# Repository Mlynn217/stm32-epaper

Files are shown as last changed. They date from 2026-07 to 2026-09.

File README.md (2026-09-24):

# stm32-epaper

An STM32-based e-reader using the Waveshare 6inch HD e-Paper HAT (IT8951 controller).

## Current Status

**Reads a real EPUB off an SD card and renders actual book pages on the physical panel.** On real
hardware, confirmed working end to end:
- STM32CubeMX → CMake → arm-none-eabi-gcc/Ninja → OpenOCD → ST-LINK build/flash/debug loop, from
  inside VSCode (tasks + launch configs for build, flash, debug, and a serial monitor)
- SPI1 communication with the IT8951 (panel resolution/FW/LUT version read back correctly, this
  panel's VCOM `-2.59V` set), the FMC/SDRAM (16MB, full read/write test passes), full-panel GC16
  grayscale refresh, and A2 (fast black/white-only partial refresh) mode
- **SD card storage** — SDIO+FatFS mount/read/write, a directory listing on every boot, and long
  filename support (`_USE_LFN=3`, heap-based — see TODO.md for why not `1`/`2`)
- **Fonts and page layout** — anti-aliased proportional bitmap fonts at reading-appropriate sizes
  (generated from a real TTF via `tools/gen_font.py`, not the tiny fixed-width fonts a low-res TFT
  would use), word-wrap, and pagination (a continuation-pointer API that can paginate arbitrarily
  long text one screen at a time without holding more than one page in memory)
- **An EPUB reader** (`Drivers/Epub/`, `Drivers/Inflate/`) — a minimal ZIP reader, a vendored
  reference DEFLATE decompressor, and tiny XML/HTML helpers, enough to parse `container.xml` → the
  OPF's manifest/spine → a chapter's XHTML → clean plain text, fed straight into the page-layout
  pipeline above. Validated against a real book (a purchased copy of *Mistborn: Secret History*) —
  see TODO.md for the debugging story, including a real FatFs/SDIO stale-read bug found and worked
  around along the way

Not done yet — see [TODO.md](TODO.md) for the full list, but the near-term highlights:
- No page-turn/chapter-navigation UI yet (currently auto-picks the first chapter with real text and
  shows up to 4 pages of it); no physical input handling
- Power management/battery life not started
- Custom PCB: the **v1 schematic is drafted in full** in `hardware/kicad/` (Power, MCU, Memory and
  Peripherals sheets). It's ERC-clean and machine-checked (pin mux, nets, footprint pads), but not
  yet reviewed by a person, and there's no PCB layout yet. v1 scope: the Waveshare HAT stays
  external on an SPI connector (see [Custom PCB (Planned)](#custom-pcb-planned))
- Custom PCB layout **started**: `hardware/kicad/stm32-epaper.kicad_pcb` has the enclosure-derived
  outline, every footprint with its nets, and the enclosure-fixed parts placed; core placement and
  routing are next. The side-wall electrode board (`hardware/electrode/`) is fully laid out and
  DRC-clean
- Enclosure: a **v0 parametric draft** in `hardware/enclosure/` (build123d). It passes its own fit
  checks and exports STEP/STL/3MF, but several dimensions are still placeholders and nothing has
  been printed (see [Enclosure](#enclosure-v0-draft))
- No license chosen yet

## Overview

Goal: a standalone, **handheld, Kindle-style** e-reader built around Waveshare's
[6inch HD e-Paper HAT](https://www.waveshare.com/6inch-hd-e-paper-hat.htm) (1448×1072, 16-level
grayscale, IT8951 controller), driven by an STM32 host. The Discovery board is a bring-up platform;
the end goal is a custom PCB — see [Custom PCB (Planned)](#custom-pcb-planned) below for the current
draft of hardware decisions for that board.

**Phase 1 host: STM32F469I-DISCO.** It has its own onboard RGB LCD, but that's not why it was
picked — it's the FMC-attached SDRAM that matters. The IT8951 needs a host-side frame buffer too
large for any STM32's internal SRAM, which is exactly why Waveshare's own reference design pairs
the IT8951 with an STM32F429 board (Open429I) that has external SDRAM bolted on. The F469-Disco
already has SDRAM on the FMC bus (normally used for its own LCD), so we get that requirement for
free. It's a bring-up/development platform for proving out the driver and architecture — the final
product host may end up being a smaller, lower-power part once the design is proven.

## Hardware

### Display: Waveshare 6inch HD e-Paper HAT

- Panel: 6", 1448×1072, black/white, 16 grayscale levels (1–4 bpp)
- Controller: IT8951 (on the HAT/driver board)
- Full refresh: <1s. Refresh power ~0.6W typ, standby ~0.3W typ
- Host interface options: SPI / I80 (parallel) / I2C / USB (USB requires an NDA with Waveshare —
  not an option for us)
- **Using SPI** — Waveshare's own recommendation ("fewer pins, easy to use"). I80 is faster but
  needs 16 data pins plus control lines, which would compete with the Discovery board's other
  onboard peripherals; I2C is too slow for meaningful refresh rates.
- Operating voltage: 5V
- Outline: 138.4×101.8×0.67mm; active display area: 122.356×90.584mm
- Viewing angle: >170°; operating temp 0–50°C, storage -25–70°C
- Each physical panel has a unique **VCOM** value printed on its FPC cable that must be set in
  firmware for correct grayscale/contrast. **This panel's VCOM is `-2.59V`** → pass `2590` (mV
  magnitude) to `EPD_IT8951_Init()`/`EPD_IT8951_SetVCOM()`.

### Host: STM32F469I-DISCO

- STM32F469NIH6 — Cortex-M4F, 2MB flash, 384KB internal SRAM
- FMC-attached SDRAM onboard (normally the framebuffer for the board's own RGB LCD) — repurposed
  here as the IT8951 frame buffer
- Onboard ST-LINK/V2-1 — no external debug probe needed

### Wiring

Final pin assignment for the F469-Disco, chosen by checking every candidate pin against the MCU's
full alternate-function list and cross-referencing everything already enabled in the `.ioc` (FMC,
DSIHOST/LTDC, I2C1/2, SAI1, SDIO, QUADSPI, USART3/6, USB_OTG_FS, TIM1) — no conflicts:

| IT8951 HAT pin | Signal | STM32 pin | Discovery connector | Pin # | Silkscreen label | Wire color |
|---|---|---|---|---|---|---|
| 5V | Power | — | CN6 (Arduino Power) | 5 | `+5V` | Grey |
| GND | Ground | — | CN6 (Arduino Power) | 6/7 | `GND` | Black |
| SCK | SPI1_SCK | PA5 | CN12 (Extension header)  | 7 | — | Orange |
| MISO | SPI1_MISO | PB4 | CN12 (Extension header)  | 5 | — | Blue |
| MOSI | SPI1_MOSI | PB5 | CN12 (Extension header)  | 9 | — | Yellow |
| CS | GPIO_Output, PP, idle high | PA4 | CN8 (Arduino Analog) | 6 | `A5` | Green |
| RST | GPIO_Output, PP, idle high | PB1 | CN8 (Arduino Analog) | 1 | `A0` | White |
| HRDY (busy) | GPIO_Input | PA2 | CN7 (Arduino Digital) | 6 | `D5` | Purple |

Notes:
- SPI1's SCK/MISO/MOSI are only broken out on **CN12**, the 16-pin 2.54mm extension header on the
  underside of the board — not on the Arduino headers. CS/RST/HRDY are split across CN8 and CN7
  instead, so wiring the HAT means jumpers from three different connectors plus CN6, not one.
- CN8 pin 6 (`A5`) defaults to PA4 via solder bridges SB10/SB12 (closed by default) — worth a
  continuity check with a multimeter before trusting it, since those can be reconfigured.
- CS/RST are push-pull, idle **high** (both signals are active-low on the IT8951 side — CS is only
  pulled low during a transaction, RST is only pulsed low as a deliberate reset, driven by the
  driver's init code rather than left low by default).
- SPI1 clock: **11.25 MHz** (APB2/8 off a 90MHz APB2 clock). The IT8951's datasheet (Table 9-4, SPI
  AC Characteristics) caps `fSCLK` at 24MHz; 11.25MHz leaves comfortable margin for jumper-wire
  wiring rather than a tightly-routed PCB. `hspi1.Init.BaudRatePrescaler` in `Core/Src/main.c` and
  `SPI1.CalculateBaudRate` in the `.ioc` are both set to match.
- HRDY (busy) is active-low (low = busy). All three IT8951-side GPIOs are currently `GPIO_NOPULL`
  (no pull-up/down) — a defensive pull-up was considered for the brief post-reset window before
  `MX_GPIO_Init()` runs, but wasn't applied; not required since these are actively driven once init
  runs, just an optional safety margin if boot-order issues ever show up.

## Custom PCB (Planned)

In progress. The KiCad project is in `hardware/kicad/`, and the **v1 schematic is drafted in full**:
Power, MCU, Memory and Peripherals sheets. PCB layout is next (see TODO.md). These are the
**current draft hardware decisions**, recorded here so context isn't lost between sessions. They're still open to change
while the schematic takes shape. The Discovery board plus the Waveshare HAT above stays the bring-up
platform until the PCB is built.

**Board scope (decided 2026-09-22):**
- **v1 PCB:** power, MCU, memory, navigation/input and the other peripherals. The **Waveshare
  IT8951 HAT stays an external module**, connected over an SPI connector, with the board supplying
  its 5 V.
- **Deferred to a later revision:** a bare IT8951 IC with its own panel PMIC (see
  [Display](#display) for what that involves).

### Input System

| Control | Component | Interface | Notes |
|---|---|---|---|
| Prev / Next page | CAP1188-1-SL (Microchip) | I²C + ALERT interrupt | 8-channel; side-wall electrodes |
| Side-wall electrodes | 2 small electrode boards (0.8 mm FR4), 2 pads each | JST-SH cable per side (J302/J303) | Pads pressed against the inside of each side wall; plastic wall as dielectric (up to ~4mm) |
| Library / menu scroll | Bourns PEC11R-4220F-S0024 | 2× GPIO (A, B quadrature) | 24 detents / 24 pulses per revolution, 20mm flatted shaft (the M7 bushing leaves too little of a 15mm shaft for the knob to grip through the front face; the Discovery bring-up used the 15mm -4215F) |
| Confirm / select | Encoder push | 1× GPIO (SW) | Built into the PEC11R (the "S" in S0024) |
| Power / wake | Alps SKRTLAE010 side-actuated tact switch | 1× GPIO (WKUP pin) | Bottom edge, on the main PCB, pressed through a flexure tab in the wall; physical, not capacitive |

Layout: cap-touch zones on left/right side walls (thumb rest). The encoder knob is on the front
face below the display (the PEC11R is vertical-mount), and the power button is on the bottom edge
next to microSD and USB-C (decided 2026-09-23, see [Enclosure](#enclosure-v0-draft)).

**Considered and set aside (open to revisiting if requirements change):**
- PSP-style analog joystick (COM-09426): analog noise, no click function, and its resistive divider
  draws current continuously, which is wrong for a device that mostly sleeps.
- On-glass bezel capacitive (ITO film): manufacturing complexity; side-wall electrode boards achieve
  the same result more simply.
- Copper tape or a flex strip for the side-wall electrodes: either works, but small rigid boards
  give repeatable pad geometry, can carry ESD parts, and cost pennies in the same PCB order (flex
  is ~10× the price for no benefit here).

### MCU, Memory & Storage

| Component | Part | Interface | Role |
|---|---|---|---|
| MCU | STM32F469IIT6 (LQFP176) | — | Same die as the Disco's F469NI, but a hand-/JLC-assemblable package instead of TFBGA216. Confirm the pin budget (FMC SDRAM + SDIO + QSPI + SPI + I²C + USB) in CubeMX before layout |
| SDRAM | IS42S16400J-6TLI | FMC 16-bit | **64 Mbit = 8 MB** (earlier notes wrongly said 16 MB; that's the Disco's chip). Plenty: ~776 KB frame buffer + the 4 MB text/EPUB buffer. Keep it, because the whole-file-in-RAM FatFs/SDIO workaround depends on it |
| QSPI NOR Flash | W25Q128JV (16 MB) | QSPI | Firmware + fonts. (N25Q128A dropped: Micron's legacy line, superseded by MT25Q) |
| microSD slot | TBD (Molex 1040310811 or GCT MSD-4-A candidates) | SDIO 4-bit | Book library (user-swappable) |

SDRAM is volatile. It does **not** replace storage; book files live on microSD.

### Display

**v1:** the Waveshare 6" HD HAT, off-board on an SPI connector. The HAT takes 5 V (from the
TPS61023 boost) and has 3.3 V SPI logic.

**Later revision: a bare IT8951 IC.** The IT8951 datasheet (`docs/IT8951_D_V0.2.4.3_20170728.pdf`)
shows this is **not** a "just run everything from 3.3 V" change (an earlier note here claimed it
was). It needs:
- **A 1.8 V core supply** (VCCK, VCC18A and VCC_SDR, each 1.8 V ±0.09 V) as well as 3.3 V for I/O and
  analog.
- **A power-up order: 1.8 V stable first, then 3.3 V, then reset released.** A 1.8 V LDO fed
  *from* 3.3 V can't meet that. One fix: feed the LDO from VSYS and switch the IT8951's 3.3 V on
  afterwards with a load switch.
- **A 12 MHz crystal, and its own SPI NOR flash** holding the panel's **waveform file**. The
  waveform is panel-specific and comes from the panel maker; the HAT ships with it in its flash.
  **Getting it is the biggest risk of going bare-IC.**
- **A TPS65185/TPS65186 panel PMIC** with its own inductors, diodes and caps (for VCOM and the
  panel's high voltages), plus the panel FPC connector.
- The IT8951 has **built-in** SDRAM (32 Mb, or 64 Mb on the -64 variants), so it needs no external
  DRAM. It's rated 0–70 °C.

### Power Architecture

**Cell chemistry: 1-cell LiPo pouch (3.7 V nominal, 4.2 V full), with a protection board.**
Switched from LiFePO4 on 2026-09-23. Small, flat LFP pouches turned out to be practically
unobtainable in the US: sample requests to overseas cell makers only. Protected LiPo pouches with
JST-PH 2.0 leads are stocked everywhere (Adafruit, SparkFun, DigiKey). What each chemistry offers:

| | LiFePO4 (previous choice) | LiPo (now) |
|---|---|---|
| Thermal runaway onset | ~270 °C | ~150 °C |
| Cycle life | 2000–3000 | ~300–500 |
| Energy density | lower | ~2× |
| Flat pouches in the US | poor | excellent |
| Discharge curve | flat (voltage says little about charge) | sloped (voltage is a usable fuel estimate) |

The safety gap is handled the way phones and e-readers handle it:
- A protected cell.
- A charger that watches cell temperature through an NTC and refuses to charge outside ~0–50 °C.
- An undervoltage cutoff.
- A sensible enclosure: leave room for the pouch to swell.

~300–500 cycles is still years of use for a reader charged every few weeks.

**Candidate cells (ordered 2026-09-23):** two EEMB protected LiPo packs with JST-PH 2.0 leads.
They share a 34.5 mm × ~52 mm outline and differ only in thickness. Figures come from EEMB's
specs: the [LP963450-PCM-LD pack spec](https://m.media-amazon.com/images/I/81dlwMxaX9L.pdf) (doc
ZJQM-RD-SPC-H1817) and the [LP603449 cell spec](https://www.eemb.com/product-147) (ZJQM-RD-SPC-H0482;
no pack-level sheet found).

| | EEMB LP603449 (pack) | EEMB LP963450-PCM-LD |
|---|---|---|
| Capacity | 1100 mAh (1000 min) | 1800 mAh (1700 min) |
| Pack envelope (max) | 6.3 × 34.5 × ~52 mm (cell body 50 mm; +PCM assumed as on the 963450) | **9.9 × 34.5 × 52 mm** |
| Weight | ~22 g | ~36 g |
| Charge | 4.20 V CC/CV, max 1C (1100 mA) | 4.2 V CC/CV, max 1C (1800 mA) |
| **Cold charging** | assumed as 963450 | **0–20 °C: ≤ 0.3C** |
| Charge temperature | 0–45 °C | 0–45 °C |
| Discharge | max 2C, cell cutoff 2.75 V | max 2C (3.6 A); pack limit 1 A continuous, 2 A for 3 s |
| Protection board (963450 spec) | assumed same family | overcharge 4.28 ± 0.05 V; **over-discharge 3.0 ± 0.1 V** (releases at 3.5 V) |
| Leads | JST-PH 2.0 | red (+) / black (−) UL1007 AWG26, **50 ± 3 mm**, JST PHR-02, from the PCM edge |
| Cycle life | ≥ 500 at 0.5C, ≥ 800 at 0.2C | ≥ 800 (min) |

**How the design fits them:**
- **Charge current:** ~296 mA (265–324 mA worst case), ≤ 0.3C of the smaller cell, so both cells are
  within spec at any charge temperature.
- **Charge timer:** 7.2–12 h, long enough for the 1800 mAh cell.
- **Cutoff order:** hardware cutoff at ~3.20 V, above the protection board's 3.0 V (firmware shuts
  down at ~3.4 V first).
- **Current:** peak draw ~0.7 A, under the pack's 1 A continuous limit.
- **Hot end:** the cells' 45 °C charging limit is handled in firmware (see the Power sheet section).

**Battery bay (enclosure input).** Size the bay for the 963450: **52 × 34.5 × 9.9 mm max, plus
~0.5 mm on each face for swelling**. Use a ~3.6 mm spacer when fitting the LP603449. Other points:
- The PCM strip and the lead exit are on one 34.5 mm edge. The 50 mm lead needs a route to J2 (keep
  J2 within ~40 mm of that edge, or allow slack).
- Keep the pouch clear of sharp edges and screw bosses.
- RT1 (the charger's NTC) is a leaded Murata NXFT15XH103 soldered to pads on the PCB, with its head
  taped to the pouch (the cell sits beside the PCB, not over it).
- **Polarity isn't shown by pin in EEMB's drawings** (only red = +). Check J2 pin 1 = + with a meter
  before plugging a cell in.

**Power tree, v1 (external Waveshare HAT):**
```
USB-C VBUS ──► BQ24073 charger + power path ──► VSYS (4.4V regulated with USB; = cell on battery)
                      └──► LiPo cell (3.0–4.2V)          4.2V CV, NTC-qualified, ~500mA
VSYS ──► TPS63802 buck-boost → 3.3V                        STM32, SDRAM, QSPI, microSD, CAP1188, encoder, buttons
           └── EN = VSYS divider: OFF < ~3.20V, ON > ~3.52V (undervoltage cutoff)
VSYS ──► TPS61023 boost → 5V                               external Waveshare HAT (MCU-enabled)
cell ──► MCP1700 3.0V LDO → MCU VBAT                       RTC backup
cell ──► 1M/1M divider → PA3 (ADC)                         firmware battery measurement
```

**Battery protection (undervoltage).** The charger only charges; it does **nothing** to stop
over-discharge. Protection is layered:
1. **Firmware (primary).** Measure the cell on `VBAT_SENSE` (PA3, 1M/1M divider, ~2 µA). At about
   3.4 V under light load, shut down gracefully: save state, leave a "please charge" screen on the
   e-ink (it holds with no power), then enter standby. LiPo's sloped curve makes this voltage a
   reasonable fuel estimate too.
2. **Hardware backstop.** The TPS63802's EN pin has a precise threshold (1.10 V rising / 1.00 V
   falling). A 2.2 MΩ/1.0 MΩ divider from VSYS turns the 3.3 V rail off below ~3.20 V and back on
   above ~3.52 V (±3%), costing ~1.1 µA. This catches a hung firmware or a drain during sleep.
3. **Cell protection board (required).** Buy only protected cells. The protection board is the
   only thing that truly disconnects the cell (typically ~2.5–3.0 V), and it also handles shorts
   and overcurrent.

**Sleep current:** the regulator's own draw is now ~11 µA (TPS63802), down from ~50 µA for the
TPS63070 it replaced. Total design floor ≈ 11 µA (TPS63802) + ~1.1 µA (cutoff divider) + ~2 µA
(battery sense divider) + ~1.6 µA (RTC LDO) + ~2.4 µA (MCU standby) + CAP1188 (5 µA deep sleep,
~50 µA if it watches for a touch). That's with the peripheral rail switched off; keeping the SDRAM
in self-refresh instead adds ~2 mA max.

**Peripheral load switch: fitted on v1** (decided 2026-09-23).
- **What it does:** a TPS22965 gates `3V3_PERIPH` (SDRAM, QSPI flash, microSD). Without it those
  parts stay powered in STANDBY, a ~2–20 mA idle floor (~70 mAh/day). With it, idle is ~0.5–2 mAh/day,
  which means months on the shelf.
- **Firmware policy:** STOP with SDRAM self-refresh between page turns; STANDBY with the peripheral
  rail off after a few minutes idle, reloading the book from SD on wake.

**Still reserved for v2** (target < 10 µA): a **TPS63900** nanopower buck-boost (75 nA quiescent)
as an always-on `3V3_AON` rail for the MCU and CAP1188. It replaced the earlier MAX17222 idea: that
part is boost-only and can't bring a full cell down to 3.3 V. It's an unpopulated footprint on v1,
with `3V3_AON` fed from +3V3 through a fitted 0Ω link.

### Connectivity & Debug

| Component | Part | Notes |
|---|---|---|
| USB-C connector | GCT USB4105-GF-A | Charging + USB FS data to the MCU (DFU/CDC). *Not* SWD: USB can't carry SWD on its own |
| ESD protection | USBLC6-2SC6 (SOT-23-6) | On USB-C D+/D− and VBUS |
| SWD debug header | TC2050-IDC (Tag-Connect) | No pins on the production board |
| Battery connector | JST-PH 2.0 2-pin | Pin 1 = +. Lead polarity isn't standardised across LiPo vendors, so check against the actual cell before plugging it in |
| Waveshare HAT connector | TBD (peripheral sheet) | SPI + HRDY + RST + 5V + GND |

### Clocks & Passives

| Component | Value / Part | Notes |
|---|---|---|
| HSE crystal | 8MHz NDK NX3225GD-8MHZ-STD-CRA-3 (CL 8pF), 2 × 10pF C0G | PLL source → 180MHz system clock |
| RTC crystal | 32.768kHz NDK NX3215SA-32.768KHZ-EXS00A-MU00525 (CL 6pF, ESR ≤ 70kΩ), 2 × 6.2pF C0G | AN2867 gm_crit ≈ 0.58 µA/V: confirm against the F469 datasheet's LSE Gm_crit_max; the LSE high-drive mode (LSEMOD) is the fallback |
| Decoupling caps | 100nF + 10µF per supply pin | Standard STM32 layout |
| I²C pull-ups | 4.7kΩ to 3.3V | For I²C bus (CAP1188, fuel gauge) |
| Ferrite bead | Optional | Between analog and digital GND if needed |

### Power Sheet (drafted in KiCad)

`hardware/kicad/power.kicad_sch` implements the v1 power tree above. Details decided while drawing
it:

- **Charger: TI BQ24073** (SLUS810N), 1-cell Li-ion with a built-in power path:
  - **Power path:** `OUT` (= VSYS) is regulated to 4.4 V while USB is present, which keeps the
    5.5 V-max TPS63802 and TPS61023 safe. The battery supplements OUT when the load exceeds the
    input limit. This replaced the earlier discrete load-sharing FET and Schottky diode.
  - **Charge current:** R_ISET = 3.01k → 890/3.01k ≈ **296 mA** (265–324 mA worst case). That's
    ≤ 0.3C for the 1100 mAh cell, EEMB's limit for charging at 0–20 °C, so either candidate cell is
    in spec at any temperature. If the 1800 mAh cell is chosen for good, 500 mA (1.78k) would
    still be within its 0.3C cold limit.
  - **Safety timer:** R_TMR = 72k → 7.2–12 h fast-charge timer (the default 4–6 h would expire
    while charging the 1800 mAh cell at ~300 mA). Pre-charge timer 43–72 min.
  - **Input current:** EN2 = 0, EN1 = 1 (pulled up to VBUS) → **USB500**, the USB-C default,
    because the board doesn't read the source's CC advertisement. R_ILIM = 1.54k (1.0 A) must be
    fitted anyway: an open ILIM disables charging.
  - **Temperature:** TS goes to a **10k NTC on leads** (Murata NXFT15XH103, same curve as the
    NCP15XH103 it replaced), soldered to the PCB with its head taped to the cell, because
    off-the-shelf LiPos have no thermistor lead and the cell sits beside the PCB. The charger
    blocks charging outside ~0–50 °C.
  - **The cells only allow 0–45 °C.** TI's resistor network (SLUS810N eq. 8–9) can only *widen*
    the window: a 3–43 °C window needs an NTC whose resistance ratio between those temperatures
    is ≥ 7, and 10k NTCs with B ≈ 3380–3435 only reach ~4.7–4.8. So the hot end is enforced in
    firmware:
    - `TS_SENSE` (TS through 10k/100 nF) goes to PC1 (ADC1_IN11). While charging,
      V_TS = 75 µA × R_NTC.
    - `CHG_DIS` drives CE from PD6, with a 100k pull-down so charging stays enabled while the MCU
      is off or booting. Firmware suspends charging between ~43 °C and the IC's own ~50 °C cutoff.
  - **Other pins:** TD low (termination on). PGOOD unused; VBUS sensing is on PA9 instead.
- **Charge status:** a red LED from VBUS to CHG (works with the MCU off), plus `CHG_STAT` to the MCU.
  That must go to a 5V-tolerant (FT) pin, because the LED path lets the line float up toward
  VBUS.
- **USB-C:** sink-only (5.1k Rd on each CC). A USBLC6-2SC6 protects D+/D−, which go to the MCU as
  `USB_DP`/`USB_DM` (OTG_FS).
- **TPS63802 → +3V3:** 511k/91k feedback → 3.308 V. MODE low (power-save mode). EN comes from the
  undervoltage divider R6/R15 described above, and nothing else: "off" is MCU STANDBY, woken by
  the power button on WKUP (decided 2026-09-23; see TODO.md for the standby budget and the
  low-battery boot rule).
- **TPS61023 → +5V (external HAT):** 732k/100k → 4.99 V. EN is `EPD_5V_EN` from the MCU, with a 1M
  pull-down. It truly disconnects in shutdown, so the HAT is fully unpowered until enabled.
- **RTC:** cell → MCP1700 3.0 V LDO (1.6 µA quiescent) → `VBAT_RTC`. A full LiPo (4.2 V) minus a
  Schottky drop would still exceed the VBAT pin's 3.6 V max. Below ~3.2 V the LDO drops out and
  VBAT follows the cell (VBAT minimum is 1.65 V).
- **Battery sense:** 1M/1M from the cell → `VBAT_SENSE` (100 nF) → PA3 / ADC1_IN3, for the firmware
  cutoff and fuel estimate.
- **Peripheral load switch (fitted):** TPS22965 (U4) from +3V3 to `3V3_PERIPH`.
  - ON = `PERIPH_EN` (PD7) with a 100k pull-down, so the rail is off at reset and switches off by
    itself in STANDBY (the GPIO goes high-impedance).
  - CT = 1 nF, rated 25 V (the CT pin can reach 12 V) → ~1.3 ms rise → ~50 mA inrush into ~21 µF of
    downstream decoupling, so +3V3 doesn't dip.
  - The built-in 225 Ω quick-discharge pulls the rail down when off. R13 (0 Ω bypass) is DNP,
    kept as a fallback.
  - **Firmware:** raise `PERIPH_EN` before the FMC/QSPI/SDIO init. Before dropping it, set those
    pins to analog or low so the MCU doesn't back-power the unpowered parts. After re-enabling,
    re-run the SDRAM JEDEC init sequence and re-mount the SD card.
- **Reserved, DNP:** TPS63900 always-on rail, CFG3 = 16.2k → 3.3 V. `3V3_AON` is fed from +3V3
  through the fitted 0Ω R18 on v1. **The MCU sheet powers the MCU and CAP1188 from `3V3_AON`**, so v2
  only needs a BoM change.
- **Off-sheet connections:** signals leaving the sheet are global labels: `USB_DP`, `USB_DM`,
  `CHG_STAT`, `CHG_DIS`, `TS_SENSE`, `3V3_PG`, `EPD_5V_EN`, `VBAT_RTC`, `VBAT_SENSE`, `PERIPH_EN`. Rails are power symbols: `VBUS`,
  `VSYS`, `+BATT`, `+3V3`, `+5V`, `3V3_AON`, `3V3_PERIPH`, `GND`.

### MCU, Memory and Peripherals Sheets (drafted in KiCad)

**Pin assignment.** It lives in one place: `PINMAP` in `hardware/scripts/sheet_mcu.py`. It follows
the F469-Disco wherever a peripheral carries over, so the existing CubeMX config and firmware keep
working:

| Function | Pins | Notes |
|---|---|---|
| FMC SDRAM (bank 1) | Disco's pins, D0–D15 only | **16-bit here (Disco: 32-bit)**, so the FMC init needs a 16-bit data width |
| QUADSPI bank 1 | PF6–PF10, PB6 | Same as the Disco |
| SDIO 4-bit | PC8–PC12, PD2 | Same as the Disco. **Card detect moved PG2 → PG10** (PG2 would share interrupt line EXTI2 with HRDY on PA2) |
| HAT: SPI1 + control | PA5/PB4/PB5, CS PA4, RST PB1, HRDY PA2 | Exactly today's wiring. `EPD_5V_EN` (the HAT's 5 V) is PB0 |
| USART3 (serial log) | PB10 TX / PB11 RX | Same as the Disco's ST-LINK VCP, so the same log UART |
| I²C1 (CAP1188) | PB8/PB9 | ALERT# on PB7 (EXTI7), RESET on PB12 |
| Encoder | TIM3 CH1/CH2 on PA6/PA7 (encoder mode) | Switch on PD3 (EXTI3) |
| Power button | PA0 = WKUP | Wakes from standby on a **rising** edge, so the button pulls up |
| Power-sheet signals | CHG_STAT PD4, 3V3_PG PD5, PERIPH_EN PD7 | |
| Battery sense | PA3 = ADC1_IN3 (`VBAT_SENSE`) | 1M/1M divider from the cell |
| Charger thermistor / charge disable | PC1 = ADC1_IN11 (`TS_SENSE`), PD6 (`CHG_DIS`) | Firmware enforces the cells' 45 °C charging limit |
| USB OTG FS | PA11/PA12, VBUS sense PA9 through 1k | |
| Debug | SWD PA13/PA14, SWO PB3 | Tag-Connect TC2050-IDC-NL pads, pinned 1:1 like the standard ARM 10-pin connector |
| Status LED | PG6 | |

All 86 assigned pins were checked in two ways: automatically against the KiCad symbol's
alternate-function list, and by hand against the LQFP176 pin table in ST's DS11189. Every signal
that can see more than 3.3 V (VBUS sense, CHG_STAT) is on a 5V-tolerant (FT) pin.

**MCU support circuitry** (per DS11189 Fig. 24 and §2.18):
- **Decoupling:** 100 nF on each of the 13 VDD pins plus 4.7 µF; 100 nF on VDDUSB.
- **Analog supply:** VDDA and VREF+ are tied together, fed through a ferrite bead, with 1 µF + 100 nF
  each.
- **Core regulator:** 2.2 µF (ESR < 2 Ω) on each of VCAP1/VCAP2. PDR_ON is high and BYPASS_REG low.
- **DSI unused:** VDDDSI to VDD, VCAPDSI tied to VDD12DSI with no capacitor, VSSDSI to GND.
- **Clocks:** 8 MHz HSE and 32.768 kHz LSE. The load caps assume CL = 10 pF and 6 pF crystals;
  recheck them for the actual parts.
- **Boot:** BOOT0 has a 10k pull-down plus a **BOOT button** to 3.3 V. Hold it at reset to enter the
  ROM USB DFU bootloader. BOOT1 (PB2) is pulled low.
- **Supply rail:** the MCU runs from `3V3_AON`, so a v2 always-on rail is only a parts-list change.

**Memory** (all on `3V3_PERIPH`):
- IS42S16400J SDRAM with 100 nF per supply pin plus 10 µF.
- W25Q128JV QSPI flash, with a 10k pull-up on /CS.
- Molex 104031-0811 microSD socket: 47k pull-ups on CMD and DAT0–3, and 10 µF + 100 nF for
  hot-insertion inrush. The detect switch is pulled up to `3V3_AON`, so detection still works with
  the peripheral rail off.

Net names are the STM32 alternate-function names (`FMC_A3`, `SDIO_D0`, …), which lets the checker
confirm each memory pin reaches an MCU pin that really provides that function.

**Peripherals:**
- **HAT connector:** 1×8 2.54 mm header (1 +5V, 2 GND, 3 SCK, 4 MOSI, 5 MISO, 6 CS, 7 RST, 8 HRDY),
  with 33 Ω series resistors on SCK, MOSI and CS. **Firmware rule:** while `EPD_5V_EN` is low (HAT
  unpowered), drive SCK/MOSI/CS/RST low or leave them floating. Otherwise the MCU back-powers the
  IT8951 through its I/O clamp diodes. R316 (100k) pulls HRDY low so it reads "busy" rather than
  floating while the HAT is off.
- **CAP1188:** I²C address 0x29 (150k on ADDR_COMM, the same as the Adafruit breakout), CS1–4 to two
  JST-SH 3-pin connectors (J302 left, J303 right: touch / GND / touch) that cable to the side-wall
  electrode boards, with U302 (TPD4E05U06, 0.5 pF/line) as ESD protection on all four lines;
  unused inputs and LED pins to GND.
- **PEC11R encoder:** Bourns' suggested filter on each channel (10k pull-up, 10k series, 10 nF), and
  mounting lugs to GND.
- **Power button:** Alps SKRTLAE010 (side-actuated) on the bottom edge; pulls PA0 up, with a 100k
  pull-down.
- **Everything user-facing runs from `3V3_AON`.**

**Custom library parts:** symbols in `hardware/kicad/epaper.kicad_sym` and footprints in
`hardware/kicad/epaper.pretty`, each citing its datasheet:
- **TPS63802 (DLA0010A):** TI land pattern, including the split paste on the GND bar.
- **Bourns PEC11R-4xxxF-S:** the Alps EC11E footprint does *not* fit (its tabs are 11.2 mm apart vs
  13.2 mm).

### Checking the Schematic

```sh
KICAD_SYMBOL_DIR=<kicad share>/symbols python3 hardware/scripts/check_schematic.py
```

This runs ERC and a netlist export, then checks:
1. The Power sheet's nets against an expected table.
2. Every MCU pin: its net and its required alternate function.
3. Memory buses end to end.
4. No net with a single connection (catches label typos).
5. Every connected pin exists as a pad on its footprint.

ERC alone isn't enough: it missed a real VSYS↔+3V3 short in the first draft (see TODO.md).

### Enclosure (v0 draft)

A parametric model in `hardware/enclosure/`, written as build123d Python code so it can be built and
checked headless like the rest of the repo. [hardware/enclosure/README.md](hardware/enclosure/README.md)
covers the design, how to build and view it, what to order, and the open items. In short:
- **106.8 × 171.4 × 17.8 mm**, portrait. The panel's FPC is at the top, folding back to the HAT.
  Below the HAT: the battery on the left, then the main PCB as a full-width 60 mm strip along the
  bottom.
- **The encoder knob comes out of the front face, in a 24 mm chin below the display.** The
  PEC11R is a vertical part, so it can't come out of the bottom edge while the PCB lies behind the
  panel. USB-C, microSD and the power button (a side-actuated switch under a flexure tab) are in
  the bottom wall.
- **The side-wall touch electrodes are two small boards** pressed against the inside of the side
  walls in printed channels, cabled to the main PCB.
- It's printed by a service (Craftcloud or similar), in **MJF/SLS nylon PA12**. Four parts: front
  shell, panel backer, back cover and knob, closed with M2 heat-set inserts.
- `build.py` runs fit checks (pairwise interference, wall rules, plug/card openings, knob
  engagement). It also exports the **PCB outline (DXF, for Edge.Cuts)** and a placement JSON
  (encoder axis, connector positions, height limits). **The enclosure defines the board outline**,
  not the other way round.

### Full System Block Diagram (v1)

```
USB-C ──VBUS──► BQ24073 (charger + power path) ◄──► LiPo cell
                     └──► VSYS ──► TPS63802 ──3.3V──► STM32F469IIT6
                                                   ├──────────────► IS42S16400J  (FMC, 8 MB)
                                                   ├──────────────► W25Q128JV    (QSPI)
                                                   ├──────────────► microSD slot (SDIO)
                                                   ├──────────────► CAP1188      (I²C)
                                                   ├──────────────► Encoder      (GPIO)
                                                   └──────────────► Power btn    (WKUP)
VSYS ──► TPS61023 ──5V──► HAT connector ──► external Waveshare IT8951 HAT ──► 6" panel
STM32F469 ◄──SPI──────────► HAT connector
cell ──► Schottky ──► MCU VBAT (RTC backup + battery measurement)
STM32F469 ◄──SWD── TC2050 pads
USB-C D+/D− ──► STM32F469 OTG_FS
```

**Known gotcha:** the charger voltage must match the chemistry. The BQ24073 (4.2 V) is correct for
LiPo. If the design ever goes back to LiFePO4, the charger must change too (3.6 V; the earlier
design used an MCP73123). A 4.2 V charger on an LFP cell, or a 3.6 V one on LiPo, is wrong.

## Architecture / Approach

- **STM32CubeMX** for pin mux, clock tree, and FMC/SDRAM configuration — exporting a **CMake**
  toolchain project (not a Keil or STM32CubeIDE project file)
- **Build**: CMake + Ninja + arm-none-eabi-gcc
- **Editor/debug**: VSCode, using the CMake Tools and Cortex-Debug extensions (OpenOCD or
  STM32CubeProgrammer's ST-Link GDB server against the onboard ST-LINK/V2-1)
- **IT8951 driver**: vendored and adapted from Waveshare's reference implementation
  ([github.com/waveshare/IT8951-ePaper](https://github.com/waveshare/IT8951-ePaper)), specifically
  their **Raspberry Pi** driver (`Raspberry/lib/e-Paper/EPD_IT8951.c/h`) rather than their STM32 demo
  — the STM32 demo (targets Keil MDK on their Open429I board anyway) turned out to only actually
  implement **I80** mode; its `IT8951_Interface_SPI` `#define` is vestigial and never referenced in
  the code. The Raspberry Pi driver is genuinely SPI-based (matches our chosen interface) and is
  pure protocol logic on top of a small hardware-abstraction layer (`DEV_Config.c/h`), so only that
  thin layer needed rewriting for STM32 HAL — `EPD_IT8951.c/h` is vendored essentially unchanged.
  Lives at `Drivers/IT8951/` (`e-Paper/` = vendored protocol driver, `Config/` = our HAL port of
  `DEV_Config`).
- **Fonts**: `Drivers/Fonts/` has two font formats side by side — the plain fixed-width, bilevel
  `sFONT` tables (vendored from ST's BSP Fonts module, still used for a couple of test strings) and
  a custom anti-aliased proportional format generated by `tools/gen_font.py` (rasterizes a real TTF
  via Pillow, quantizes to the panel's 16 gray levels) — see `EPD_FontAA.h`/`EPD_Text.c`. Page
  layout (word-wrap + pagination) is `EPD_Layout.c/h`.
- **EPUB reading**: `Drivers/Epub/` (ZIP reader, tiny XML/HTML helpers, EPUB orchestration) plus
  `Drivers/Inflate/` (vendored DEFLATE decompressor) — see TODO.md for how this was built and
  validated (native test harness first, then real hardware).
- FreeRTOS (CMSIS-RTOS v1 API, `cmsis_os.h`) — a single application task (`StartDefaultTask` in
  `Core/Src/main.c`) does all the work; kept mainly because CubeMX's F469-Disco board template
  defaults to it and it built/booted cleanly as-is, not because concurrency is needed yet
- Whenever the `.ioc` changes (new pin, new peripheral), regenerate in CubeMX — it only touches its
  own generated blocks, so hand-written application code (in `USER CODE BEGIN/END` blocks) survives.
  CubeMX regeneration has, more than once, silently reverted hand-tuned settings in generated code
  (e.g. the SPI1 clock prescaler) — `scripts/patch-cubemx.sh` re-applies known cases automatically
  at every `cmake` configure as a safety net; if you hand-tune something in CubeMX-generated code,
  add a check there too.

## Development Environment Setup

Status of this machine: STM32CubeMX is already installed (`~/STM32CubeMX`); VSCode is installed but
still needs the `arm-none-eabi-gcc` toolchain, OpenOCD, Ninja, and the relevant extensions — see
[TODO.md](TODO.md).

1. Install `arm-none-eabi-gcc`, `ninja`, and `openocd`
2. Install VSCode extensions: `ms-vscode.cmake-tools`, `ms-vscode.cpptools`, `marus25.cortex-debug`
3. Open STM32CubeMX, create a project for the STM32F469I-DISCO board (not just the MCU, so pin
   defaults for onboard peripherals are pre-populated), enable FMC/SDRAM + SPI, set Toolchain/IDE
   to **CMake**, generate code
4. Open the generated project folder in VSCode; configure/build with CMake Tools; flash/debug with
   Cortex-Debug

## Repo Layout

- `stm32-epaper.ioc` — STM32CubeMX project (source of truth for pins/clocks/peripherals)
- `Core/`, `Drivers/STM32F4xx_HAL_Driver/`, `Drivers/CMSIS/`, `Middlewares/`, `FATFS/`, `USB_HOST/` —
  CubeMX-generated HAL/CMSIS/FreeRTOS/FatFS/USB Host scaffolding (regenerated by CubeMX; hand-written
  code lives in the `USER CODE BEGIN/END` blocks within, which survive regeneration)
- `Drivers/IT8951/` — vendored + adapted IT8951 SPI driver (see Architecture above)
- `Drivers/Fonts/` — bitmap fonts (plain + anti-aliased) and the text/page-layout drawing code
- `Drivers/Epub/`, `Drivers/Inflate/` — EPUB reader (ZIP + XML/HTML) and its DEFLATE decompressor
- `tools/gen_font.py` — regenerates the anti-aliased fonts in `Drivers/Fonts/` from a TTF/OTF
- `scripts/patch-cubemx.sh` — self-heals known CubeMX regeneration regressions (see Architecture)
- `cmake/`, `CMakeLists.txt`, `CMakePresets.json` — CubeMX's CMake export + our toolchain file
- `.vscode/` — `tasks.json` (build/flash/serial-monitor), `launch.json` (debug via OpenOCD or J-Link,
  plus a `node-terminal` entry for the minicom serial monitor), `c_cpp_properties.json`,
  `extensions.json`
- `hardware/kicad/` — KiCad 10 project for the custom PCB:
  - `stm32-epaper.kicad_pro` and the root sheet, plus `power`, `mcu`, `memory` and `peripherals`
    `.kicad_sch`.
  - `epaper.kicad_sym` and `epaper.pretty/`: project-local symbols and footprints for parts not in
    KiCad's stock libraries, each transcribed from the datasheet it cites.
- `hardware/scripts/`:
  - `gen_schematic.py`: a one-shot generator that bootstrapped every sheet, from `common.py` plus
    one `sheet_*.py` per sheet. It refuses to overwrite without `--force`. Once a sheet is edited
    in Eeschema, the `.kicad_sch` is the source of truth.
  - `gen_footprints.py`: the project footprints.
  - `check_schematic.py`: design-intent checks (see "Checking the Schematic"). Keep its tables in
    sync with deliberate edits.
  - `gen_main_pcb.py`: one-shot bootstrap of the main board (outline from the enclosure, all
    footprints with nets, enclosure-fixed parts placed). Runs under KiCad's bundled Python:
    `kicad python3.11 hardware/scripts/gen_main_pcb.py <netlist.xml>` (see its docstring). It
    refuses to overwrite the board without `--force`.
- `hardware/electrode/`: KiCad project for the side-wall electrode board (one design, two
  fitted), generated from the enclosure's `params.py`:
  `KICAD_SYMBOL_DIR=<kicad share>/symbols python3 hardware/scripts/gen_electrode.py --force`, then
  `kicad python3.11 hardware/scripts/gen_electrode_pcb.py` (KiCad's bundled Python, which has
  pcbnew). Check with `kicad-cli pcb drc --schematic-parity --refill-zones`.
- `hardware/enclosure/`: the parametric enclosure (build123d): `params.py` (every dimension, with
  its source), `model.py`, `checks.py`, `build.py` (checks + STEP/STL/3MF/DXF export + renders to
  the git-ignored `out/`), `show.py` (OCP CAD Viewer). See its README.
- `docs/` — IT8951 datasheet + programming guide, F469-Disco user manual (UM1932)
- `TODO.md` — task list/roadmap

## Building / Flashing / Debugging

**Command line:**
```sh
cmake --preset Debug
cmake --build --preset Debug
openocd -f interface/stlink.cfg -f target/stm32f4x.cfg \
  -c "program build/Debug/stm32-epaper.elf verify reset exit"
```

**VSCode:** Terminal → Run Task → `Build (Debug)` or `Flash (OpenOCD / ST-LINK)` (the latter builds
first automatically), or use the Run and Debug dropdown for `Debug (OpenOCD / ST-LINK)` /
`Debug (J-Link)`. `Serial Monitor (minicom)` is available both as a task and in the Run and Debug
dropdown — it opens `/dev/ttyACM0` at 115200 baud (the ST-LINK's virtual COM port, wired to USART3)
in an integrated terminal. Exit minicom with `Ctrl-A` then `X`.

Debugging needs `gdb-multiarch` (`arm-none-eabi-gdb` isn't packaged separately on this Ubuntu
version) — see [TODO.md](TODO.md).

## TODO

See [TODO.md](TODO.md) for the current task list and roadmap.

## License

None yet — all rights reserved until a license is chosen.

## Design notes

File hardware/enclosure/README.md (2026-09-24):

# Enclosure

Parametric enclosure model in [build123d](https://build123d.readthedocs.io/) (Python on the
OpenCascade kernel). **Status: v0 draft**. It builds, passes its own fit checks and exports print files,
but several inputs are still placeholders (see below). It hasn't been printed or reviewed by a person.
Don't order parts from it yet.

## Running it

One-time setup (a venv outside the repo):
```sh
python3 -m venv ~/.venvs/cad && ~/.venvs/cad/bin/pip install -r hardware/enclosure/requirements.txt
```
Build (about 30 s; about 10 s with `--no-render`):
```sh
~/.venvs/cad/bin/python hardware/enclosure/build.py
```
This prints the outer size, the weight of each part, every fit check and every placeholder
dimension. It exits non-zero if a check fails. It writes to `hardware/enclosure/out/`, which is
git-ignored (regenerate the files rather than committing them):

| File | What it's for |
|---|---|
| `<part>.step` | Upload to the print service (preferred). Also opens in FreeCAD for editing |
| `<part>.stl`, `<part>.3mf` | Mesh versions, if a service wants them |
| `assembly.step` | Everything, including the bought-in parts, coloured and named. For viewing, and for KiCad's 3D viewer |
| `pcb_outline.dxf` | Main PCB outline with mounting holes. KiCad: *File → Import → Graphics*, layer Edge.Cuts |
| `pcb_placement.json` | Where the enclosure needs things on the PCB: encoder axis, USB-C and microSD on the edge, holes, height limits, battery and electrode zones |
| `electrode_board.json` | The side electrode board design: size, pad rectangles, connector position and pinout |
| `render_*.png` | Headless previews: front, interior, exploded, bottom edge, section |

**Viewing:**
- **Just the files:** open `out/assembly.step` (or any per-part `.step` or `.stl`) in a desktop
  viewer: F3D (`sudo apt install f3d`, lightweight), FreeCAD (can also edit), or Open Cascade's CAD
  Assistant.
- **Live from the code:** `show.py` sends the model over a local websocket to a separate viewer
  app, and each re-run updates the open view. Start the viewer with
  `~/.venvs/cad/bin/python -m ocp_viewer` and open http://127.0.0.1:3939/viewer (or use VSCode's
  **OCP CAD Viewer** extension pane instead). Then run
  `~/.venvs/cad/bin/python hardware/enclosure/show.py` (add `printed` to show only the printed parts).

## Files

- `params.py`: **every dimension**, each tagged `DOC` (from a datasheet or the README), `PH`
  (placeholder: measure before ordering) or `DC` (design choice). Change the design here.
- `model.py`: geometry. Envelopes of the bought-in parts (for checking) and the four printed parts.
- `checks.py`: fit checks. Pairwise interference between all parts and envelopes, wall rules, knob
  engagement and clearance, openings that admit a real USB-C plug and a microSD card, and the
  battery lead's reach.
- `build.py`, `render.py`, `show.py`: build and export, PNG renders, interactive viewer.

## The v0 design

| | Choice | Why |
|---|---|---|
| Outline | 106.8 × 171.4 × 17.8 mm (+4.6 mm knob), ~80 g printed | Panel + 2.2 mm walls, 4 mm top border, 24 mm chin |
| Orientation | Portrait, panel **FPC at the top** | The FPC folds straight back to the HAT. Firmware rotates the image 180° |
| Stack (front→back) | Bezel 1.4 · panel · backer plate 1.5 · 12.3 mm cavity · back 1.6 | The cavity is set by the tallest single item. Today that's the HAT with its Pi header (placeholder 12 mm) |
| Cavity layout | HAT at the top, battery at the left below it, main PCB a full-width 60 mm strip at the bottom | Nothing stacks on anything else. Thickness = the deepest single part |
| Encoder | Knob on the **front face, in the chin** | The PEC11R is a vertical part (shaft normal to the PCB). With the PCB behind the panel, the shaft points out the front, not the bottom edge. The knob's hub reaches through the front face so it grips 7.7 mm of shaft |
| USB-C, microSD | Bottom wall at x = +25 / −25 mm | Either side of the encoder. The USB opening admits a USB-IF maximum-size plug overmold (12.4 × 6.5 mm) |
| Power button | Bottom edge, x = −40 mm: an Alps SKRTLAE010 side-actuated switch on the PCB edge, pressed through a **flexure tab** in the wall (U-shaped slot, tab thinned to 1.2 mm, nub 0.1 mm off the plunger) | Keeps the switch on the main PCB; PA12 makes a durable living hinge, so there is no separate button part |
| Electrodes | 2 zones per side (25 mm tall), marked by 0.4 mm thumb dimples. The side wall is 2.2 mm (1.8 at the dimples). The pads are on **two identical 74 × 10 mm electrode boards** (0.8 mm FR4), pads facing the wall, slid into printed channels at each end and held by the back cover. A JST-SH cable runs to J302/J303 on the main PCB | README allows ≤ ~4 mm of plastic. The main PCB and the battery sit 2.5 mm in from the side walls to make room |
| Parts | Front shell, panel backer, back cover, knob | Back cover: 4 × M2 screws into heat-set inserts (Ø3.2 mm holes) in the shell's bosses. PCB: 4 × M2 thread-forming screws into standoffs on the back cover. Battery: L-shaped corner rails, sized for the 963450 + swell |
| Panel retention | Bezel ribs locate the panel and backer. The top bosses clamp the backer | Also stick the panel to the bezel with thin double-sided tape, as commercial e-readers do |

## Ordering (Craftcloud or similar)

- **Material: MJF (or SLS) nylon PA12**, dyed black. It's strong, snap-tolerant, needs no support
  marks, holds ~1 mm walls, and works as the electrode dielectric. The knob could also be SLA resin
  for a smoother finish.
- Upload the `.step` files, one per part. Tolerances assume a typical MJF service (±0.3 mm).
- Hardware: 4 × M2 heat-set inserts (3.2 mm OD, ~3 mm long), 4 × M2×6 screws (back cover),
  4 × M2×5 thread-forming screws (PCB), thin double-sided tape for the panel, 2 × JST-SH 3-pin
  cables (~50 mm, both ends SHR-03V-S), and 2 electrode boards (order with the main PCB).
- Before paying for the full set, consider ordering only the front shell's **chin section** (or the
  whole shell alone) as a fit check against the real panel, encoder and connectors.

## Open items (resolve before ordering)

1. **Measure the placeholders** (`PH` in `params.py`; `build.py` lists them): the panel's
   active-area offset, FPC width/bend and **thickness** (Waveshare says 0.67 mm, ED060KD1 listings
   1.6 mm), and the HAT's size and height. The part dimensions come from datasheets.
2. **Knob height:** 7.9 mm proud, set by the PEC11R's M7 bushing (13.5 mm above the PCB on the
   20 mm-shaft part) plus the 0.8 mm worst-case push travel. Cutting the shaft down later would
   lower it, at the cost of grip.
3. **Panel active-area position:** the window is centred on the panel. If the real active area is
   offset (usually away from the FPC edge), set `ACTIVE_DX/DY`.
4. **Electrode board KiCad project** (see TODO.md): the geometry is in `out/electrode_board.json`.

Decided 2026-09-23: keep the HAT's 2×20 Pi header for v1 (it sets the cavity depth, ~1.1 mm more
than the battery would); power button on the bottom edge; electrodes on small boards; knob on the
front face; RT1 as a leaded NTC taped to the pouch.

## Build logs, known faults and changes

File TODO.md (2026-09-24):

# TODO

### Documentation / Planning
- [x] Document hardware choice & rationale
- [x] Confirm final GPIO pin mapping for SPI + control lines (avoid conflicts with the Discovery
      board's onboard LCD/SDRAM/USB/camera pins) — SCK/PA5, MISO/PB4, MOSI/PB5, CS/PA4, RST/PB1,
      HRDY/PA2; documented in README with physical connector/pin (CN12/CN8/CN7/CN6)
- [x] Record this panel's VCOM value once hardware arrives — `-2.59V` (see README, Display section)
- [ ] Decide on a license

### Environment / Tooling
- [x] Install `arm-none-eabi-gcc` toolchain
- [x] Install OpenOCD for ST-Link debugging
- [x] Install Ninja
- [x] Install VSCode extensions: CMake Tools, C/C++, Cortex-Debug
- [x] Generate STM32CubeMX project (`.ioc`) for STM32F469I-DISCO, targeting the CMake toolchain
  - [x] FMC/SDRAM present in the board template (CAS latency 3, burst read enabled) — configured,
        not yet exercised with an actual read/write test (see firmware TODO below)
  - [x] Configure SPI peripheral + GPIOs for IT8951 control lines (CS/RST/HRDY) — SPI1 Full-Duplex
        Master, Mode 0, software NSS, prescaler `/8` (11.25MHz, under the IT8951's 24MHz max per
        its datasheet); CS/RST push-pull idle-high, HRDY input; all builds/flashes clean
  - [x] Validated end-to-end on physical hardware: `cmake --preset Debug` + `cmake --build` produces
        `stm32-epaper.elf`, OpenOCD (`interface/stlink.cfg` + `target/stm32f4x.cfg`) flashes and
        verifies it over the onboard ST-LINK/V2.1, and the board runs post-reset with the FreeRTOS
        scheduler started (PC in flash, PSP in use, no fault) — decided to keep FreeRTOS + the full
        board demo peripheral set (USB Host, FatFS/SDIO, LTDC/DSIHOST, SAI1, dual I2C/USART, QSPI)
        rather than trim it, since it builds/boots cleanly as-is
- [ ] Set up VSCode `tasks.json` / `launch.json` for build + flash + debug
  - [x] Confirm J-Link tooling available as an alternate probe (`JLinkGDBServer` installed, OpenOCD
        has `interface/jlink.cfg`, Cortex-Debug supports `jlink` servertype) — default to onboard
        ST-LINK for day-to-day debug, use J-Link for faster reflash / RTT logging
  - [ ] Check UM2092 (F469-Disco user manual) for whether parallel trace pins (TRACECLK/TRACED0-3)
        are broken out on a header — needed to use J-Trace's ETM instruction trace, not just SWO
  - [ ] Install `gdb-multiarch` (needed by Cortex-Debug; `gcc-arm-none-eabi` didn't bundle
        `arm-none-eabi-gdb` on this Ubuntu version)
- [x] **CubeMX regeneration regression discovered + patched**: regenerating for the SDIO DMA/NVIC
      config (below) silently reverted `hspi1.Init.BaudRatePrescaler` from `/16` back to CubeMX's
      own default `/2` (45MHz, over the IT8951's 24MHz max) — even though we'd "fixed" this twice
      before, including editing the `.ioc`'s own `SPI1.CalculateBaudRate` field, which apparently
      doesn't reliably round-trip through CubeMX's GUI model. Symptom was very distinctive: every
      value read back from `EPD_IT8951_GetSystemInfo()` was exactly right-shifted by one bit
      (`1448→724`, `1072→536`, garbled FW/LUT strings) — a clean bit-shift pattern, not random
      noise, which is what pointed at an SPI clock/timing issue rather than a logic bug. Reproduced
      identically across a manual reset and a full reflash before being traced to the prescaler.
      Fixed with `scripts/patch-cubemx.sh`, wired into `CMakeLists.txt` via `execute_process` at
      configure time — checks/re-applies known CubeMX regressions on every `cmake --preset`,
      idempotent (only touches the file when a fix is actually needed, so no spurious rebuilds).
      Tested: deliberately reverted the prescaler, ran `cmake --preset Debug`, confirmed it
      self-healed.
  - [x] Also did the "proper" fix at the source: CubeMX → SPI1 → Configuration → Parameter
        Settings → Prescaler for Baud Rate → `16`, set directly in the GUI rather than hand-editing
        the `.ioc` text (which hadn't reliably round-tripped before). The `.ioc` now tracks an
        explicit `SPI1.BaudRatePrescaler` key that wasn't present before, and `patch-cubemx.sh` is a
        confirmed no-op against the regenerated `main.c` — reflashed and confirmed on real hardware
        that the IT8951 still reads back correctly (`Panel=1448x1072 FWVer=SWv_0.6.
        LUTVer=M841_TFAB512`) after this regeneration.

### Firmware — display bring-up milestone (current focus)
- [x] Vendor + adapt Waveshare's IT8951 driver source (SPI mode) into this repo — used their
      Raspberry Pi driver (genuinely SPI-based) rather than the STM32 demo (I80-only in practice);
      `Drivers/IT8951/e-Paper/EPD_IT8951.c/h` vendored near-verbatim, `Drivers/IT8951/Config/`
      rewritten for STM32 HAL (hspi1 + SPI1_CS/RST/HRDY pins); builds and links cleanly
- [x] Physically wire the HAT to the board per the README wiring table (CN12 + CN8 + CN7 + CN6)
- [x] Bring up SPI and verify communication with the IT8951 (read device info) — **confirmed working
      on real hardware**: `EPD_IT8951_Init()` reads back `Panel(W,H) = (1448,1072)` (exact match to
      the panel spec), `FW Version = SWv_0.6.`, `LUT Version = M841_TFAB512` — real data, not
      floating-pin noise. Called from `StartDefaultTask` in `main.c`.
  - [x] Fixed along the way: newlib-nano (`--specs=nano.specs`) strips float support from
        `printf`/`Debug()`, so the driver's VCOM confirmation (`%.02f`) printed as empty (`-V`
        instead of `-2.59V`). Fixed by adding `-u _printf_float` to linker flags in `CMakeLists.txt`.
- [x] Set the panel's VCOM value in firmware — `EPD_IT8951_Init(2590)` (this panel's `-2.59V`),
      confirmed via the VCOM confirmation printout after the printf-float fix
- [x] **`EPD_IT8951_Clear_Refresh()`'s stdlib `malloc`/`free` usage — checked and fixed.** This
      project's newlib/FreeRTOS integration provides **no** heap locking at all: `Core/Src/sysmem.c`'s
      `_sbrk()` (newlib's only allocation primitive here) has no critical section/mutex around the
      heap-end bump, `Core/Inc/FreeRTOSConfig.h` doesn't set `configUSE_NEWLIB_REENTRANT`, and there
      are no `__malloc_lock`/`__malloc_unlock` hooks anywhere in the repo — so concurrent newlib
      `malloc`/`free` calls from more than one task genuinely would race and could corrupt the heap.
      In *current* practice this specific call was never actually exercised: `grep` found no call
      sites anywhere in the app (only the function's own definition/declaration), and the app only
      ever runs one FreeRTOS task (`StartDefaultTask`) regardless. Fixed anyway rather than leaving a
      footgun for whoever wires it in next: `EPD_IT8951_Clear_Refresh()` was the *only* one of the
      `*_Refresh` family that allocated its own scratch buffer internally — every sibling
      (`1bp`/`2bp`/`4bp`/`8bp_Refresh`) already takes `Frame_Buf` as a caller-supplied parameter.
      Brought `Clear_Refresh` in line with that existing convention instead of introducing a static
      buffer: it now takes `UBYTE* Frame_Buf` as its first parameter (matching the others) and just
      `memset`s it to `0xFF`, with no heap involved at all
      (`Drivers/IT8951/e-Paper/EPD_IT8951.c/h`). A static buffer wasn't viable here anyway — this
      panel's clear buffer is ~758KB (`1448*4/8 * 1072`), far too big for the F469's 384KB internal
      SRAM; a caller-supplied SDRAM buffer (e.g. the existing `fullImgBuf`/`SDRAM_BASE_ADDR` frame
      buffer in `main.c`) is the only buffer big enough anyway, and this way the driver doesn't need
      its own hardcoded SDRAM address alongside `main.c`'s existing partitioning scheme. **Validated
      on real hardware**: temporarily called it from `StartDefaultTask` right after `EPD_IT8951_Init()`
      (passing `fullImgBuf`, `GC16_Mode`), reflashed, confirmed via serial log a clean 9279ms run
      (consistent with previously logged full-panel GC16 timings) with no fault/hang, followed by
      both book pages rendering and displaying correctly exactly as before — then reverted the temp
      call (consistent with this project's practice of not leaving one-off bring-up test code
      permanently wired into boot, see the "Removed the boot-time visual demo/bring-up blocks" entry
      below) and reflashed again to confirm the board returns to its normal boot sequence
      byte-for-byte. Didn't get a webcam photo of the mid-test blank-white state specifically (camera
      was blocked by someone in frame at the time) — the serial-log evidence (successful completion,
      correct timing, no corruption in the pages rendered immediately afterward) was judged sufficient
      for what is a heap-safety fix with no change to rendered output.
- [x] Draw a test pattern/image and confirm it renders on the panel — **confirmed on real hardware**:
      a 100x100px 10px-block checkerboard, written via a small `static` 4bpp buffer (~5KB, plain
      SRAM, no SDRAM needed) and `EPD_IT8951_4bp_Refresh()`, rendered correctly on the panel
- [x] Exercise the FMC/SDRAM with an actual read/write test (pattern fill + read-back) to confirm
      the timing config works, before trusting it as the IT8951 frame buffer — **confirmed on real
      hardware, full 16MB pass**. Two things were needed: (1) CubeMX only configured the FMC
      controller's *timing* via `HAL_SDRAM_Init()`; the SDRAM chip's own JEDEC power-up command
      sequence (clock enable → precharge all → auto-refresh x8 → load mode register → refresh rate)
      was missing and had to be added to `MX_FMC_Init()`'s `USER CODE` section, using ST's own
      reference values for this exact chip (`stm32469i_discovery_sdram.c` in the cached
      `STM32Cube_FW_F4` package) — base `0xC0000000`, size `0x1000000` (16MB), refresh count
      `0x0569`; (2) the test itself (`SDRAM_Test()` in `main.c`) writes each 32-bit word its own
      address-derived value across all 4,194,304 words and reads it back — 0 mismatches. Also added
      a second on-panel visual marker (solid black = pass, striped = fail) alongside the checkerboard
      so pass/fail is visible without a serial monitor
- [x] Route the IT8951 frame buffer through FMC/SDRAM — **confirmed on real hardware, smooth
      16-level gradient across the full panel, no artifacts, confirmed by direct visual
      inspection**: a raw pointer at `SDRAM_BASE_ADDR` (0xC0000000) works directly since SDRAM is
      memory-mapped, no linker script changes needed. This took several rounds to get right —
      three distinct issues were found along the way, in the order they were fixed:
  - [x] **The actual root cause, found last: a 16-bit integer overflow in the vendored driver.**
        Every `EPD_IT8951_HostAreaPackedPixelWrite_*` function (1bp/2bp/4bp/4bp_Chunked) declared
        its word-count as `UWORD Source_Buffer_Length` (`uint16_t`, max 65535). For a full panel at
        4bpp, `Width(362) * Height(1072) = 388064` — silently wraps to `60384`. Only ~15% of every
        full-panel transfer (~166 of 1072 rows) actually went out before `LoadImgEnd` cut it short;
        the rest of the panel kept showing whatever was already in the chip's buffer. This
        reproduced **identically regardless of content** (solid white, solid black, and the
        gradient all showed the same banding) — that content-independence was the key clue it
        wasn't a pixel-data or write-pacing bug at all. Small transfers (checkerboard/marker, a few
        KB) never hit this since their word counts fit in 16 bits. Fixed by widening
        `Source_Buffer_Length` to `UDOUBLE` (`uint32_t`) in all four functions in `EPD_IT8951.c`.
  - [x] `Packed_Write=true` (the fast bulk-write path, `EPD_IT8951_WriteMuitiData`) checks busy/HRDY
        once before the whole burst starts and never again during it — a real correctness/robustness
        concern for very large continuous transfers (no backpressure if the chip's internal write
        pipeline falls behind), even though it turned out not to be the actual cause of the banding
        above. Addressed by adding `EPD_IT8951_WriteMuitiDataChunked` /
        `EPD_IT8951_4bp_Refresh_Chunked` (checks busy every `IT8951_WRITE_CHUNK_WORDS`, 2048 words,
        instead of never) — also a nice performance win, full-panel writes dropped from ~20-30s
        (the fully per-word `Packed_Write=false` path) to ~800ms-1.2s.
  - [x] 4bpp nibble order was backwards — the IT8951 programming guide documents P0 (first/
        lower-X pixel) in the **low** nibble and P1 in the **high** nibble of each byte; had it
        reversed. Didn't show up in the checkerboard/marker tests since solid fills are invariant
        to nibble order — only visible on an asymmetric pattern like the gradient.
  - [x] Side quest: the ST-LINK intermittently vanished from `lsusb` throughout this debugging
        session, which turned out to be real — kernel log showed an actual `USB disconnect` event,
        and `usbcore.autosuspend` is set to a 2-second idle timeout system-wide. Fixed with a udev
        rule (`/etc/udev/rules.d/99-stlink-no-suspend.rules`) disabling autosuspend specifically for
        the ST-LINK's VID:PID (0483:374b), confirmed via `power/control` reading `on` afterward.
- [x] Confirm both full refresh (GC16) and fast/partial (A2 mode) refresh work — **confirmed on
      real hardware**. Test: a 400x400 top-left region toggled black/white/black/white via
      `EPD_IT8951_1bp_Refresh(..., A2_Mode, ...)`, `Packed_Write=false` (proven-safe slow path, not
      yet chunked for 1bpp). Visually clean — the A2 region updated correctly with no disturbance to
      the surrounding full-panel gradient. Timing (real measurement, one run): A2 passes took
      390ms each (888ms for the first, which includes waiting for the preceding GC16 refresh to
      finish) vs. full-panel GC16 refreshes at 4368-4729ms — meaningfully faster, consistent with
      A2 being a binary/no-grayscale-settling waveform mode.
  - [ ] **Unexplained**: that same run's full-panel GC16 refreshes (4368-4729ms) were 4-5x slower
        than earlier measurements of the identical code path (~800-1200ms). No code changed between
        runs. Possible cause: panel temperature (GC16's waveform timing is temperature-compensated
        internally, and the panel had been refreshed repeatedly in a short span) or something
        environmental — not investigated further, logged here for later if it recurs or matters.
  - [ ] 1bpp/A2 full-panel writes still use the proven-safe slow path (`Packed_Write=false`), not a
        chunked variant like the 4bpp one — fine for a 400x400 test, but full-panel 1bpp would want
        the same chunked-write speedup treatment before relying on it for real page turns.

### Storage
- [x] SD card + FatFS — **confirmed on real hardware**: mount, write, and read-back verified
      byte-for-byte on a real SD card (`SD mount OK`, `SD card: 15263 MB total, 15263 MB free`,
      wrote 27 bytes, read back 27 bytes, content matched). Two gaps found and fixed:
  - [x] **No DMA/interrupt configured for SDIO at all** — `sd_diskio.c` calls
        `BSP_SD_ReadBlocks_DMA`/`WriteBlocks_DMA`, which need a DMA channel and the SDIO interrupt
        enabled to signal completion, but CubeMX never generated either (same class of gap as the
        SDRAM JEDEC sequence: peripheral basics configured, but not everything the actual driver
        needs). Fixed via CubeMX: Connectivity → SDIO → DMA Settings → added a DMA request
        (auto-assigned DMA2_Stream3) → NVIC Settings → enabled SDIO global interrupt → regenerated;
        CubeMX correctly auto-generated `SDIO_IRQHandler`/`DMA2_Stream3_IRQHandler` on its own.
        Side effect of this regeneration: silently reverted the SPI1 clock fix (see the CubeMX
        regeneration regression entry above) — reflashing after any CubeMX regen and checking the
        panel still initializes correctly is worth doing as a habit.
  - [x] **8.3 filenames required** — `ffconf.h` has `_USE_LFN=0` (long filenames disabled), so a
        base filename over 8 characters (e.g. `epaper_test.txt`) fails with `FR_INVALID_NAME`
        (FRESULT 6). Fixed by using `EPTEST.TXT` for the test; worth remembering for real ebook
        filenames later, unless LFN gets enabled.
### Rendering
- [x] **Font rendering — first step confirmed on real hardware.** Decided against a runtime outline
      rasterizer (stb_truetype/FreeType): an e-reader only needs a handful of fixed sizes, so baking
      glyphs offline costs nothing and keeps render time (and therefore awake/battery time — see
      below) minimal and predictable. Also decided against pulling in LVGL's AA font pipeline for
      now — real quality upgrade, but more moving parts (LVGL font descriptor structs + `lv_font_conv`
      tooling) for a first pass.
  - [x] Vendored the plain `sFONT`-format bitmap fonts from the companion repo
        (`~/git/epaper/stm32f469i-disco-lvgl-demo/Utilities/Fonts/font{8,12,16,20,24}.c` — classic ST
        BSP format, 1bpp fixed-width glyph tables, no AA, no external tooling) into
        `Drivers/Fonts/` in this repo (all 5 sizes copied; `fonts.h`'s `LINE()` macro dropped since
        it depended on `BSP_LCD_GetFont()`, not applicable here)
  - [x] Wrote `Drivers/Fonts/EPD_Text.c/h`: `EPD_Text_DrawChar`/`DrawString` walk each glyph's row
        bitmap (MSB-first, `(Width+7)/8` bytes/row) and set the corresponding 4bpp nibble in the
        SDRAM framebuffer via a `SetPixel4bpp` read-modify-write helper (needed since the IT8951's
        4bpp packing is 2 pixels/byte — P0 low nibble/even x, P1 high nibble/odd x, same convention
        established by the gradient test)
  - [x] Test: rendered "Hello, e-paper!" (Font24) plus two lines of Font12 (an a-z/A-Z/0-9 sweep) into
        the SDRAM buffer, GC16 refresh — **confirmed on real hardware via webcam capture**, legible,
        rest of panel stayed clean white, no artifacts
  - [ ] **Observed, not yet addressed**: these BSP fonts were designed for small low-res TFTs, and at
        this panel's ~300 PPI they render physically small (Font24, the largest available, is
        legible but far from a comfortable reading size) — real body text will need either much
        larger bitmap fonts baked at this resolution, or the AA/`lv_font_conv` route below sized
        appropriately; worth deciding once page layout (line wrapping, margins) is in place and an
        actual target reading size is picked
- [x] **Proper anti-aliased fonts at reading-appropriate sizes — confirmed on real hardware.**
      Went with a custom lightweight format instead of LVGL's font pipeline (avoids a Node.js/
      `lv_font_conv` dependency; this project has no other Node tooling):
  - [x] `tools/gen_font.py` — Python/Pillow script that rasterizes a real TTF/OTF at a given pixel
        size (Pillow's built-in FreeType text rendering gives 8-bit AA coverage per pixel for free),
        quantizes to 4 bits (0=no ink, 15=full ink, matching the panel's 16 GC16 gray levels), packs
        2px/byte (same nibble convention as everywhere else: low nibble=even x, high nibble=odd x),
        and emits a ready-to-compile `.c` file. Proportional per-glyph widths (from the font's real
        advance metrics), not forced monospace — matters for a serif face to look right. Re-run this
        script to add sizes/typefaces; the generated `.c` files are not meant to be hand-edited.
  - [x] Typeface: **Liberation Serif** (Regular + Bold), SIL Open Font License 1.1, already installed
        system-wide (`fonts-liberation` package) — avoided introducing a new font download/dependency
        and its license permits embedding the rasterized glyph data in firmware. Attribution belongs
        in the README if a license file gets added to the repo.
  - [x] Generated three sizes into `Drivers/Fonts/`: `Font32` (Regular, 32px/36px line height),
        `Font44` (Regular, 44px/50px line height, the intended default body-text size), `Font60Bold`
        (Bold, 60px/67px line height, headings/chapter titles) — chosen against the earlier finding
        that the sFONT sizes (max 24px) were too small for comfortable reading at this panel's
        ~300 PPI; these are large enough to read normally in a hardware photo at arm's length.
  - [x] Added `EPD_FontAA.h` (glyph/font struct definitions for this format, separate from the plain
        sFONT structs) and `EPD_Text_DrawCharAA`/`DrawStringAA` in `EPD_Text.c/h` — per-pixel linear
        blend between fg/bg nibble by ink coverage (`bg + coverage*(fg-bg)/15`), which is what makes
        the AA edges look smooth instead of the old hard on/off bit test used for sFONT.
  - [x] Test: rendered the same string at all three sizes plus a "Chapter One"-style heading —
        **confirmed on real hardware via webcam capture**, clean smooth serif letterforms, correct
        proportional spacing, no artifacts; visually a clear step up from the bilevel sFONT test.
  - [ ] Not yet covered: only printable ASCII (0x20-0x7E) — real book text will eventually want
        curly quotes/em-dash/ellipsis (Latin-1 range) from `gen_font.py`, plus Italic weights if
        wanted
  - [ ] Floyd-Steinberg (below) could still apply here as an optional refinement — dithering AA
        glyph-edge coverage down to the 16 gray levels instead of direct quantization — but plain
        4-bit quantization already looks clean at these sizes, so not pursuing unless it's actually
        needed
- [x] **Page layout (word wrap + pagination) — confirmed on real hardware.**
  - [x] Added `Drivers/Fonts/EPD_Layout.c/h`: `EPD_Layout_DrawParagraph()` word-wraps text into a
        given rectangle (greedy wrap - measures each word via the new `EPD_Text_MeasureCharAA`/
        `MeasureSubstringAA` helpers in `EPD_Text.c/h` before committing pixels, breaks to a new
        line when the word wouldn't fit, drops the leading space after a wrap). Draws word-by-word
        directly (no intermediate line buffer/string copy needed). `'\n'` in the source text forces
        a paragraph break. Words wider than the available width are drawn as-is (not
        hyphenated/clipped) - acceptable for now, no real prose hits this.
  - [x] **Pagination via a continuation pointer**: `EPD_Layout_DrawParagraph()` returns a pointer
        into the input text where it stopped (because the next line wouldn't fit above the bottom
        margin), or `NULL` if all the text was drawn. This lets a caller paginate through arbitrarily
        long text one screen at a time - re-call with the returned pointer for the next page -
        without laying out (or holding in memory) more than one page at a time. Important for later
        reading a whole book off the SD card without needing the full text resident in RAM.
  - [x] Test: rendered the opening ~1300 characters of "Alice's Adventures in Wonderland" (public
        domain, embedded as a test string in `main.c`) with a bold "Chapter I (n/4)" heading
        (`Font60Bold`) + wrapped body text (`Font44`), looping on the continuation pointer —
        **confirmed on real hardware via webcam capture**: page 1 consumed 982 characters before
        running out of vertical room, page 2 consumed the remaining 346 and reported "all text
        drawn"; visually, page 2 correctly resumes mid-sentence with no word cut across the page
        break, clean word wrap throughout, no artifacts. This is the first genuinely book-page-like
        render in the project.
  - [ ] Not yet done: centered/justified text (current is left-aligned/ragged-right only),
        paragraph indentation or blank-line spacing beyond what `\n\n` already gives, hyphenation for
        oversized words, RTL/multi-column layouts (not needed for this project's scope)
- [ ] **Floyd-Steinberg dithering — filed for later image/cover-art rendering.** Needed when source
      image data doesn't already come as clean grayscale/16-level data (e.g. photos, book cover art,
      anything with more tonal range than the panel's 16 GC16 gray levels, or content going to 1bpp
      for A2 fast-refresh mode) — classic error-diffusion kernel (7/16, 3/16, 5/16, 1/16 to
      right/below-left/below/below-right neighbors) approximates continuous tone as a static dot
      pattern, which suits e-paper well since there's no motion/flicker to reveal the pattern. Not
      needed for plain bitmap-font text (see above) or for any source image that's already
      pre-quantized to grayscale — only add this step when an image's tonal range actually exceeds
      what the panel can represent directly.
- [x] **Plain-text (.txt) file reading from the SD card — confirmed on real hardware.** Replaces the
      embedded test string with a real file-read -> paginate -> render pipeline.
  - [x] Partitioned SDRAM into two regions (`Core/Src/main.c`, `USER CODE BEGIN PD`):
        `SDRAM_BASE_ADDR` for the IT8951 frame buffer (as before, max ~776KB for this panel at 4bpp)
        and `TEXT_BUFFER_BASE` (1MB in, 4MB capacity) for file content - comfortably more than any
        plain-text book needs, with headroom between the two regions.
  - [x] On boot, checks for `ALICE.TXT` on the SD card (`f_stat`); if missing, seeds it by writing
        the same public-domain "Alice's Adventures in Wonderland" excerpt used in the earlier
        embedded-string test, then always reads back whatever is actually on the card into the text
        buffer (`f_read`, null-terminated) - so a real book just has to replace/append to this file by
        any means (there's no way yet to copy an arbitrary file onto this physically-connected card
        from the dev host - USB mass storage mode or a card reader would do it, not implemented) and
        the read/paginate path underneath doesn't change.
  - [x] Test: **confirmed on real hardware**. First boot: "ALICE.TXT not found, seeding... (1328
        bytes)" -> wrote -> read back 1328 bytes -> paginated identically to the earlier embedded-
        string test (982 chars page 1, 346 chars page 2). Then did a board reset (no reflash) to
        confirm persistence: second boot went straight to "read 1328 bytes from ALICE.TXT" with no
        re-seed message - the file genuinely persisted on the SD card, not just in RAM.
  - [ ] Not yet done: reading files larger than fit in one `f_read` call / streaming a file too big
        for the 4MB text buffer (not a concern for typical plain-text books, but worth remembering
        before assuming any file "just works")
  - [x] Turns out there already is a way to get a real file onto this card: a card reader on the dev
        host, used directly (not USB mass storage mode from the firmware) — a real EPUB
        (`Mistborn...epub`, 731718 bytes) showed up on the card this way. USB mass storage mode is
        still worth having eventually (load a book without pulling the card), but isn't the only
        option as previously assumed.
- [x] **SD card directory listing — confirmed on real hardware.** Added a root-directory listing
      (`f_opendir`/`f_readdir`/`f_closedir`) right after the mount/free-space printout in `main.c`,
      so what's actually on the card is visible in the serial log without pulling it. Test: showed
      `EPTEST.TXT` (27 bytes), `ALICE.TXT` (1328 bytes), and the real EPUB the user copied on via a
      card reader — `MISTBO~1.EPU` (731718 bytes).
  - [x] **Long filename (LFN) support added** — the 8.3-only caveat above is fixed. Set
        `_USE_LFN=3` in `ffconf.h` (heap-based working buffer, not `1`/static-BSS or `2`/stack - `3`
        is the only one of the three that's actually thread-safe per FatFs's own docs, and this
        project's vendored FatFs already had everything wired up for it: `_FS_REENTRANT=1`, plus
        `ff_memalloc()`/`ff_memfree()` in `Middlewares/.../FatFs/src/option/syscall.c` - only compiled
        in when `_USE_LFN==3` - forwarding to `ff_malloc`/`ff_free`, already `#define`'d at the bottom
        of `ffconf.h` as FreeRTOS's `pvPortMalloc`/`vPortFree`. All of that was sitting there unused
        with `_USE_LFN=0`.) Also had to vendor two more FatFs option-package files that weren't
        already in the repo: `option/unicode.c` and the `option/ccsbcs.c` it `#include`s for
        single-byte code pages (ours is `_CODE_PAGE=850`) - `ff.c` needs their `ff_convert()`/
        `ff_wtoupper()` whenever LFN is on (link failure without them). Copied both from the cached
        `STM32Cube_FW_F4_V1.28.3` package (confirmed identical FatFs revision, R0.12c, to what's
        already vendored here). Added `unicode.c` to the top-level `CMakeLists.txt`, not
        `cmake/stm32cubemx/CMakeLists.txt`'s `FatFs_Src` list - that list is CubeMX-generated and
        would silently drop it on the next regeneration (the same class of problem as the SPI1
        prescaler regression above), so it goes wherever this project's other hand-added sources
        already live instead.
  - [x] Test: **confirmed on real hardware**. Directory listing now shows the real EPUB title -
        `Mistborn_ Secret History.epub` (731718 bytes) - instead of the truncated `MISTBO~1.EPU`.
        Rest of boot sequence (SDRAM test, SD read/write test, ALICE.TXT read, page layout/
        pagination) unaffected - identical page 1/2 split as before.
- [x] **Removed the boot-time visual demo/bring-up blocks** (black/white flash-clear, full-panel
      16-level gradient, A2 mode 400x400 toggle test) from `main.c` — they'd already served their
      purpose validating the write path (see the full-panel-writes debugging story above) and were
      just adding ~20s of boot time and log noise before the real content (book pages) rendered.
      Each page in the layout loop already clears to white before drawing, so no ghosting-mitigation
      behavior was lost. Confirmed on real hardware: boot to first page displayed dropped from
      ~26s to ~10s, page content unchanged (verified via webcam capture, byte-for-byte identical
      page 1/2 split as before the cleanup). SDRAM test and the EPTEST.TXT SD read/write check were
      kept (silent correctness checks, not visual demos).
- [x] **EPUB parsing — confirmed on real hardware with a real book.** A minimal ZIP reader + DEFLATE
      decompressor + tiny XML/HTML helpers, enough to pull a chapter's plain text out of a real
      `.epub` and feed it into the existing page-layout pipeline. New modules, all in
      `Drivers/Epub/` and `Drivers/Inflate/`:
  - [x] `Drivers/Inflate/puff.c/h` — vendored Mark Adler's reference DEFLATE decompressor (zlib
        license, from `madler/zlib`'s `contrib/puff`) rather than writing one from scratch.
  - [x] `EPUB_Zip.c/h` — minimal ZIP central-directory reader: locates the End Of Central
        Directory record, walks central directory entries, extracts a named entry's data (stored
        or deflated via `puff()`). Decoupled from any file API via an `EPUB_IO` struct
        (read/size/reset callbacks) so it's usable against a real file or, as it turned out,
        plain memory.
  - [x] `EPUB_Xml.c/h` — tiny attribute/tag scanner (find a tag by name respecting word
        boundaries, find its closing `>`, extract an attribute value) plus entity/UTF-8-smart-
        punctuation decoding - not a general XML parser, just enough for EPUB's fixed
        `container.xml`/OPF structure.
  - [x] `EPUB_Html.c/h` — XHTML-to-plain-text: strips tags, discards `<script>`/`<style>`/`<title>`
        element content, decodes entities and literal UTF-8 smart punctuation (curly quotes/dashes/
        ellipsis - ASCII-folded since this project's fonts are ASCII-only, ISO Latin accented
        letters are dropped), inserts paragraph breaks at block-tag boundaries.
  - [x] `EPUB_Book.c/h` — orchestration: parses `META-INF/container.xml` for the OPF path, the
        OPF's manifest+spine for reading order, extracts+converts any chapter to plain text on
        demand; also grabs `<dc:title>` for display.
  - [x] Native test harness (`tools/`-style, run on this dev machine, not the firmware) validated
        all of the above against a synthetic EPUB (Python `zipfile`, mixed stored/deflated entries)
        before ever touching hardware - caught two real bugs cheaply (script/style content leaking
        because skip-mode wasn't checked for plain text between tags, and `<title>` swallowing
        the rest of the document - see below) that would have been much slower to find via
        flash-and-check cycles.
  - [x] **Real, deep hardware bug found and fixed**: reading the actual EPUB (`Mistborn: Secret
        History`, 731718 bytes, 72 zip entries) via repeated `f_lseek()`+`f_read()` calls at
        different offsets on the same open FatFs file handle reliably returned stale/wrong data -
        specifically, alternating between reads near the end of the file (ZIP central directory)
        and reads near the beginning (actual entry data, e.g. `OEBPS/content.opf`'s local header)
        would corrupt the earlier-file read in a way that was stable/reproducible (not random) but
        depended on prior access history. Diagnosed by cross-checking extracted bytes against
        Python's own `zlib`/`zipfile` (same failure = not a decompressor bug) and against the
        *original* file directly (`/home/michael/Downloads/Mistborn_ Secret History.epub`, same
        size, byte-identical central directory - so not SD-copy corruption either). Neither closing
        + reopening the FatFs file handle nor a full `f_mount()` remount fixed it (both tested,
        both reproduced the identical failure) - ruling out both FatFs's file-level and volume-
        level state. **Fix**: since the whole file (a few hundred KB - a few MB for a typical book)
        comfortably fits in the 16MB of SDRAM, load it once via a single sequential `f_read()` at
        open time and have `EPUB_IO` operate on that in-RAM copy for everything afterwards - no
        more repeated FatFs seeks, so nothing left to go stale. Confirmed on hardware: correct ZIP/
        OPF parsing immediately after this change (`Title="Mistborn: Secret History" Chapters=40`).
        Root cause not fully isolated beyond "not FatFs's own file/volume-level caches" - could be
        the SDIO/DMA driver layer or FatFs's cluster-chain-walking in `f_lseek()` - not pursued
        further since the workaround is simple, robust, and well within the RAM budget.
  - [x] **Two more real bugs found via the actual book file** (native tests didn't cover these -
        both are real-world EPUB-producer quirks the synthetic test didn't happen to include until
        added afterward): (1) self-closing `<title/>` (empty per-chapter title, common in
        Calibre-produced books) was treated the same as `<title>...</title>`, so skip-mode entered
        and never saw the (nonexistent) closing tag - silently swallowing the rest of the chapter.
        Fixed by detecting self-closing tags and not entering skip-mode for them. (2) Real body
        text uses literal UTF-8 smart-quote/dash/ellipsis characters, not HTML entities - manifested
        as blank gaps where every apostrophe should be. Fixed by adding `EPUB_DecodeUtf8SmartPunct`
        (same ASCII-folding as the entity decoder, for the equivalent raw UTF-8 sequences).
  - [x] Test: **confirmed on real hardware via webcam capture** - a genuine page of the real book's
        Preface, correctly word-wrapped/paginated, title heading reading "Mistborn: Secret History
        (2/4)", body text clean and correctly punctuated ("anything I've done before", "it's finally
        time", "three years' time").
  - [ ] Not yet done: only the first chapter with >50 characters of text is shown (skips
        cover/title/copyright-style apparatus pages automatically, but there's no real page-turn/
        chapter-navigation UI yet - see below); accented Latin letters and any other non-ASCII
        character without a specific fold are silently dropped rather than transliterated; only
        tested against one real book so far.
- [ ] UI / input handling — physical input (encoder, cap touch, button) and the navigation state
      machine are both not started; see the Custom PCB section below for the current draft input
      hardware (CAP1188 cap touch for prev/next, PEC11R encoder for menu scroll/select, tactile power
      button) — testing this now on the Discovery board with a Bourns PEC11R-4215F-S0024 encoder and
      an Adafruit CAP1188 breakout (ordered 2026-09-22), so this hardware choice gets validated
      before the PCB locks it in
- [ ] Power management / battery life — key lever is deep-sleep between page turns (STOP mode,
      SDRAM either in self-refresh or fully powered down and repopulated from SD on wake), not
      rendering speed — the IT8951 holds the displayed image with zero host involvement once a
      refresh completes

### Custom PCB (in progress — v1 schematic drafted, layout next; choices still open to change)
See README.md's [Custom PCB (Planned)](README.md#custom-pcb-planned) section for the part list,
power tree, board scope and alternatives considered. **BoM review done 2026-09-22.** Decisions:
- v1 keeps the Waveshare HAT external on an SPI connector; the bare IT8951 moves to a later revision.
- TPS63070 → TPS63802 (starts from 1.8 V instead of 3.0 V; 11 µA quiescent instead of 50 µA).
- MAX17222 → TPS63900 (the MAX17222 is boost-only and can't regulate a full cell down to 3.3 V).
- **2026-09-23: cell chemistry LiFePO4 → 1-cell LiPo pouch** (small flat LFP pouches aren't
  buyable in the US; protected LiPo pouches with JST-PH leads are). Power sheet changes:
  MCP73123 + discrete load sharing → BQ24073 (4.2 V, power path with OUT regulated to 4.4 V,
  on-board NTC); RTC backup via an MCP1700 3.0 V LDO (a full LiPo exceeds VBAT's 3.6 V max);
  new 1M/1M `VBAT_SENSE` divider to PA3; UVLO divider 2.2M/1M (off ~3.20 V, on ~3.52 V).
- STM32F469IIT6 (LQFP176); W25Q128JV QSPI flash; PEC11R-4215F-S0024 encoder (24 detents).
- Layered undervoltage protection added (see README "Battery protection").
- Corrections: the IS42S16400J is 8 MB, not 16 MB. The bare IT8951 needs a 1.8 V core supply
  with a power-up order, a crystal and a waveform flash.

Next steps, in order:
- [x] **KiCad schematic — all four sheets drafted** (2026-09-22; branch `pcb-schematic`):
      Power, MCU (STM32F469IIT6 LQFP176), Memory (SDRAM/QSPI/microSD) and Peripherals (HAT header,
      CAP1188, PEC11R, power button). ERC reports 0 violations; `hardware/scripts/check_schematic.py`
      checks nets, pin mux, memory buses, single-connection nets and footprint pads (187 nets, 83
      MCU pins, 604 pin/pad connections OK; 190 nets / 84 pins after the LiPo swap). All pin numbers were also cross-checked by hand
      against DS11189. README "MCU, Memory and Peripherals Sheets" has the decisions. **Not yet
      reviewed by a person.** Power-sheet open items:
  - [x] **TPS63802 footprint** — built from TI's DLA0010A land pattern (`epaper.pretty`).
  - [x] **TPS63900 footprint check** (2026-09-23) — the stock
        `WSON-10-1EP_2.5x2.5mm_P0.5mm_EP1.2x2mm` matches TI's DSK0010A land pattern (SLVSET3D):
        same 0.5 mm pitch, 0.25 mm pads and 1.2 × 2.0 mm thermal pad; its pads are 0.225 mm
        longer outward (IPC toe) and 0.05 mm closer to the EP, both fine.
  - [x] **Inductors** (2026-09-23) — all three are now Murata DFE201612E (2.0 × 1.6 × 1.2 mm),
        whose recommended land pattern is exactly the stock `L_Murata_DFE201610P` footprint:
        L1 -R47M (Isat 5.5 A, 26 mΩ), L2 -1R0M (Isat 4.0 A, covering the TPS61023's 3.7 A valley
        limit; 48 mΩ), L3 -2R2M (DNP; in TI's TPS63900 list, 2.4 A).
  - [x] **Undervoltage cutoff thresholds** (2026-09-23) — R6/R15 = 2.2M/1.0M on TPS63802 EN (off
        below ~3.20 V, on above ~3.52 V, 0.32 V hysteresis). Above the PCM's 3.0 ± 0.1 V cutoff
        (they can only meet at worst-case tolerances, and a PCM cut is harmless). After a cut
        under load the pouch rebounds by its IR drop (~0.1 V at a 0.5 A refresh through ~0.2 Ω)
        plus relaxation, to ~3.35–3.45 V: normally below 3.52 V. A long rest could just reach
        it, so firmware must not refresh on a low battery at boot (next item).
  - [ ] **Firmware: low-battery boot rule** — at boot, read `VBAT_SENSE` *before* enabling the
        HAT or peripheral rail; below ~3.45 V, go straight back to STANDBY without a refresh
        (the "please charge" screen is already on the e-paper). Prevents a slow
        boot → refresh → cut → recover cycle.
  - [ ] **Firmware battery measurement + graceful shutdown** — read `VBAT_SENSE` (PA3, ADC1_IN3,
        cell/2). At ~3.4 V under light load: save state, draw a "please charge" screen, enter
        standby. LiPo's sloped curve also makes this a usable fuel estimate (see Fuel gauge).
  - [x] **Choose the cell** — two EEMB protected LiPo pouches ordered 2026-09-23 (README
        "Candidate cells"): LP603449 1100 mAh (6.3 × 34.5 × 51 mm) and 963450 1800 mAh (~9.9 ×
        34.5 × 52 mm). Same outline, so size the battery bay for the thicker one. Pack specs,
        protection-board thresholds and the bay dimensions are in README "Candidate cells".
  - [ ] **When the cells arrive:** check lead polarity against J2 (pin 1 = +) with a meter and
        re-pin the JST housing if needed (EEMB's drawings only say red = +, not which contact);
        measure the real dimensions, especially the LP603449, whose pack envelope is inferred
        from its cell spec; keep spares at 40–60% charge (EEMB storage guidance).
  - [x] **Charge temperature / current vs the cell specs** — ISET 3.01k (~296 mA, ≤ 0.3C of 1100 mAh:
        EEMB's 0–20 °C limit), TMR 72k (7.2–12 h timer). The cells' 45 °C limit can't be met with
        resistors (see README), so CE is now `CHG_DIS` (PD6, 100k pull-down) and TS is readable on
        `TS_SENSE` (PC1).
  - [ ] **Firmware: charge-temperature supervision** — while charging (CHG_STAT low), read
        TS_SENSE (V = 75 µA × R_NTC; NCP15XH103: ~5.2k at 43 °C, ~4.7k at 46 °C), assert
        CHG_DIS above ~43 °C with a few degrees of hysteresis. The charger's own 0/50 °C window
        still applies with the MCU off.
  - [x] **Peripheral load switch fitted on v1** (2026-09-23): U4 TPS22965 populated, R13 bypass
        DNP, R14 100k pull-down on PERIPH_EN (off at reset / in STANDBY), CT 1 nF 25 V (~1.3 ms
        rise, ~50 mA inrush). Cuts the idle floor from ~2–20 mA to µA.
  - [ ] **Firmware: peripheral rail sequencing** — PERIPH_EN (PD7) high before FMC/QSPI/SDIO
        init; before dropping it, put those pins in analog/low (no back-powering); on re-enable,
        redo the SDRAM JEDEC init and re-mount SD. Idle policy: STOP + SDRAM self-refresh
        between page turns, STANDBY + rail off after a few minutes idle.
  - [x] **Soft power / EN control** (2026-09-23) — decided: no latching power switch. "Off" is
        MCU STANDBY with the button on WKUP; the peripheral rail and HAT are cut and the CAP1188
        sleeps, leaving tens of µA (years of shelf life; measure at bring-up). TPS63802 EN stays
        just the undervoltage divider. A firmware IWDG covers hangs.
  - [ ] **TPS63900 EN (v2)** — its EN is a plain logic input (no precise threshold), so when the
        always-on rail is fitted it needs its own undervoltage cutoff.
  - [ ] **Battery connector polarity** — J2 pin 1 = +. JST-PH lead polarity isn't consistent
        across LiPo vendors; confirm against the actual cell before plugging it in.
  - [x] **USB-C shield** (2026-09-23) — decided: straight to GND. The case is plastic with no
        earth, so there's no ground loop for an RC to break, and it's the shortest ESD return.
  - [x] **Fuel gauge** (2026-09-23) — decided: none on v1. LiPo's sloped curve makes the
        `VBAT_SENSE` voltage (read at rest, between refreshes) a usable % via a lookup table. If
        that proves too coarse, a MAX17261 (in KiCad's stock library) is the v2 option.
  - [x] **Cold-charge protection** — solved by the switch to LiPo: the BQ24073's TS input with an
        NTC blocks charging outside ~0–50 °C.
  - [x] **NTC coupling** (2026-09-23) — the cell sits beside the PCB, so RT1 is now a leaded
        Murata NXFT15XH103FA2B (same 10k/B3380 curve as the NCP15XH103 it replaces, so the TS
        thresholds don't move) on two solder pads, head taped to the pouch. Check the lead
        diameter against the 0.4 mm pad holes and pick the lead-length suffix.
      Gotcha found while building it: a **hidden `power_in` pin in a KiCad symbol creates an
      implicit global net named after the pin**. The first draft's stacked duplicate VIN pins
      silently shorted VSYS to +3V3. Only the netlist check caught it; ERC just printed a
      "multiple net names" warning. Stacked duplicates must be hidden *passive* pins, as the stock
      libraries do.
- [ ] **Schematic open items (other sheets)**:
  - [ ] **Human review pass** of all four sheets in Eeschema (and tidy the generated layout,
        e.g. the dense VDD pin row on the MCU).
  - [x] **Crystals** (2026-09-23): HSE NDK NX3225GD-8MHZ-STD-CRA-3 (CL 8 pF, 2 × 10 pF); LSE NDK
        NX3215SA-32.768KHZ-EXS00A-MU00525 (CL 6 pF, ESR ≤ 70 kΩ, 2 × 6.2 pF; footprint now 3215).
  - [ ] **LSE margin:** AN2867 gm_crit ≈ 0.58 µA/V for that crystal. Compare with the F469
        datasheet's LSE Gm_crit_max (ST's site wouldn't download here); if it's short, enable the
        high-drive LSE (RCC_BDCR LSEMOD) in firmware, or pick a lower-ESR crystal.
  - [x] **Electrode pads** (2026-09-23): two small electrode boards (one design, fitted on both
        sides) on JST-SH cables to J302/J303 (touch / GND / touch). Geometry is in
        `hardware/enclosure/out/electrode_board.json`.
  - [x] **Electrode board KiCad project** (2026-09-23): `hardware/electrode/`, generated by
        `hardware/scripts/gen_electrode.py` (schematic, pad footprint) and
        `gen_electrode_pcb.py` (board, built with KiCad's own pcbnew API). 74 × 10 mm, 0.8 mm
        FR4; two 25 × 8 mm mask-covered pads on the wall side; SM03B-SRSS-TB on the back, cable
        pointing at the main PCB; hatched GND pour on the back only. ERC 0, DRC 0 violations /
        0 unconnected / 0 schematic-parity issues. One design, fitted twice (the right one turned
        over). Not yet: fab outputs (Gerbers etc.), and a check of the sensitivity on real
        hardware (the CAP1188 breakout + copper tape through a 2.2 mm PA12 offcut would do).
  - [x] **ESD** (2026-09-23): U302 TPD4E05U06 (0.5 pF/line) on the four electrode-cable lines;
        none on the HAT header (internal cable) or the power button (behind a plastic flexure);
        the encoder's metal shaft already discharges through its mounting lugs to GND, and its
        lines have the 10k/10 nF filters.
  - [x] **HRDY floats** (2026-09-23): R316 100k pull-down (reads "busy" while the HAT is off).
  - [ ] **Firmware changes for the custom board:** FMC 16-bit data width; SD detect on PG10; HAT
        pins held low or floating while `EPD_5V_EN` is low (back-powering); TIM3 encoder mode;
        CAP1188 at 0x29; VBUS sensing on PA9.
- [ ] **Mechanical / enclosure** — gates layout, so do it first: board outline; where the external
      HAT and the panel mount; side-wall thickness and material for the CAP1188 electrodes (the
      README draft assumes ≤ ~4 mm plastic); encoder (bottom edge) and power button (top edge)
      positions; battery bay sized to the chosen cell; USB-C and microSD openings. The electrode
      geometry and the ESD decisions both wait on this.
  - [x] **v0 parametric model** (2026-09-23; branch `worktree-enclosure`): `hardware/enclosure/`,
        build123d. 106.8 × 171.4 × 17.8 mm; front shell, panel backer, back cover and knob in MJF
        PA12. All fit checks pass. It exports STEP/STL/3MF, the PCB outline DXF and a placement
        JSON. Design and rationale are in `hardware/enclosure/README.md`. Toolchain decision: build123d
        (it exports STEP, which OpenSCAD can't; it runs headless; checks are written in code). For
        viewing: OCP CAD Viewer in VSCode, or FreeCAD on the STEP files. Printing goes through a
        service (no printer here), so there are no slicer tools.
        Found while building it: the **PEC11R is vertical-mount**, so the knob goes on the front
        face (in the chin), not the bottom edge. The **KMR2 power button can't work from the top
        edge** as drawn.
  - [x] **Decisions** (2026-09-23): keep the HAT's 2×20 Pi header for v1 (~1.1 mm thicker, not
        worth the rework yet); power button moves to the bottom edge (SKRTLAE010 side-actuated on
        the main PCB, pressed through a flexure tab in the wall); side-wall electrodes on two small
        boards in printed channels; keep the front-face knob; RT1 on leads to the pouch. Schematic
        updated to match (SW302, J302/J303, RT1), `check_schematic.py` passes.
  - [x] **Datasheet values** (2026-09-23) replaced most placeholders: PEC11R (body 6.5 mm, M7
        bushing, travel 0.5 ± 0.3 mm, shaft length from the mounting surface), Alps SKRTLAE010
        (3.3 mm tall, 0.2 mm travel), Molex 104031 (1.42 mm), JST SM03B (4.25 × 5.8 × 2.9).
        **Consequence: the encoder is now PEC11R-4220F-S0024 (20 mm shaft).** The bushing (5 mm
        on the 15 mm part) left only ~2.5 mm of shaft for the knob once the push travel is
        cleared; with 20 mm it grips 5.5 mm and stands 7.9 mm proud. Schematic updated.
  - [ ] **Measure what no datasheet gives** (`PH` in `params.py`, listed on every build): panel
        active-area offset, FPC width/bend, **panel thickness** (Waveshare says 0.67 mm, ED060KD1
        listings say 1.6 mm), HAT outline and height.
  - [ ] **Human review** of the renders / OCP viewer, then a fit-check print (the shell alone or
        its chin section) against the real panel, encoder and connectors before the full set.
  - [x] Board outline into KiCad (2026-09-23): done by `gen_main_pcb.py` from
        `out/pcb_placement.json` directly (no DXF import step).
- [ ] **PCB layout** — the next milestone after the enclosure: stackup (4 layers is likely, given
      the FMC bus and LQFP176), placement, then routing. The Freerouting MCP is configured for
      autorouting once parts are placed.
  - [x] **Bootstrap** (2026-09-23): `hardware/kicad/stm32-epaper.kicad_pcb`, generated once by
        `hardware/scripts/gen_main_pcb.py` (KiCad's Python, from the schematic netlist and the
        enclosure's placement JSON). 4 layers, 1.6 mm; outline 97.4 × 60 mm with the chin-boss
        notches; all 152 footprints with nets and symbol links (DRC schematic parity: 0 issues).
        Placed by the enclosure: SW301 on the knob axis; J1 USB-C, J201 microSD and SW302 on the
        bottom edge (mouth/slot/plunger outwards); J302/J303 (electrode cables), J2 (battery),
        RT1 pads and J301 (HAT) on the top edge; H301–H304 on the standoffs. Everything else is
        staged to the right of the board by sheet. Fab rules set for a standard 4-layer service:
        0.127 mm default clearance (0.1 min), 0.15 mm tracks, 0.45/0.2 mm vias, 0.2 mm
        hole-to-copper. The script refuses to overwrite the board without --force: from here on,
        the .kicad_pcb is the source of truth.
  - [ ] **Known DRC items**: 8 hole-clearance errors inside the stock SW302 (Alps SKRT: pegs
        0.10–0.15 mm from its own pads) and J1 (GCT USB4105: 0.19 mm) footprints, i.e. the
        vendors' land patterns. Confirm with the fab or exclude them in the DRC dialog.
  - [ ] **Placement** of the core: MCU (U101) central, SDRAM (U201) hugging the FMC pins, QSPI
        (U202) near its pins, power stage (U1–U7, L1–L3) near J2/J1 with short switch loops, the
        CAP1188 near J302/J303, crystals right at the MCU. Keep top-side parts under the backer
        ≤ 7.9 mm tall (`pcb_placement.json`); J201 and J1 sit 0.85 mm / 0 mm in from the edge.
  - [ ] **Stackup/planes**: GND on In1, split power on In2; then routing (FMC and SDIO length
        matching are loose at these speeds, but keep the SDRAM bus short).
- [ ] **Fabrication outputs and ordering** — DRC clean; Gerbers + drill, pick-and-place and BoM
      with real MPNs (several values are still "verify" placeholders); pick a fab/assembler and
      check part availability (LQFP176 F469, IS42S16400J, TPS63802/TPS63900 stock); order boards,
      a stencil and parts.
- [ ] **Custom-board bring-up** — a phase of its own, done in order:
  - [ ] Power only (no MCU flashed): check each rail at the test points; the UVLO cut-off and
        restart thresholds (bench supply on the battery connector); charging and termination at
        3.6 V; load sharing with USB plugged/unplugged.
  - [ ] First flash over the TC2050 pads, and confirm ROM USB DFU via the BOOT button.
  - [ ] Port the firmware to the board (see "Firmware changes for the custom board" above), then
        bring up SDRAM (16-bit), microSD, the HAT, CAP1188 and the encoder one at a time, with
        serial-log evidence for each, as done on the Discovery board.
  - [ ] Measure real active and sleep current against the README's sleep-current estimate.
- [ ] **Firmware — input handling**: encoder (CLK/DT interrupt, SW GPIO), CAP1188 (I²C init +
      interrupt handler), power button (WKUP EXTI); wire all three to a simple event queue.
- [ ] **Firmware — navigation state machine**: page-turn events → next/prev page via the existing
      pagination API; chapter jump; library screen listing books from the SD card.
- [ ] **Firmware — reading state persistence**: remember the position in each book (and which
      book was open last) across sleep and power cycles. Store it on the SD card, or in the RTC
      backup registers/backup SRAM for the "last open" pointer, so waking resumes on the same page.
- [ ] **Firmware — getting books onto the device**: today the only way is pulling the microSD
      card. Add USB mass-storage (MSC) mode over the USB-C port (OTG_FS is already wired, see
      README pin table), with FatFs unmounted on the device side while the host has the card.

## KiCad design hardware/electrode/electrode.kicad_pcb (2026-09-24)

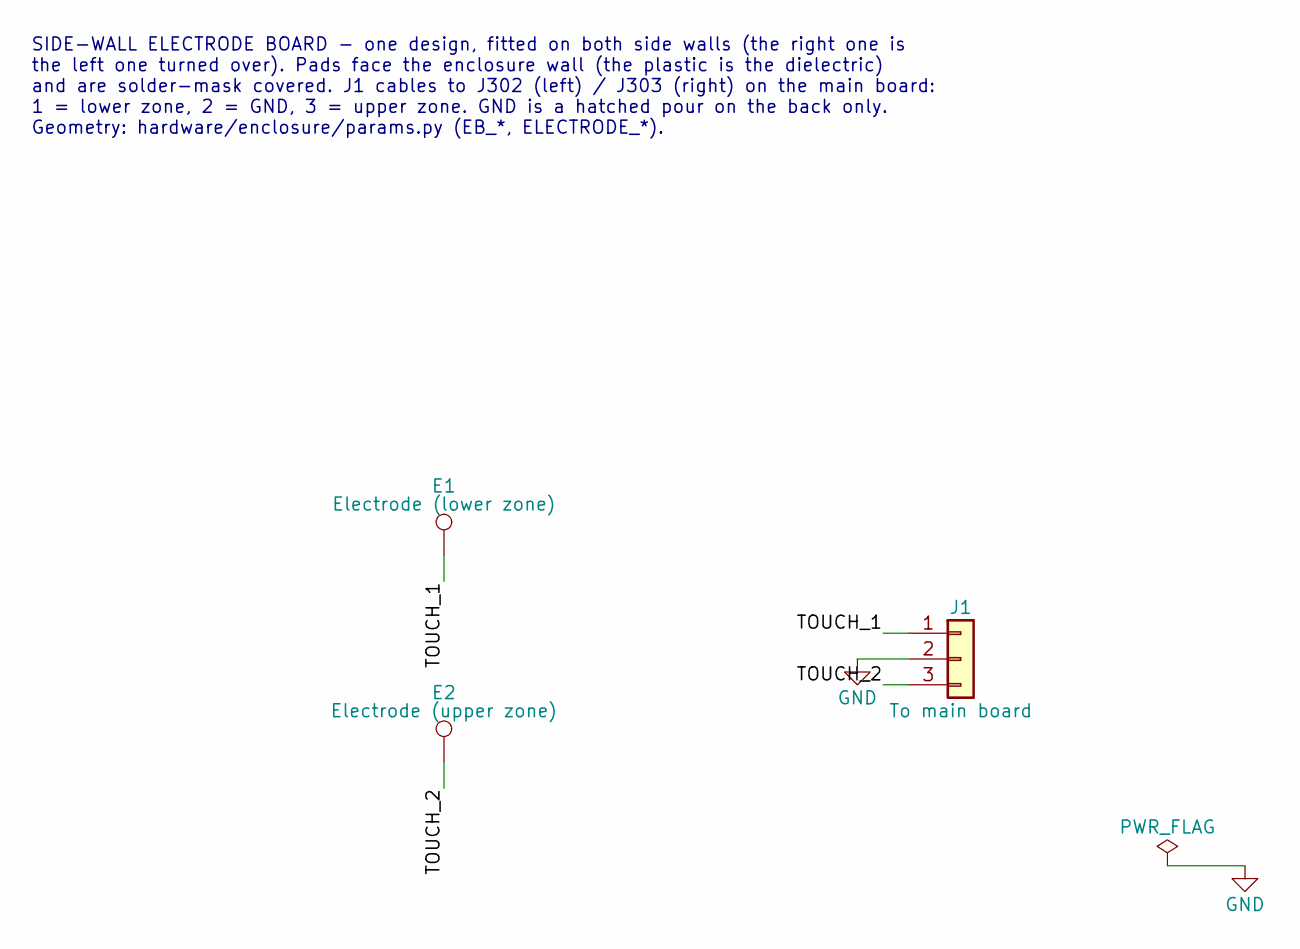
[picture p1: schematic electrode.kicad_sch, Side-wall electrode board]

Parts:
E1: Electrode (lower zone); Electrode_Pad_25x8mm
E2: Electrode (upper zone); Electrode_Pad_25x8mm
J1: To main board; JST_SH_SM03B-SRSS-TB_1x03-1MP_P1.00mm_Horizontal; MPN SM03B-SRSS-TB

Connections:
/TOUCH_1: E1.1, J1.1
/TOUCH_2: E2.1, J1.3
GND: J1.2

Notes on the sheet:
SIDE-WALL ELECTRODE BOARD - one design, fitted on both side walls (the right one is the left one turned over). Pads face the enclosure wall (the plastic is the dielectric) and are solder-mask covered. J1 cables to J302 (left) / J303 (right) on the main board: 1 = lower zone, 2 = GND, 3 = upper zone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

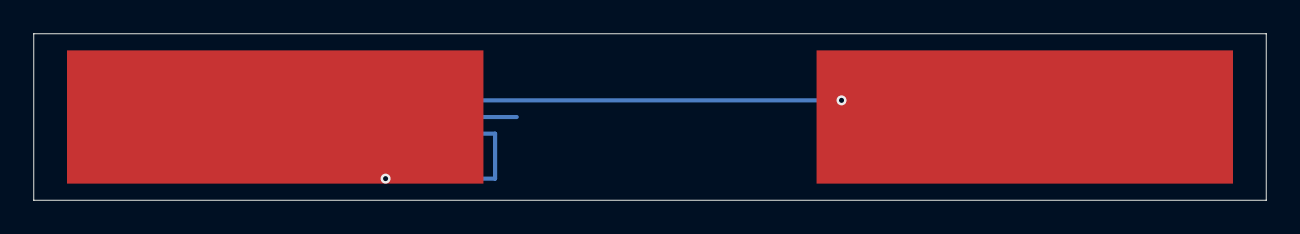
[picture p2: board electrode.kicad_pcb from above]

Board: 2 copper layers, 74.0 x 10.0 mm, 3 parts (1 on the bottom side), 2 nets.

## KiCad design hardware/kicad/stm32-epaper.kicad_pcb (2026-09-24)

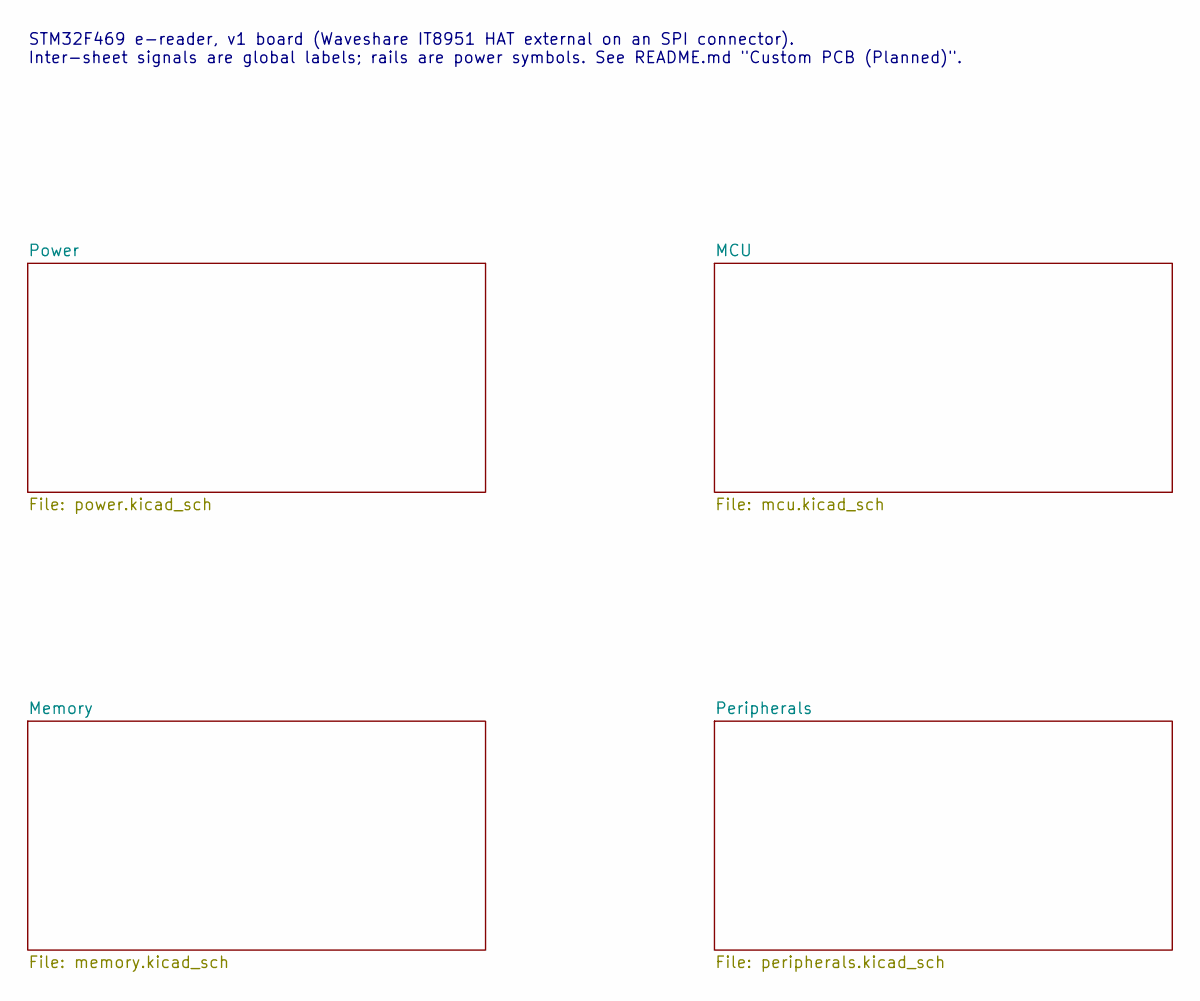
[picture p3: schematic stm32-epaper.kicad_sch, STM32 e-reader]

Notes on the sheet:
STM32F469 e-reader, v1 board (Waveshare IT8951 HAT external on an SPI connector). Inter-sheet signals are global labels; rails are power symbols. See README.md "Custom PCB (Planned)".

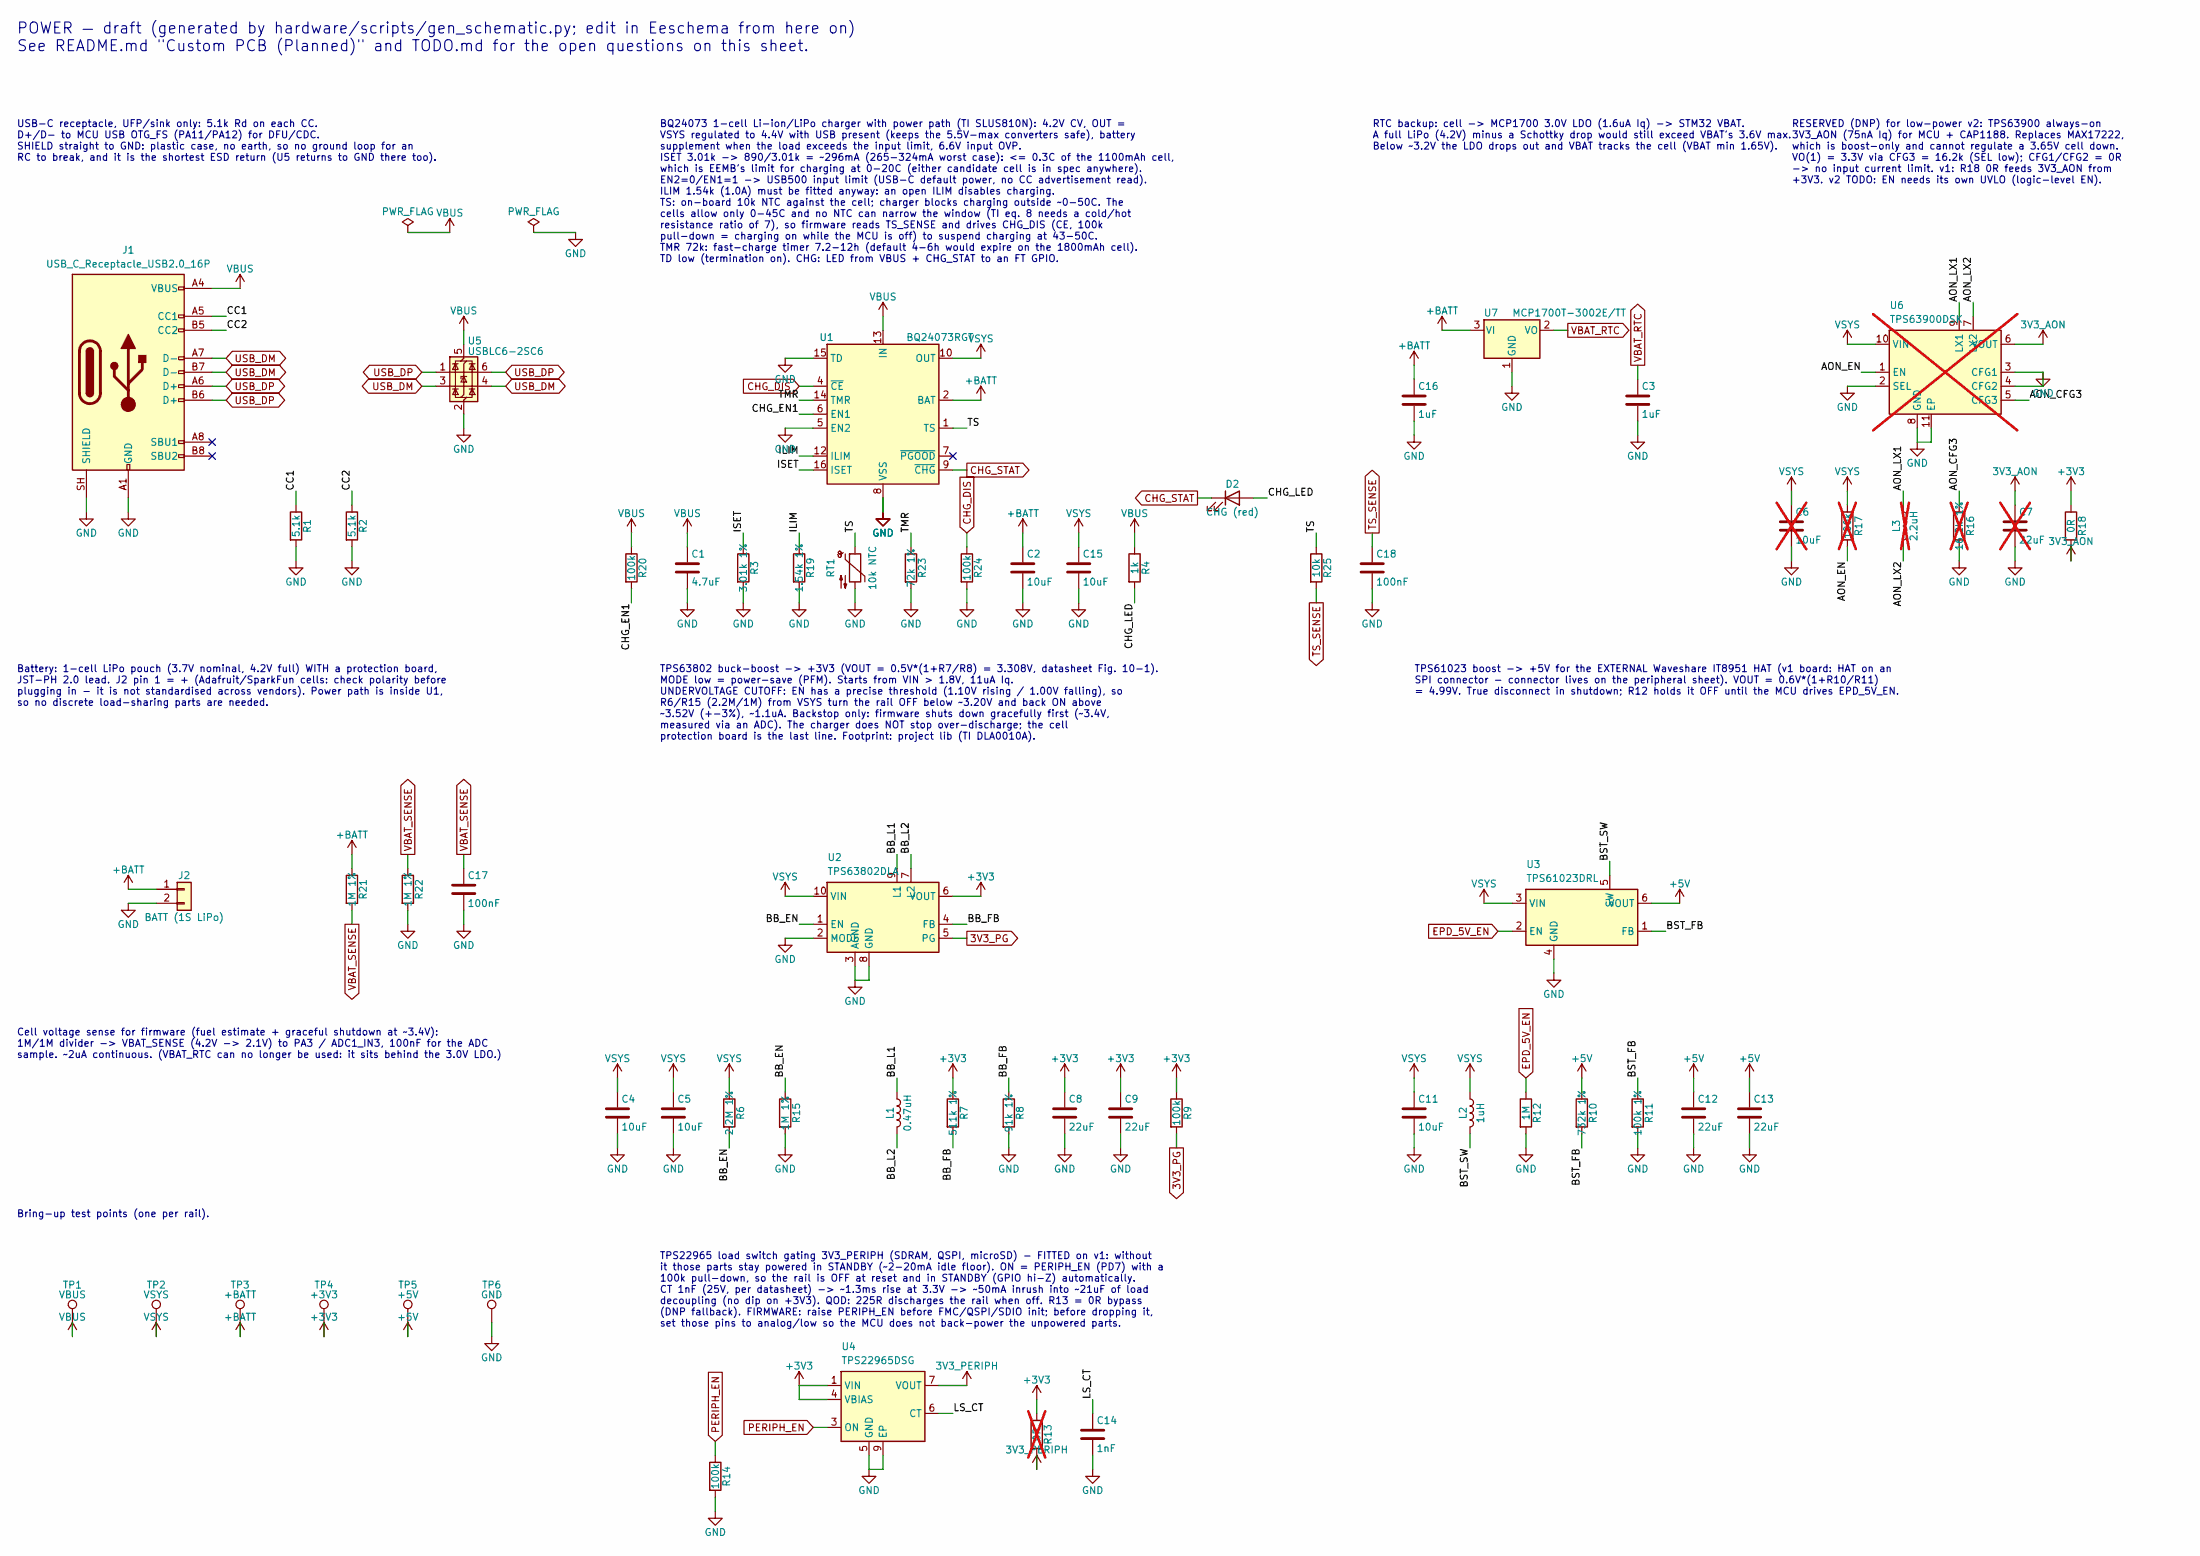
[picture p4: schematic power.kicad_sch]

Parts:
C1: 4.7uF; C_0603_1608Metric; Voltage 10V
C2, C4, C5, C15: 10uF; C_0603_1608Metric; Voltage 10V
C3, C16: 1uF; C_0402_1005Metric
C6: 10uF; C_0603_1608Metric; not fitted
C7: 22uF; C_0603_1608Metric; not fitted
C8, C9: 22uF; C_0603_1608Metric
C11: 10uF; C_0603_1608Metric
C12, C13: 22uF; C_0805_2012Metric
C14: 1nF; C_0402_1005Metric; Voltage 25V X7R (CT pin can reach 12V)
C17, C18: 100nF; C_0402_1005Metric
D2: CHG (red); LED_0603_1608Metric
J1: USB_C_Receptacle_USB2.0_16P; USB_C_Receptacle_GCT_USB4105-xx-A_16P_TopMnt_Horizontal; MPN GCT USB4105-GF-A
J2: BATT (1S LiPo); JST_PH_S2B-PH-SM4-TB_1x02-1MP_P2.00mm_Horizontal
L1: 0.47uH; L_Murata_DFE201610P; MPN DFE201612E-R47M=P2 (Isat 5.5A, 26mR; Mu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
L2: 1uH; L_Murata_DFE201610P; MPN DFE201612E-1R0M=P2 (Isat 4.0A >= TPS610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
L3: 2.2uH; L_Murata_DFE201610P; MPN DFE201612E-2R2M=P2 (TPS63900 datasheet 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; not fitted
R1, R2: 5.1k; R_0402_1005Metric
R3: 3.01k 1%; R_0402_1005Metric
R4: 1k; R_0402_1005Metric
R6: 2.2M 1%; R_0402_1005Metric
R7: 511k 1%; R_0402_1005Metric
R8: 91k 1%; R_0402_1005Metric
R9, R14, R20, R24: 100k; R_0402_1005Metric
R10: 732k 1%; R_0402_1005Metric
R11: 100k 1%; R_0402_1005Metric
R12: 1M; R_0402_1005Metric
R13: 0R; R_0603_1608Metric; not fitted
R15, R21, R22: 1M 1%; R_0402_1005Metric
R16: 16.2k 1%; R_0402_1005Metric; not fitted
R17: 100k; R_0402_1005Metric; not fitted
R18: 0R; R_0603_1608Metric
R19: 1.54k 1%; R_0402_1005Metric
R23: 72k 1%; R_0402_1005Metric
R25: 10k; R_0402_1005Metric
RT1: 10k NTC; SolderWire-0.1sqmm_1x02_P3.6mm_D0.4mm_OD1mm; MPN NXFT15XH103FA2B (Murata leaded film NTC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
TP1: VBUS; TestPoint_Pad_D1.5mm
TP2: VSYS; TestPoint_Pad_D1.5mm
TP3: +BATT; TestPoint_Pad_D1.5mm
TP4: +3V3; TestPoint_Pad_D1.5mm
TP5: +5V; TestPoint_Pad_D1.5mm
TP6: GND; TestPoint_Pad_D1.5mm
U1: BQ24073RGT; VQFN-16-1EP_3x3mm_P0.5mm_EP1.6x1.6mm; MPN BQ24073RGTR
U2: TPS63802DLA; Texas_DLA0010A_VSON-HR-10_2x3mm_P0.5mm; MPN TPS63802DLAR
U3: TPS61023DRL; SOT-563; MPN TPS61023DRLR
U4: TPS22965DSG; Texas_DSG0008A_WSON-8-1EP_2x2mm_P0.5mm_EP0.9x1.6mm; MPN TPS22965DSGR
U5: USBLC6-2SC6; SOT-23-6
U6: TPS63900DSK; WSON-10-1EP_2.5x2.5mm_P0.5mm_EP1.2x2mm; MPN TPS63900DSKR; not fitted
U7: MCP1700T-3002E/TT; SOT-23; MPN MCP1700T-3002E/TT

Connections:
3V3_AON: C7.1, R18.2, U6.6 (VOUT); also elsewhere on the board
3V3_PERIPH: R13.2, U4.7 (VOUT), U4.8 (VOUT); also elsewhere on the board
3V3_PG: R9.2, U2.5 (PG); also elsewhere on the board
+3V3: C8.1, C9.1, R7.1, R9.1, R13.1, R18.1, TP4.1, U2.6 (VOUT), U4.1 (VIN), U4.2 (VIN), U4.4 (VBIAS)
+5V: C12.1, C13.1, R10.1, TP5.1, U3.6 (VOUT); also elsewhere on the board
+BATT: C2.1, C16.1, J2.1, R21.1, TP3.1, U1.2 (BAT), U1.3 (BAT), U7.3 (VI)
/Power/AON_CFG3: R16.1, U6.5 (CFG3)
/Power/AON_EN: R17.2, U6.1 (EN)
/Power/AON_LX1: L3.1, U6.9 (LX1)
/Power/AON_LX2: L3.2, U6.7 (LX2)
/Power/BB_EN: R6.2, R15.1, U2.1 (EN)
/Power/BB_FB: R7.2, R8.1, U2.4 (FB)
/Power/BB_L1: L1.1, U2.9 (L1)
/Power/BB_L2: L1.2, U2.7 (L2)
/Power/BST_FB: R10.2, R11.1, U3.1 (FB)
/Power/BST_SW: L2.2, U3.5 (SW)
/Power/CC1: J1.A5 (CC1), R1.1
/Power/CC2: J1.B5 (CC2), R2.1
/Power/CHG_EN1: R20.2, U1.6 (EN1)
/Power/CHG_LED: D2.2 (A), R4.2
/Power/ILIM: R19.1, U1.12 (ILIM)
/Power/ISET: R3.1, U1.16 (ISET)
/Power/LS_CT: C14.1, U4.6 (CT)
/Power/TMR: R23.1, U1.14 (TMR)
/Power/TS: R25.1, RT1.1, U1.1 (TS)
CHG_DIS: R24.1, U1.4 (~CE); also elsewhere on the board
CHG_STAT: D2.1 (K), U1.9 (~CHG); also elsewhere on the board
EPD_5V_EN: R12.1, U3.2 (EN); also elsewhere on the board
GND: C1.2, C2.2, C3.2, C4.2, C5.2, C6.2, C7.2, C8.2, C9.2, C11.2, C12.2, C13.2, C14.2, C15.2, C16.2, C17.2, C18.2, J1.A1 (GND), J1.A12 (GND), J1.B1 (GND), J1.B12 (GND), J1.SH (SHIELD), J2.2, R1.2, R2.2, R3.2, R8.2, R11.2, R12.2, R14.2, R15.2, R16.2, R19.2, R22.2, R23.2, R24.2, RT1.2, TP6.1, U1.5 (EN2), U1.8 (VSS), U1.15 (TD), U1.17 (VSS), U2.2 (MODE), U2.3 (AGND), U2.8 (GND), U3.4 (GND), U4.5 (GND), U4.9 (EP), U5.2 (GND), U6.2 (SEL), U6.3 (CFG1), U6.4 (CFG2), U6.8 (GND), U6.11 (EP), U7.1 (GND); also elsewhere on the board
PERIPH_EN: R14.1, U4.3 (ON); also elsewhere on the board
TS_SENSE: C18.1, R25.2; also elsewhere on the board
USB_DM: J1.A7 (D-), J1.B7 (D-), U5.3 (I/O2), U5.4 (I/O2); also elsewhere on the board
USB_DP: J1.A6 (D+), J1.B6 (D+), U5.1 (I/O1), U5.6 (I/O1); also elsewhere on the board
VBAT_RTC: C3.1, U7.2 (VO); also elsewhere on the board
VBAT_SENSE: C17.1, R21.2, R22.1; also elsewhere on the board
VBUS: C1.1, J1.A4 (VBUS), J1.A9 (VBUS), J1.B4 (VBUS), J1.B9 (VBUS), R4.1, R20.1, TP1.1, U1.13 (IN), U5.5 (VBUS); also elsewhere on the board
VSYS: C4.1, C5.1, C6.1, C11.1, C15.1, L2.1, R6.1, R17.1, TP2.1, U1.10 (OUT), U1.11 (OUT), U2.10 (VIN), U3.3 (VIN), U6.10 (VIN)

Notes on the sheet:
POWER — draft (generated by hardware/scripts/gen_schematic.py; edit in Eeschema from here on) See README.md "Custom PCB (Planned)" and TODO.md for the open questions on this sheet.
USB-C receptacle, UFP/sink only: 5.1k Rd on each CC. D+/D- to MCU USB OTG_FS (PA11/PA12) for DFU/CDC. SHIELD straight to GND: plastic case, no earth, so no ground loop for an RC to break, and it is the shortest ESD return (U5 returns to GND there too).
BQ24073 1-cell Li-ion/LiPo charger with power path (TI SLUS810N): 4.2V CV, OUT = VSYS regulated to 4.4V with USB present (keeps the 5.5V-max converters safe), battery supplement when the load exceeds the input limit, 6.6V input OVP. ISET 3.01k -> 890/3.01k = ~296mA (265-324mA worst case): <= 0.3C o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
RTC backup: cell -> MCP1700 3.0V LDO (1.6uA Iq) -> STM32 VBAT. A full LiPo (4.2V) minus a Schottky drop would still exceed VBAT's 3.6V max. Below ~3.2V the LDO drops out and VBAT tracks the cell (VBAT min 1.65V).
Battery: 1-cell LiPo pouch (3.7V nominal, 4.2V full) WITH a protection board, JST-PH 2.0 lead. J2 pin 1 = + (Adafruit/SparkFun cells: check polarity before plugging in - it is not standardised across vendors). Power path is inside U1, so no discrete load-sharing parts are needed.
Cell voltage sense for firmware (fuel estimate + graceful shutdown at ~3.4V): 1M/1M divider -> VBAT_SENSE (4.2V -> 2.1V) to PA3 / ADC1_IN3, 100nF for the ADC sample. ~2uA continuous. (VBAT_RTC can no longer be used: it sits behind the 3.0V LDO.)
TPS63802 buck-boost -> +3V3 (VOUT = 0.5V*(1+R7/R8) = 3.308V, datasheet Fig. 10-1). MODE low = power-save (PFM). Starts from VIN > 1.8V, 11uA Iq. UNDERVOLTAGE CUTOFF: EN has a precise threshold (1.10V rising / 1.00V falling), so R6/R15 (2.2M/1M) from VSYS turn the rail OFF below ~3.20V and back ON a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
TPS61023 boost -> +5V for the EXTERNAL Waveshare IT8951 HAT (v1 board: HAT on an SPI connector - connector lives on the peripheral sheet). VOUT = 0.6V*(1+R10/R11) = 4.99V. True disconnect in shutdown; R12 holds it OFF until the MCU drives EPD_5V_EN.
RESERVED (DNP) for low-power v2: TPS63900 always-on 3V3_AON (75nA Iq) for MCU + CAP1188. Replaces MAX17222, which is boost-only and cannot regulate a 3.65V cell down. VO(1) = 3.3V via CFG3 = 16.2k (SEL low); CFG1/CFG2 = 0R -> no input current limit. v1: R18 0R feeds 3V3_AON from +3V3. v2 TODO: EN n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
TPS22965 load switch gating 3V3_PERIPH (SDRAM, QSPI, microSD) - FITTED on v1: without it those parts stay powered in STANDBY (~2-20mA idle floor). ON = PERIPH_EN (PD7) with a 100k pull-down, so the rail is OFF at reset and in STANDBY (GPIO hi-Z) automatically. CT 1nF (25V, per datasheet) -> ~1.3ms 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
Bring-up test points (one per rail).

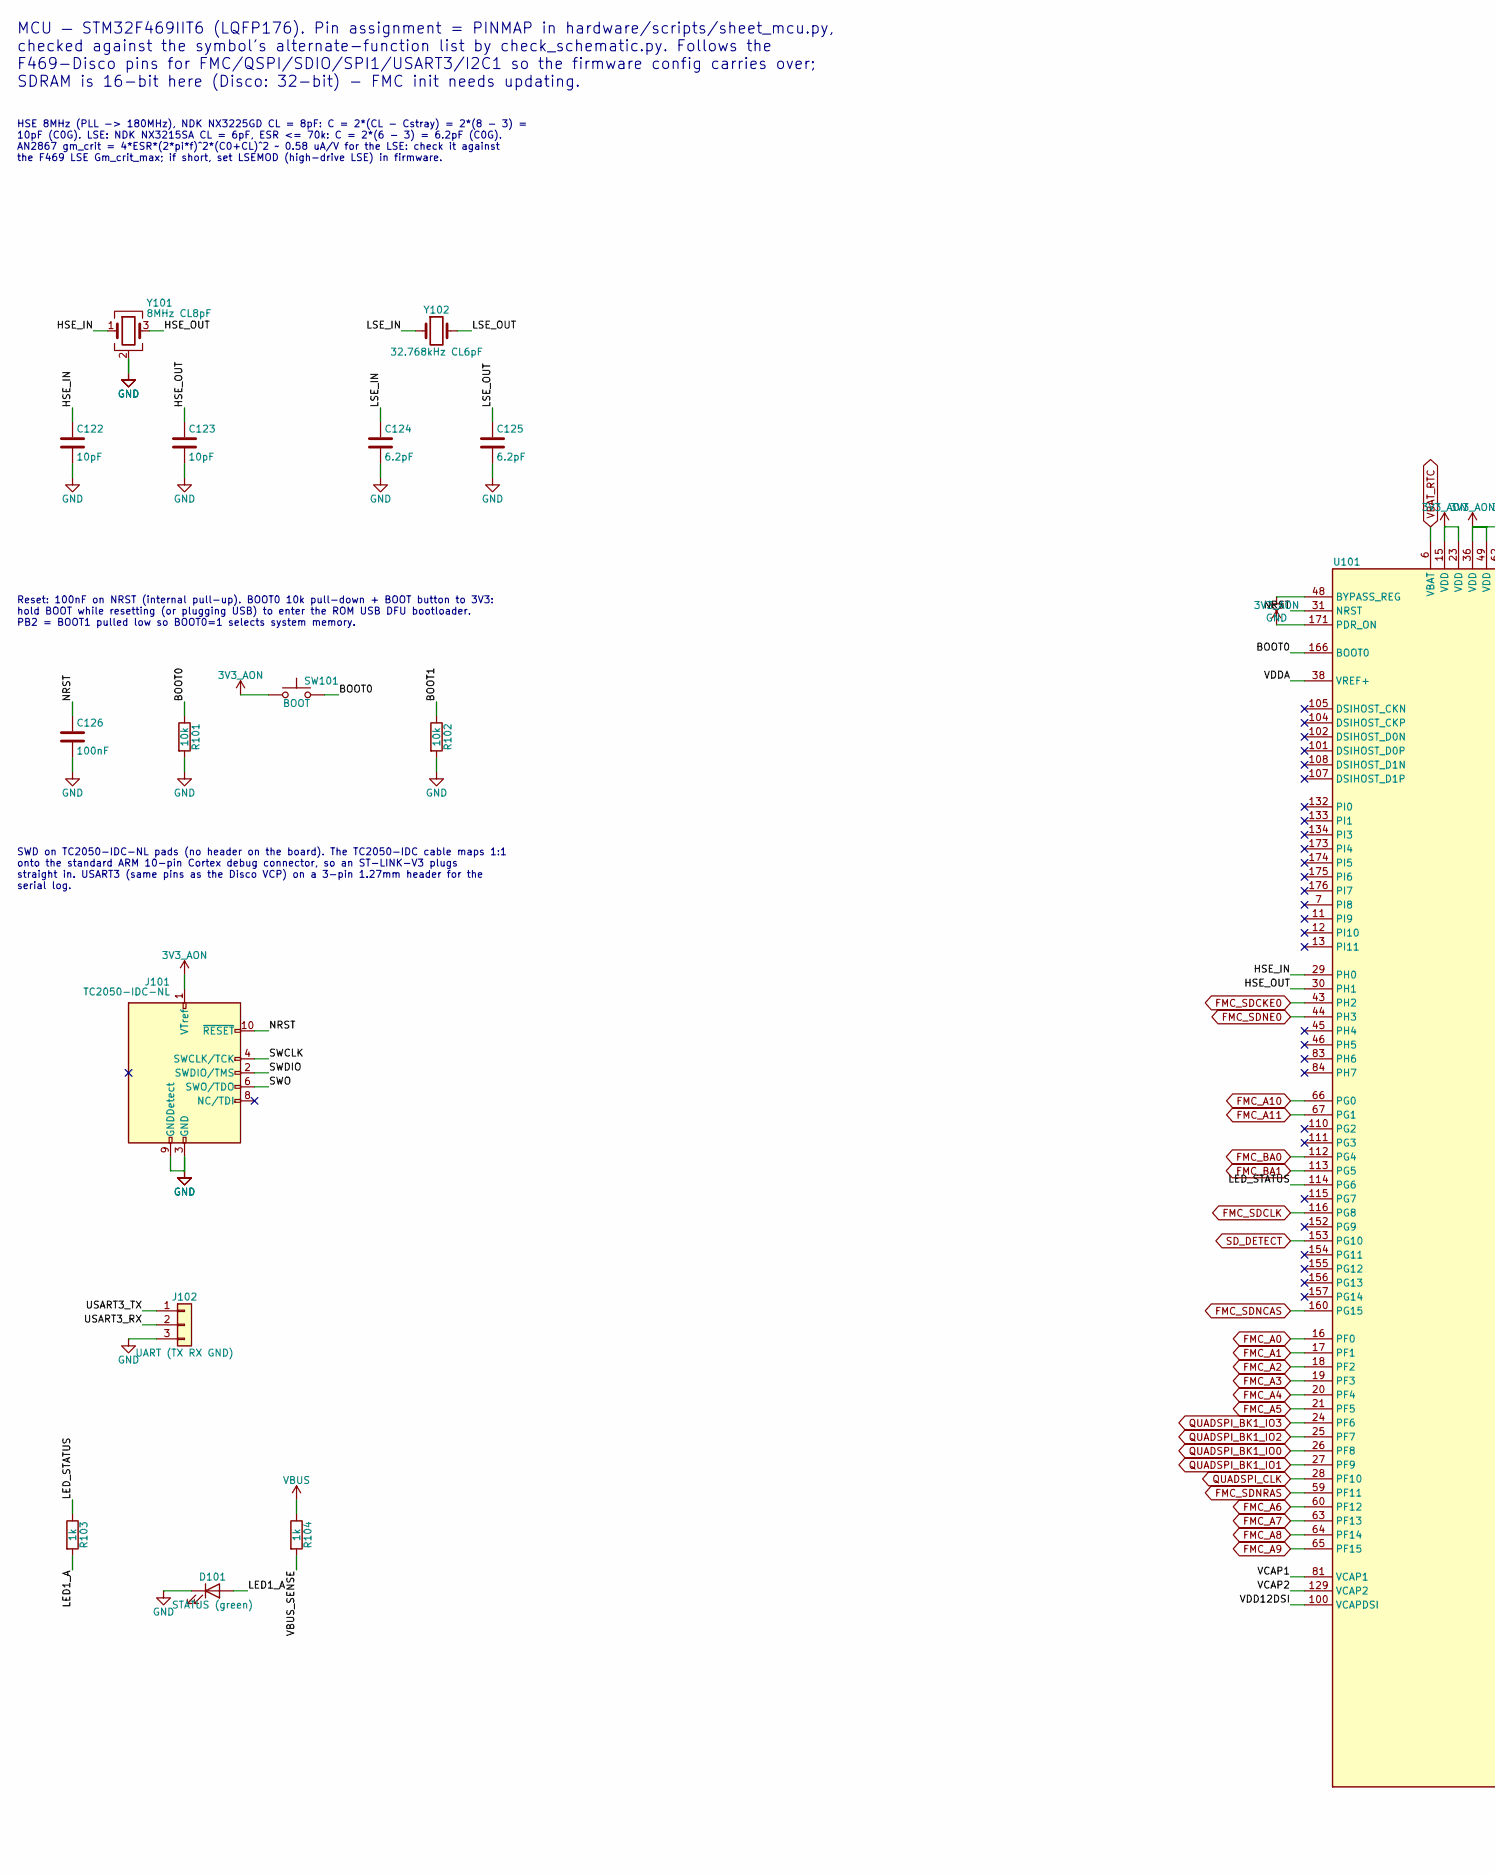
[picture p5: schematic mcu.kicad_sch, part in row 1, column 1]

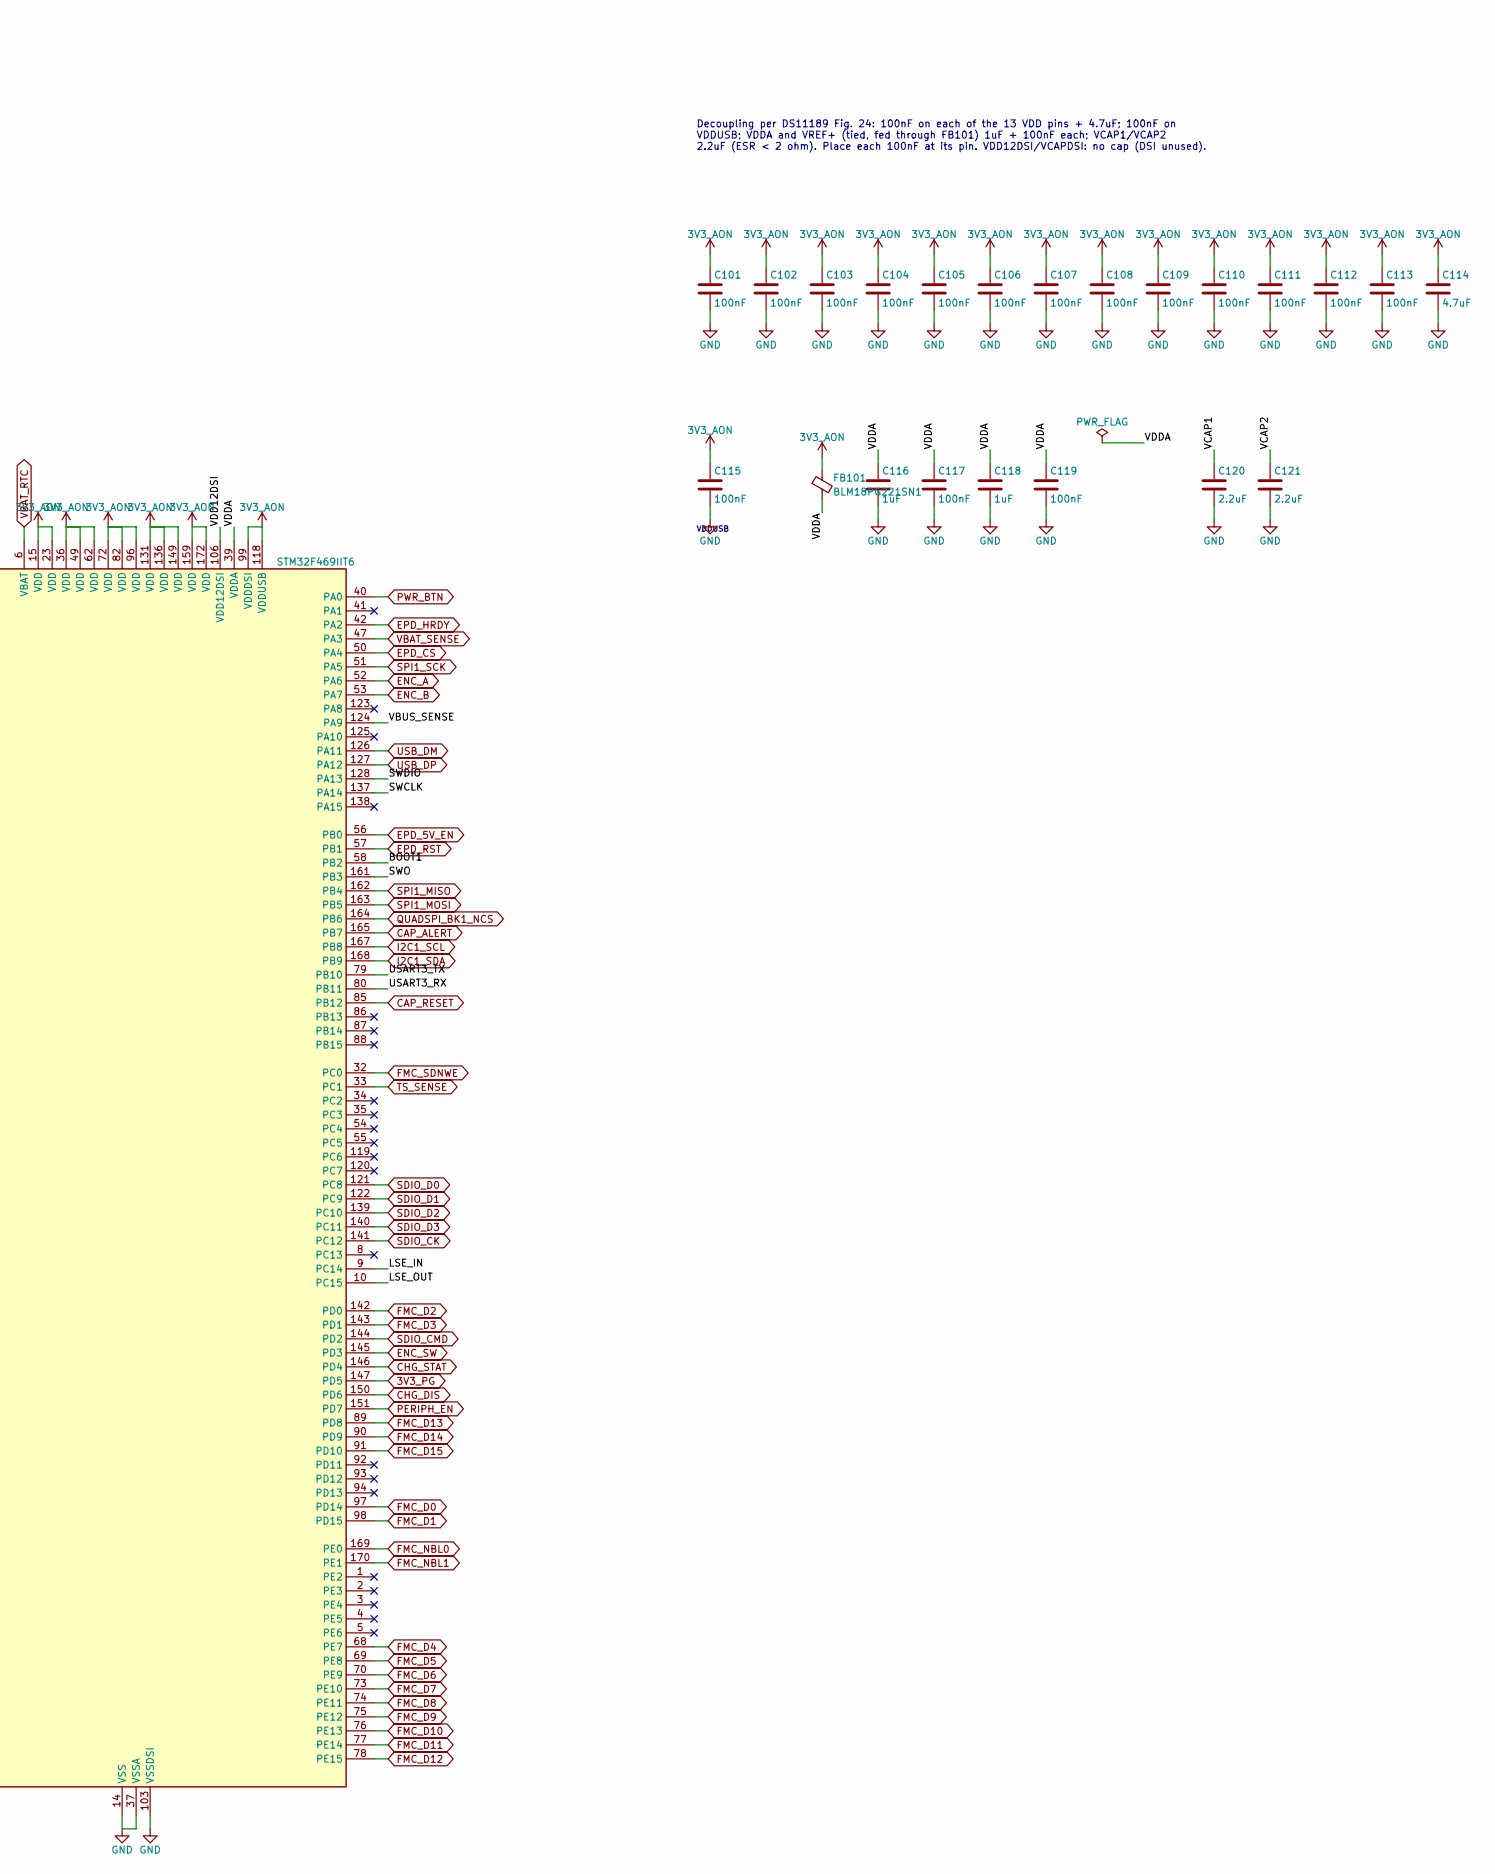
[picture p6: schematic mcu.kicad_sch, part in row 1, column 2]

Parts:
C101, C102, C103, C104, C105, C106, C107, C108, C109, C110, C111, C112, C113, C115, C117, C119, C126: 100nF; C_0402_1005Metric
C114: 4.7uF; C_0603_1608Metric
C116, C118: 1uF; C_0402_1005Metric
C120, C121: 2.2uF; C_0402_1005Metric
C122, C123: 10pF; C_0402_1005Metric
C124, C125: 6.2pF; C_0402_1005Metric
D101: STATUS (green); LED_0603_1608Metric
FB101: BLM18PG221SN1; L_0603_1608Metric
J101: TC2050-IDC-NL; Tag-Connect_TC2050-IDC-NL_2x05_P1.27mm_Vertical
J102: UART (TX RX GND); PinHeader_1x03_P1.27mm_Vertical
R101, R102: 10k; R_0402_1005Metric
R103, R104: 1k; R_0402_1005Metric
SW101: BOOT; SW_Push_1P1T_NO_CK_KMR2
U101: STM32F469IIT6; LQFP-176_24x24mm_P0.5mm; MPN STM32F469IIT6
Y101: 8MHz CL8pF; Crystal_SMD_3225-4Pin_3.2x2.5mm; MPN NX3225GD-8MHZ-STD-CRA-3
Y102: 32.768kHz CL6pF; Crystal_SMD_3215-2Pin_3.2x1.5mm; MPN NX3215SA-32.768KHZ-EXS00A-MU00525

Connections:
3V3_AON: C101.1, C102.1, C103.1, C104.1, C105.1, C106.1, C107.1, C108.1, C109.1, C110.1, C111.1, C112.1, C113.1, C114.1, C115.1, FB101.1, J101.1 (VTref), SW101.1, U101.15 (VDD), U101.23 (VDD), U101.36 (VDD), U101.49 (VDD), U101.62 (VDD), U101.72 (VDD), U101.82 (VDD), U101.96 (VDD), U101.99 (VDDDSI), U101.118 (VDDUSB), U101.131 (VDD), U101.136 (VDD), U101.149 (VDD), U101.159 (VDD), U101.171 (PDR_ON), U101.172 (VDD); also elsewhere on the board
3V3_PG: U101.147 (PD5); also elsewhere on the board
/MCU/BOOT0: R101.1, SW101.2, U101.166 (BOOT0)
/MCU/BOOT1: R102.1, U101.58 (PB2)
/MCU/HSE_IN: C122.1, U101.29 (PH0), Y101.1
/MCU/HSE_OUT: C123.1, U101.30 (PH1), Y101.3
/MCU/LED1_A: D101.2 (A), R103.2
/MCU/LED_STATUS: R103.1, U101.114 (PG6)
/MCU/LSE_IN: C124.1, U101.9 (PC14), Y102.1
/MCU/LSE_OUT: C125.1, U101.10 (PC15), Y102.2
/MCU/NRST: C126.1, J101.10 (~RESET), U101.31 (NRST)
/MCU/SWCLK: J101.4 (SWCLK/TCK), U101.137 (PA14)
/MCU/SWDIO: J101.2 (SWDIO/TMS), U101.128 (PA13)
/MCU/SWO: J101.6 (SWO/TDO), U101.161 (PB3)
/MCU/USART3_RX: J102.2, U101.80 (PB11)
/MCU/USART3_TX: J102.1, U101.79 (PB10)
/MCU/VBUS_SENSE: R104.2, U101.124 (PA9)
/MCU/VCAP1: C120.1, U101.81 (VCAP1)
/MCU/VCAP2: C121.1, U101.129 (VCAP2)
/MCU/VDD12DSI: U101.100 (VCAPDSI), U101.106 (VDD12DSI)
/MCU/VDDA: C116.1, C117.1, C118.1, C119.1, FB101.2, U101.38 (VREF+), U101.39 (VDDA)
CAP_ALERT: U101.165 (PB7); also elsewhere on the board
CAP_RESET: U101.85 (PB12); also elsewhere on the board
CHG_DIS: U101.150 (PD6); also elsewhere on the board
CHG_STAT: U101.146 (PD4); also elsewhere on the board
ENC_A: U101.52 (PA6); also elsewhere on the board
ENC_B: U101.53 (PA7); also elsewhere on the board
ENC_SW: U101.145 (PD3); also elsewhere on the board
EPD_5V_EN: U101.56 (PB0); also elsewhere on the board
EPD_CS: U101.50 (PA4); also elsewhere on the board
EPD_HRDY: U101.42 (PA2); also elsewhere on the board
EPD_RST: U101.57 (PB1); also elsewhere on the board
FMC_A0: U101.16 (PF0); also elsewhere on the board
FMC_A1: U101.17 (PF1); also elsewhere on the board
FMC_A2: U101.18 (PF2); also elsewhere on the board
FMC_A3: U101.19 (PF3); also elsewhere on the board
FMC_A4: U101.20 (PF4); also elsewhere on the board
FMC_A5: U101.21 (PF5); also elsewhere on the board
FMC_A6: U101.60 (PF12); also elsewhere on the board
FMC_A7: U101.63 (PF13); also elsewhere on the board
FMC_A8: U101.64 (PF14); also elsewhere on the board
FMC_A9: U101.65 (PF15); also elsewhere on the board
FMC_A10: U101.66 (PG0); also elsewhere on the board
FMC_A11: U101.67 (PG1); also elsewhere on the board
FMC_BA0: U101.112 (PG4); also elsewhere on the board
FMC_BA1: U101.113 (PG5); also elsewhere on the board
FMC_D0: U101.97 (PD14); also elsewhere on the board
FMC_D1: U101.98 (PD15); also elsewhere on the board
FMC_D2: U101.142 (PD0); also elsewhere on the board
FMC_D3: U101.143 (PD1); also elsewhere on the board
FMC_D4: U101.68 (PE7); also elsewhere on the board
FMC_D5: U101.69 (PE8); also elsewhere on the board
FMC_D6: U101.70 (PE9); also elsewhere on the board
FMC_D7: U101.73 (PE10); also elsewhere on the board
FMC_D8: U101.74 (PE11); also elsewhere on the board
FMC_D9: U101.75 (PE12); also elsewhere on the board
FMC_D10: U101.76 (PE13); also elsewhere on the board
FMC_D11: U101.77 (PE14); also elsewhere on the board
FMC_D12: U101.78 (PE15); also elsewhere on the board
FMC_D13: U101.89 (PD8); also elsewhere on the board
FMC_D14: U101.90 (PD9); also elsewhere on the board
FMC_D15: U101.91 (PD10); also elsewhere on the board
FMC_NBL0: U101.169 (PE0); also elsewhere on the board
FMC_NBL1: U101.170 (PE1); also elsewhere on the board
FMC_SDCKE0: U101.43 (PH2); also elsewhere on the board
FMC_SDCLK: U101.116 (PG8); also elsewhere on the board
FMC_SDNCAS: U101.160 (PG15); also elsewhere on the board
FMC_SDNE0: U101.44 (PH3); also elsewhere on the board
FMC_SDNRAS: U101.59 (PF11); also elsewhere on the board
FMC_SDNWE: U101.32 (PC0); also elsewhere on the board
GND: C101.2, C102.2, C103.2, C104.2, C105.2, C106.2, C107.2, C108.2, C109.2, C110.2, C111.2, C112.2, C113.2, C114.2, C115.2, C116.2, C117.2, C118.2, C119.2, C120.2, C121.2, C122.2, C123.2, C124.2, C125.2, C126.2, D101.1 (K), J101.3 (GND), J101.5 (GND), J101.9 (GNDDetect), J102.3, R101.2, R102.2, U101.14 (VSS), U101.22 (VSS), U101.37 (VSSA), U101.48 (BYPASS_REG), U101.61 (VSS), U101.71 (VSS), U101.95 (VSS), U101.103 (VSSDSI), U101.109 (VSSDSI), U101.117 (VSS), U101.130 (VSS), U101.135 (VSS), U101.148 (VSS), U101.158 (VSS), Y101.2 (G), Y101.4 (G); also elsewhere on the board
I2C1_SCL: U101.167 (PB8); also elsewhere on the board
I2C1_SDA: U101.168 (PB9); also elsewhere on the board
PERIPH_EN: U101.151 (PD7); also elsewhere on the board
PWR_BTN: U101.40 (PA0); also elsewhere on the board
QUADSPI_BK1_IO0: U101.26 (PF8); also elsewhere on the board
QUADSPI_BK1_IO1: U101.27 (PF9); also elsewhere on the board
QUADSPI_BK1_IO2: U101.25 (PF7); also elsewhere on the board
QUADSPI_BK1_IO3: U101.24 (PF6); also elsewhere on the board
QUADSPI_BK1_NCS: U101.164 (PB6); also elsewhere on the board
QUADSPI_CLK: U101.28 (PF10); also elsewhere on the board
SDIO_CK: U101.141 (PC12); also elsewhere on the board
SDIO_CMD: U101.144 (PD2); also elsewhere on the board
SDIO_D0: U101.121 (PC8); also elsewhere on the board
SDIO_D1: U101.122 (PC9); also elsewhere on the board
SDIO_D2: U101.139 (PC10); also elsewhere on the board
SDIO_D3: U101.140 (PC11); also elsewhere on the board
SD_DETECT: U101.153 (PG10); also elsewhere on the board
SPI1_MISO: U101.162 (PB4); also elsewhere on the board
SPI1_MOSI: U101.163 (PB5); also elsewhere on the board
SPI1_SCK: U101.51 (PA5); also elsewhere on the board
TS_SENSE: U101.33 (PC1); also elsewhere on the board
USB_DM: U101.126 (PA11); also elsewhere on the board
USB_DP: U101.127 (PA12); also elsewhere on the board
VBAT_RTC: U101.6 (VBAT); also elsewhere on the board
VBAT_SENSE: U101.47 (PA3); also elsewhere on the board
VBUS: R104.1; also elsewhere on the board

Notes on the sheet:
MCU — STM32F469IIT6 (LQFP176). Pin assignment = PINMAP in hardware/scripts/sheet_mcu.py, checked against the symbol's alternate-function list by check_schematic.py. Follows the F469-Disco pins for FMC/QSPI/SDIO/SPI1/USART3/I2C1 so the firmware config carries over; SDRAM is 16-bit here (Disco: 32-bi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
Decoupling per DS11189 Fig. 24: 100nF on each of the 13 VDD pins + 4.7uF; 100nF on VDDUSB; VDDA and VREF+ (tied, fed through FB101) 1uF + 100nF each; VCAP1/VCAP2 2.2uF (ESR < 2 ohm). Place each 100nF at its pin. VDD12DSI/VCAPDSI: no cap (DSI unused).
VDDUSB
HSE 8MHz (PLL -> 180MHz), NDK NX3225GD CL = 8pF: C = 2*(CL - Cstray) = 2*(8 - 3) = 10pF (C0G). LSE: NDK NX3215SA CL = 6pF, ESR <= 70k: C = 2*(6 - 3) = 6.2pF (C0G). AN2867 gm_crit = 4*ESR*(2*pi*f)^2*(C0+CL)^2 ~ 0.58 uA/V for the LSE: check it against the F469 LSE Gm_crit_max; if short, set LSEMOD (h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
Reset: 100nF on NRST (internal pull-up). BOOT0 10k pull-down + BOOT button to 3V3: hold BOOT while resetting (or plugging USB) to enter the ROM USB DFU bootloader. PB2 = BOOT1 pulled low so BOOT0=1 selects system memory.
SWD on TC2050-IDC-NL pads (no header on the board). The TC2050-IDC cable maps 1:1 onto the standard ARM 10-pin Cortex debug connector, so an ST-LINK-V3 plugs straight in. USART3 (same pins as the Disco VCP) on a 3-pin 1.27mm header for the serial log.

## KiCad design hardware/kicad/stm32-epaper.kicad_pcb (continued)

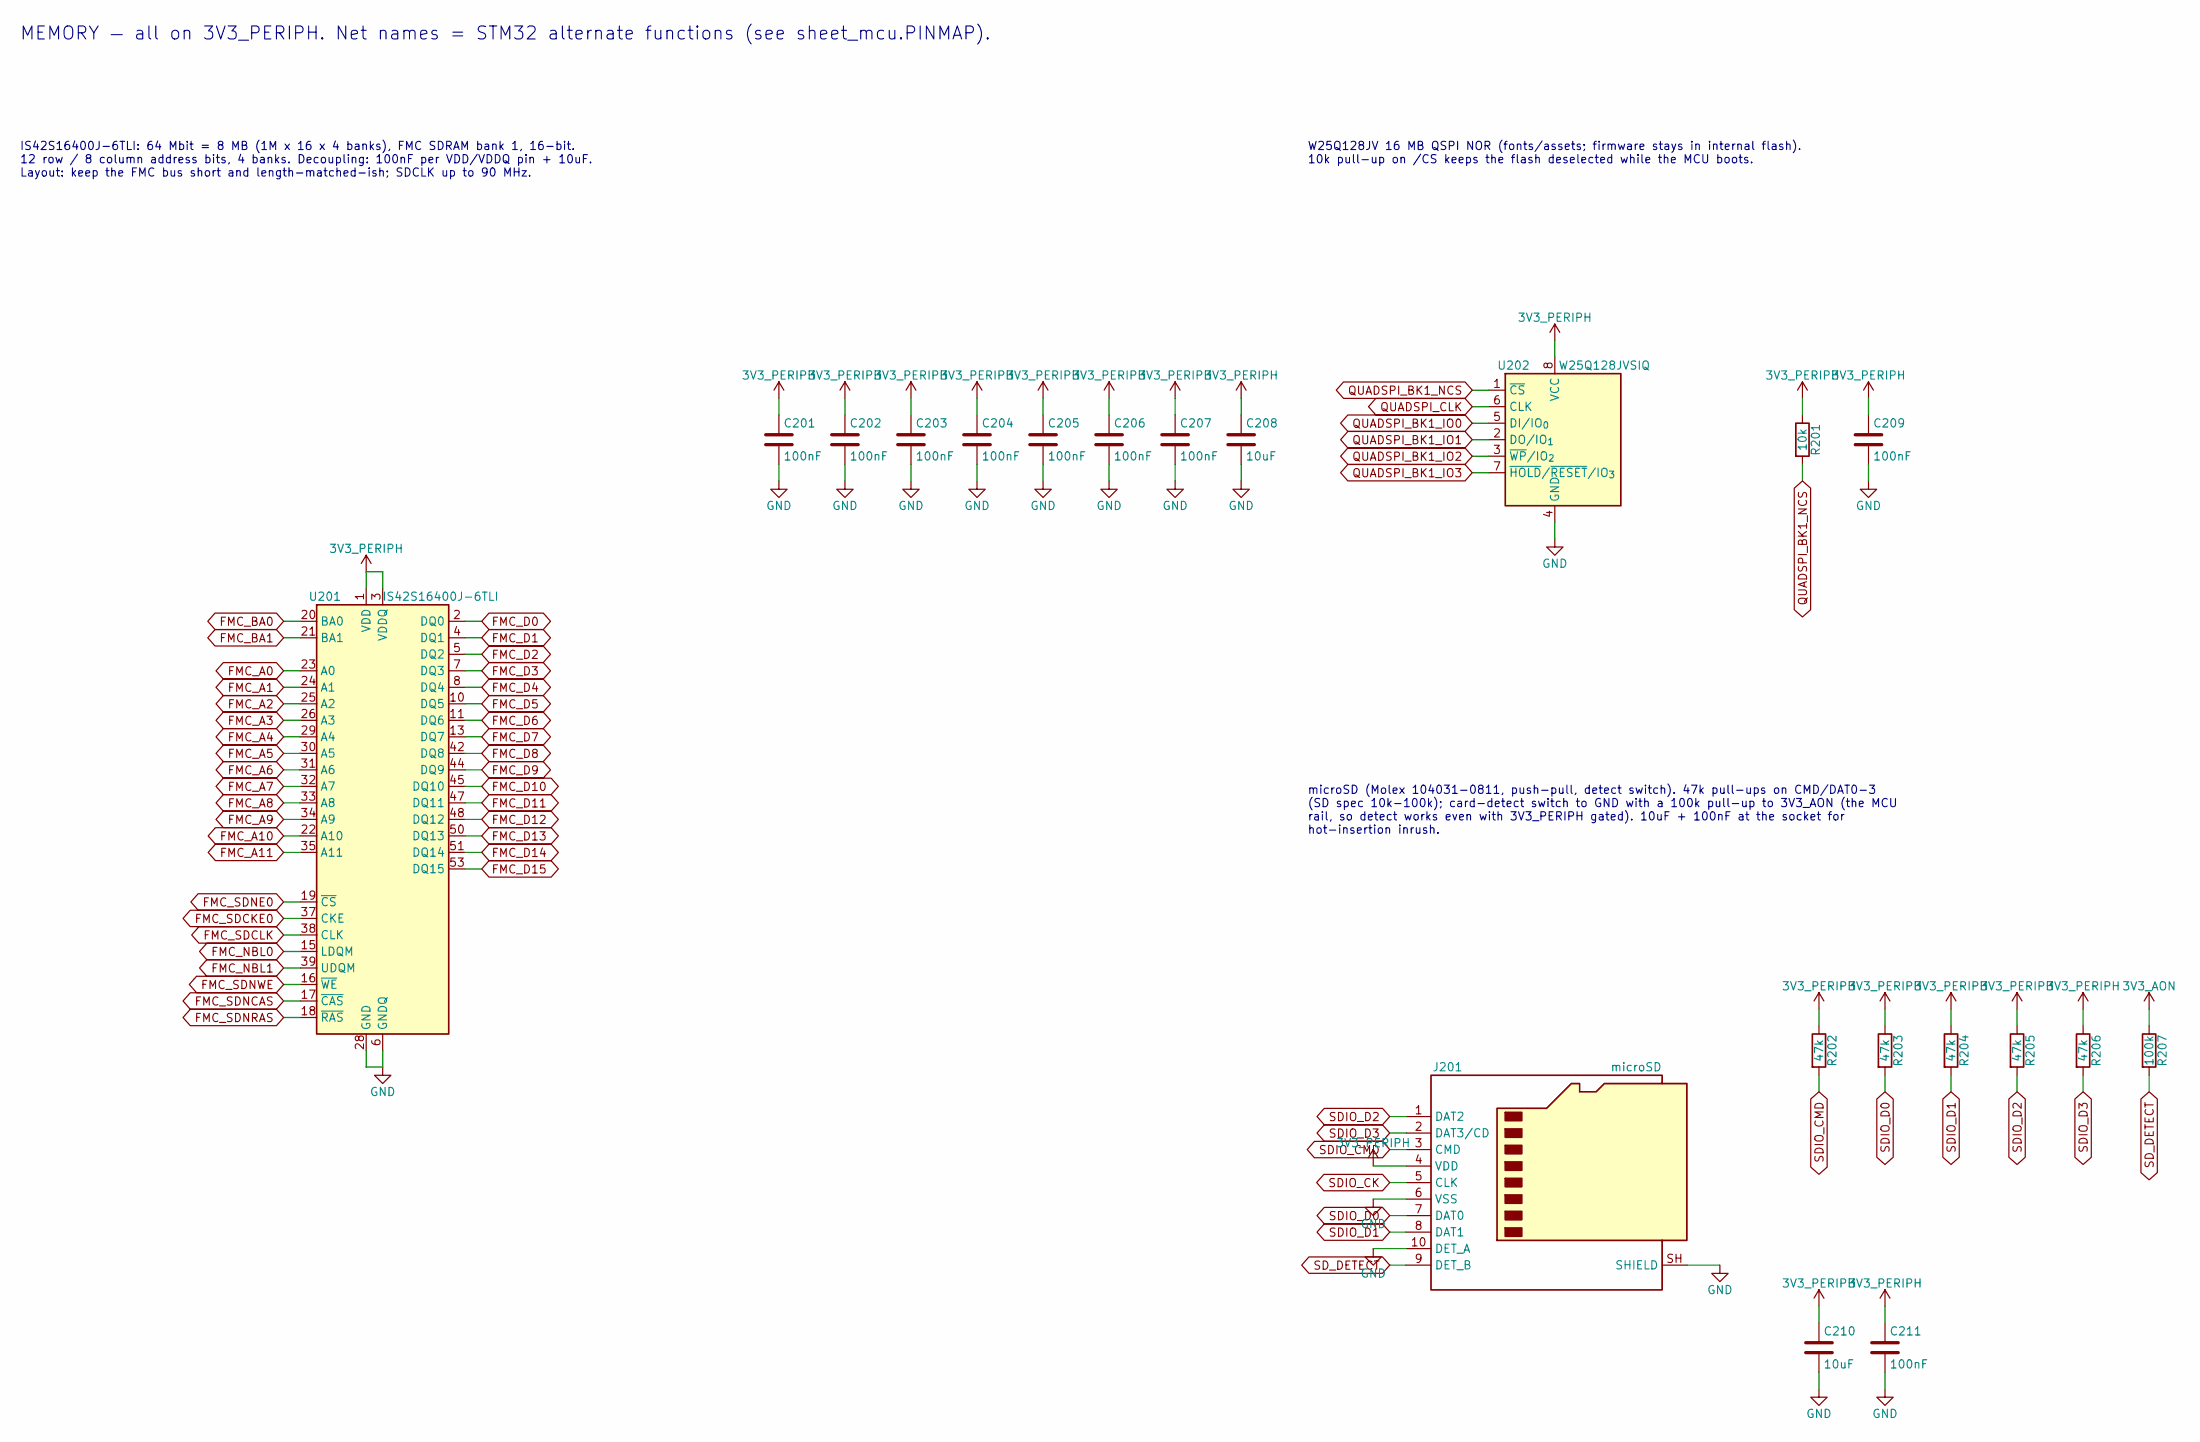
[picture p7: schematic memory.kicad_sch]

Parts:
C201, C202, C203, C204, C205, C206, C207, C209, C211: 100nF; C_0402_1005Metric
C208: 10uF; C_0805_2012Metric
C210: 10uF; C_0603_1608Metric
J201: microSD; microSD_HC_Molex_104031-0811; MPN Molex 1040310811
R201: 10k; R_0402_1005Metric
R202, R203, R204, R205, R206: 47k; R_0402_1005Metric
R207: 100k; R_0402_1005Metric
U201: IS42S16400J-6TLI; TSOP-II-54_22.2x10.16mm_P0.8mm; MPN IS42S16400J-6TLI
U202: W25Q128JVSIQ; SOIC-8_5.3x5.3mm_P1.27mm; MPN W25Q128JVSIQ

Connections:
3V3_AON: R207.1; also elsewhere on the board
3V3_PERIPH: C201.1, C202.1, C203.1, C204.1, C205.1, C206.1, C207.1, C208.1, C209.1, C210.1, C211.1, J201.4 (VDD), R201.1, R202.1, R203.1, R204.1, R205.1, R206.1, U201.1 (VDD), U201.3 (VDDQ), U201.9 (VDDQ), U201.14 (VDD), U201.27 (VDD), U201.43 (VDDQ), U201.49 (VDDQ), U202.8 (VCC); also elsewhere on the board
FMC_A0: U201.23 (A0); also elsewhere on the board
FMC_A1: U201.24 (A1); also elsewhere on the board
FMC_A2: U201.25 (A2); also elsewhere on the board
FMC_A3: U201.26 (A3); also elsewhere on the board
FMC_A4: U201.29 (A4); also elsewhere on the board
FMC_A5: U201.30 (A5); also elsewhere on the board
FMC_A6: U201.31 (A6); also elsewhere on the board
FMC_A7: U201.32 (A7); also elsewhere on the board
FMC_A8: U201.33 (A8); also elsewhere on the board
FMC_A9: U201.34 (A9); also elsewhere on the board
FMC_A10: U201.22 (A10); also elsewhere on the board
FMC_A11: U201.35 (A11); also elsewhere on the board
FMC_BA0: U201.20 (BA0); also elsewhere on the board
FMC_BA1: U201.21 (BA1); also elsewhere on the board
FMC_D0: U201.2 (DQ0); also elsewhere on the board
FMC_D1: U201.4 (DQ1); also elsewhere on the board
FMC_D2: U201.5 (DQ2); also elsewhere on the board
FMC_D3: U201.7 (DQ3); also elsewhere on the board
FMC_D4: U201.8 (DQ4); also elsewhere on the board
FMC_D5: U201.10 (DQ5); also elsewhere on the board
FMC_D6: U201.11 (DQ6); also elsewhere on the board
FMC_D7: U201.13 (DQ7); also elsewhere on the board
FMC_D8: U201.42 (DQ8); also elsewhere on the board
FMC_D9: U201.44 (DQ9); also elsewhere on the board
FMC_D10: U201.45 (DQ10); also elsewhere on the board
FMC_D11: U201.47 (DQ11); also elsewhere on the board
FMC_D12: U201.48 (DQ12); also elsewhere on the board
FMC_D13: U201.50 (DQ13); also elsewhere on the board
FMC_D14: U201.51 (DQ14); also elsewhere on the board
FMC_D15: U201.53 (DQ15); also elsewhere on the board
FMC_NBL0: U201.15 (LDQM); also elsewhere on the board
FMC_NBL1: U201.39 (UDQM); also elsewhere on the board
FMC_SDCKE0: U201.37 (CKE); also elsewhere on the board
FMC_SDCLK: U201.38 (CLK); also elsewhere on the board
FMC_SDNCAS: U201.17 (~CAS); also elsewhere on the board
FMC_SDNE0: U201.19 (~CS); also elsewhere on the board
FMC_SDNRAS: U201.18 (~RAS); also elsewhere on the board
FMC_SDNWE: U201.16 (~WE); also elsewhere on the board
GND: C201.2, C202.2, C203.2, C204.2, C205.2, C206.2, C207.2, C208.2, C209.2, C210.2, C211.2, J201.6 (VSS), J201.10 (DET_A), J201.SH (SHIELD), U201.6 (GNDQ), U201.12 (GNDQ), U201.28 (GND), U201.41 (GND), U201.46 (GNDQ), U201.52 (GNDQ), U201.54 (GND), U202.4 (GND); also elsewhere on the board
QUADSPI_BK1_IO0: U202.5 (DI/IO_{0}); also elsewhere on the board
QUADSPI_BK1_IO1: U202.2 (DO/IO_{1}); also elsewhere on the board
QUADSPI_BK1_IO2: U202.3 (~WP/IO_{2}); also elsewhere on the board
QUADSPI_BK1_IO3: U202.7 (~HOLD/~RESET/IO_{3}); also elsewhere on the board
QUADSPI_BK1_NCS: R201.2, U202.1 (~CS); also elsewhere on the board
QUADSPI_CLK: U202.6 (CLK); also elsewhere on the board
SDIO_CK: J201.5 (CLK); also elsewhere on the board
SDIO_CMD: J201.3 (CMD), R202.2; also elsewhere on the board
SDIO_D0: J201.7 (DAT0), R203.2; also elsewhere on the board
SDIO_D1: J201.8 (DAT1), R204.2; also elsewhere on the board
SDIO_D2: J201.1 (DAT2), R205.2; also elsewhere on the board
SDIO_D3: J201.2 (DAT3/CD), R206.2; also elsewhere on the board
SD_DETECT: J201.9 (DET_B), R207.2; also elsewhere on the board

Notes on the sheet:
MEMORY — all on 3V3_PERIPH. Net names = STM32 alternate functions (see sheet_mcu.PINMAP).
IS42S16400J-6TLI: 64 Mbit = 8 MB (1M x 16 x 4 banks), FMC SDRAM bank 1, 16-bit. 12 row / 8 column address bits, 4 banks. Decoupling: 100nF per VDD/VDDQ pin + 10uF. Layout: keep the FMC bus short and length-matched-ish; SDCLK up to 90 MHz.
W25Q128JV 16 MB QSPI NOR (fonts/assets; firmware stays in internal flash). 10k pull-up on /CS keeps the flash deselected while the MCU boots.
microSD (Molex 104031-0811, push-pull, detect switch). 47k pull-ups on CMD/DAT0-3 (SD spec 10k-100k); card-detect switch to GND with a 100k pull-up to 3V3_AON (the MCU rail, so detect works even with 3V3_PERIPH gated). 10uF + 100nF at the socket for hot-insertion inrush.

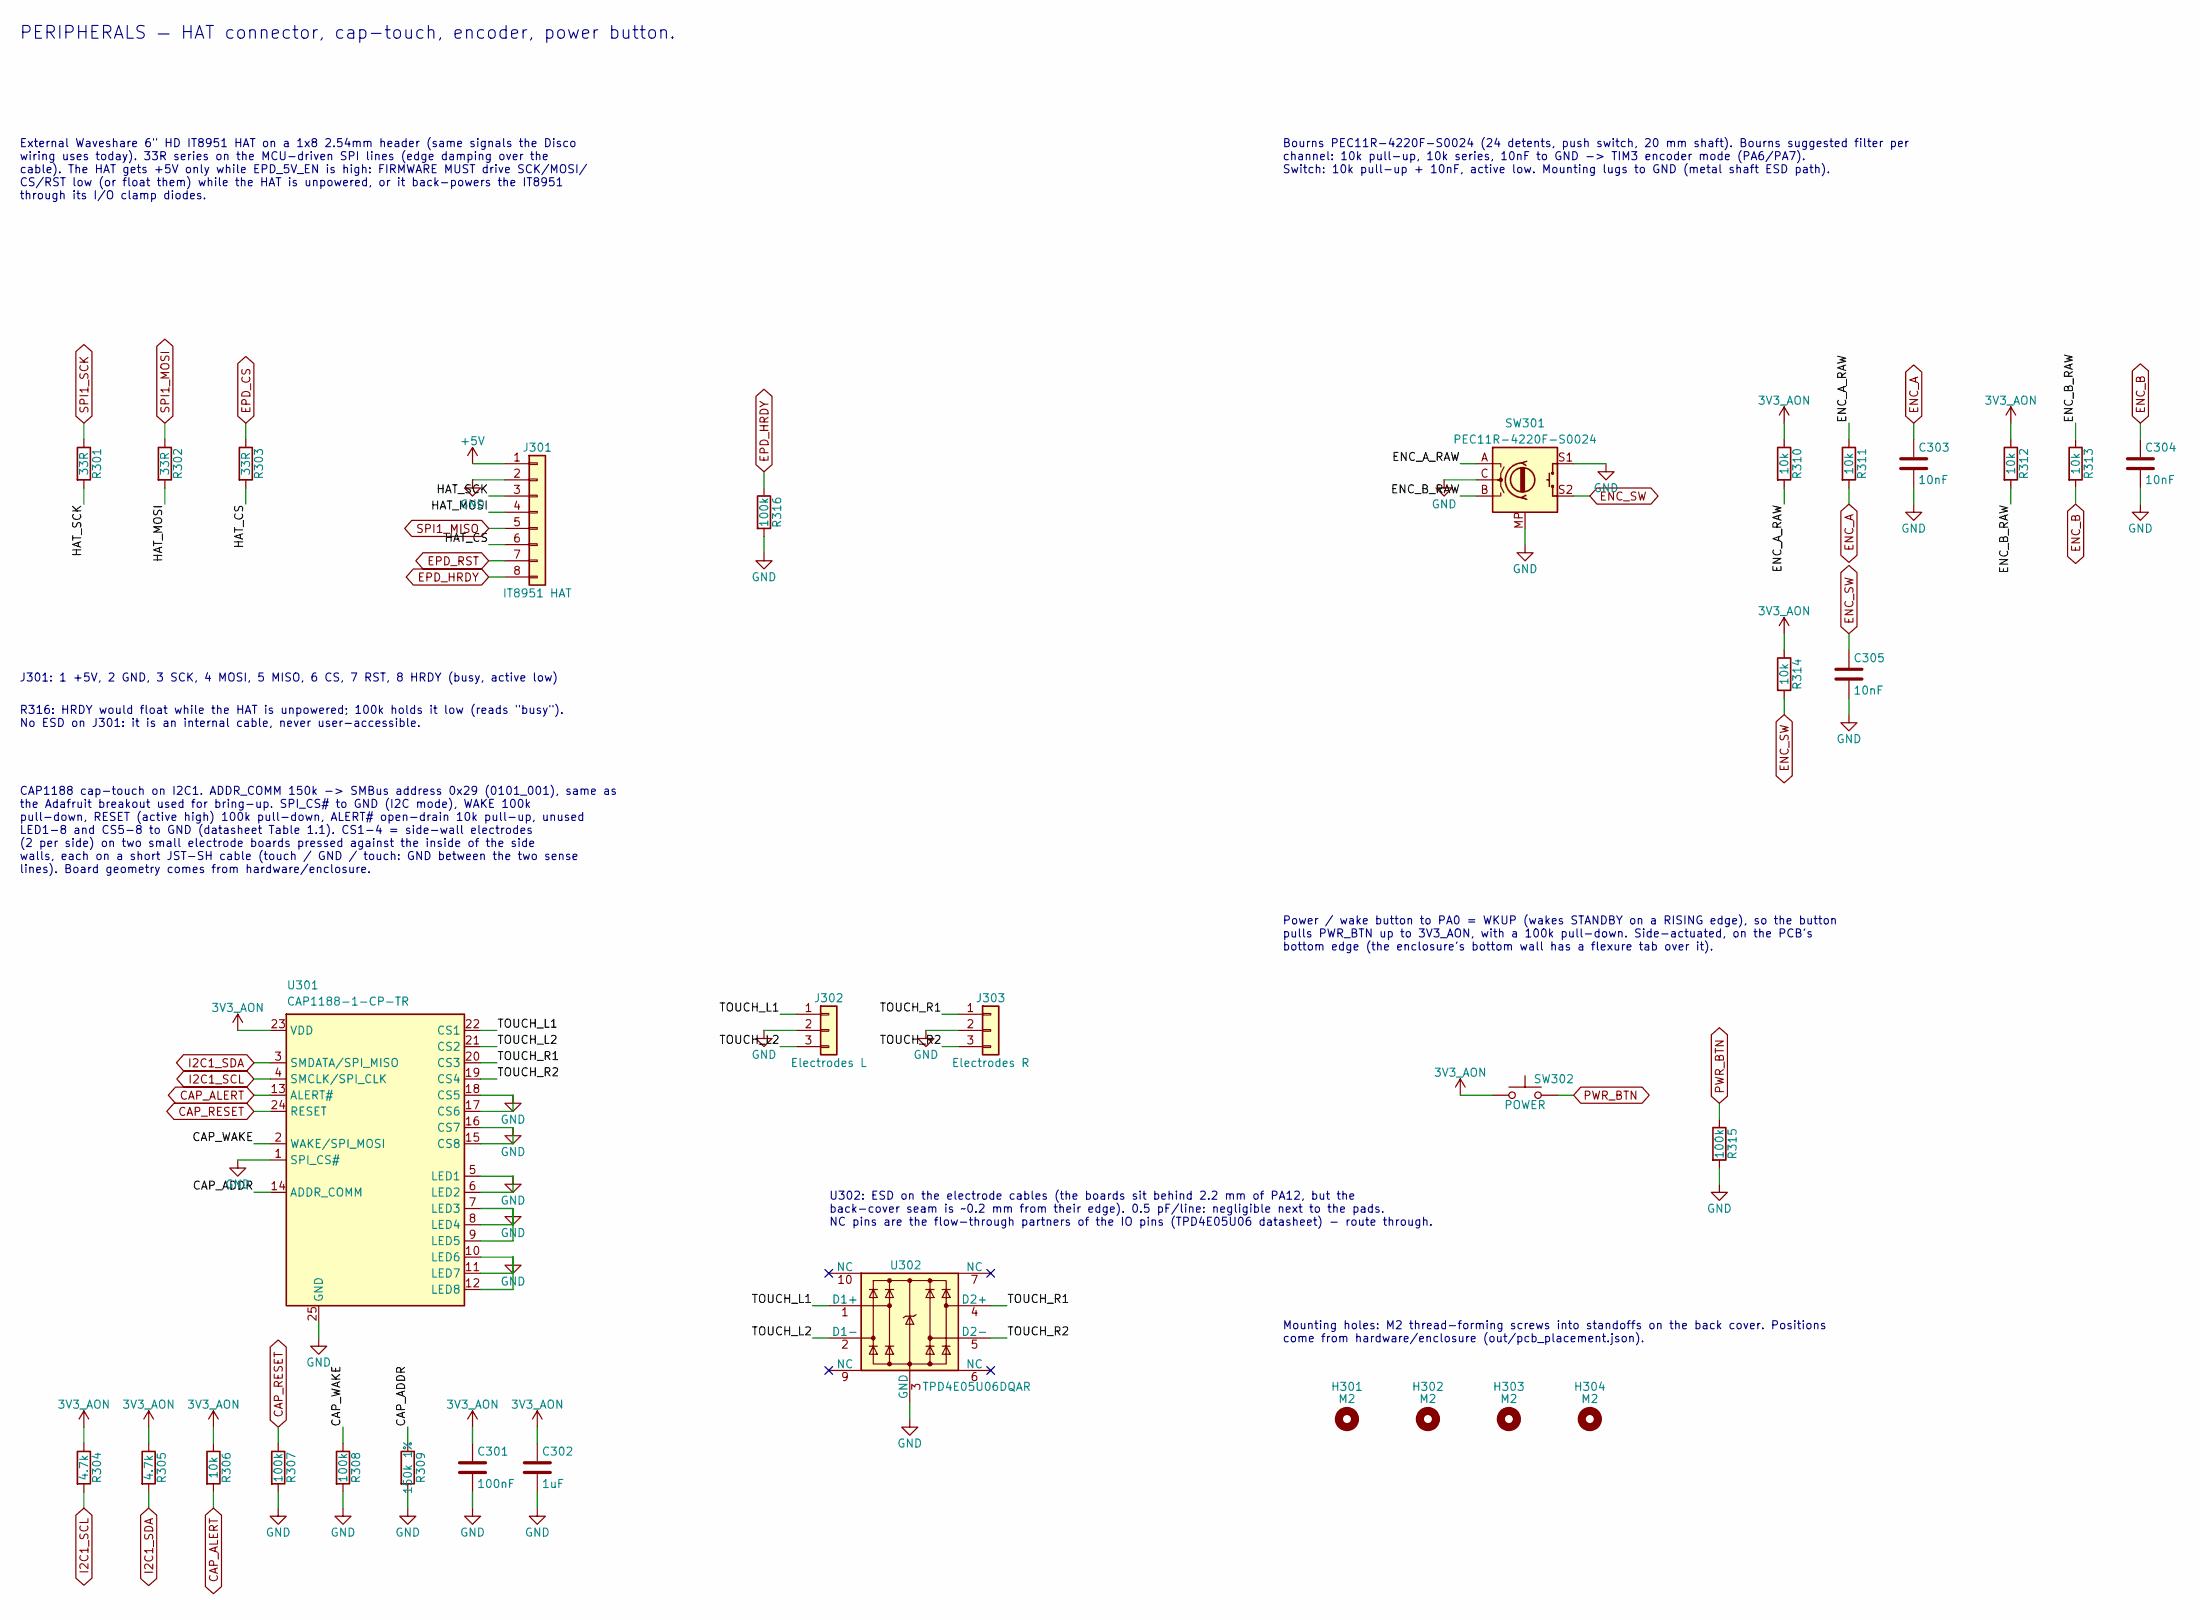
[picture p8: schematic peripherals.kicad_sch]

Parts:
C301: 100nF; C_0402_1005Metric
C302: 1uF; C_0402_1005Metric
C303, C304, C305: 10nF; C_0402_1005Metric
H301, H302, H303, H304: M2; MountingHole_2.2mm_M2
J301: IT8951 HAT; PinHeader_1x08_P2.54mm_Vertical
J302: Electrodes L; JST_SH_SM03B-SRSS-TB_1x03-1MP_P1.00mm_Horizontal; MPN SM03B-SRSS-TB
J303: Electrodes R; JST_SH_SM03B-SRSS-TB_1x03-1MP_P1.00mm_Horizontal; MPN SM03B-SRSS-TB
R301, R302, R303: 33R; R_0402_1005Metric
R304, R305: 4.7k; R_0402_1005Metric
R306, R310, R311, R312, R313, R314: 10k; R_0402_1005Metric
R307, R308, R315, R316: 100k; R_0402_1005Metric
R309: 150k 1%; R_0402_1005Metric
SW301: PEC11R-4220F-S0024; RotaryEncoder_Bourns_Vertical_PEC11R-4xxxF-Sxxxx; MPN PEC11R-4220F-S0024
SW302: POWER; SW_Push_1P1T-MP_NO_Horizontal_Alps_SKRTLAE010; MPN SKRTLAE010
U301: CAP1188-1-CP-TR; QFN-24-1EP_4x4mm_P0.5mm_EP2.5x2.5mm; MPN CAP1188-1-CP-TR
U302: TPD4E05U06DQAR; USON-10_2.5x1.0mm_P0.5mm; MPN TPD4E05U06DQAR

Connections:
3V3_AON: C301.1, C302.1, R304.1, R305.1, R306.1, R310.1, R312.1, R314.1, SW302.1, U301.23 (VDD); also elsewhere on the board
+5V: J301.1; also elsewhere on the board
/Peripherals/CAP_ADDR: R309.1, U301.14 (ADDR_COMM)
/Peripherals/CAP_WAKE: R308.1, U301.2 (WAKE/SPI_MOSI)
/Peripherals/ENC_A_RAW: R310.2, R311.1, SW301.A
/Peripherals/ENC_B_RAW: R312.2, R313.1, SW301.B
/Peripherals/HAT_CS: J301.6, R303.2
/Peripherals/HAT_MOSI: J301.4, R302.2
/Peripherals/HAT_SCK: J301.3, R301.2
/Peripherals/TOUCH_L1: J302.1, U301.22 (CS1), U302.1 (D1+)
/Peripherals/TOUCH_L2: J302.3, U301.21 (CS2), U302.2 (D1-)
/Peripherals/TOUCH_R1: J303.1, U301.20 (CS3), U302.4 (D2+)
/Peripherals/TOUCH_R2: J303.3, U301.19 (CS4), U302.5 (D2-)
CAP_ALERT: R306.2, U301.13 (ALERT#); also elsewhere on the board
CAP_RESET: R307.1, U301.24 (RESET); also elsewhere on the board
ENC_A: C303.1, R311.2; also elsewhere on the board
ENC_B: C304.1, R313.2; also elsewhere on the board
ENC_SW: C305.1, R314.2, SW301.S2; also elsewhere on the board
EPD_CS: R303.1; also elsewhere on the board
EPD_HRDY: J301.8, R316.1; also elsewhere on the board
EPD_RST: J301.7; also elsewhere on the board
GND: C301.2, C302.2, C303.2, C304.2, C305.2, J301.2, J302.2, J303.2, R307.2, R308.2, R309.2, R315.2, R316.2, SW301.C, SW301.MP, SW301.S1, U301.1 (SPI_CS#), U301.5 (LED1), U301.6 (LED2), U301.7 (LED3), U301.8 (LED4), U301.9 (LED5), U301.10 (LED6), U301.11 (LED7), U301.12 (LED8), U301.15 (CS8), U301.16 (CS7), U301.17 (CS6), U301.18 (CS5), U301.25 (GND), U302.3 (GND), U302.8 (GND); also elsewhere on the board
I2C1_SCL: R304.2, U301.4 (SMCLK/SPI_CLK); also elsewhere on the board
I2C1_SDA: R305.2, U301.3 (SMDATA/SPI_MISO); also elsewhere on the board
PWR_BTN: R315.1, SW302.2; also elsewhere on the board
SPI1_MISO: J301.5; also elsewhere on the board
SPI1_MOSI: R302.1; also elsewhere on the board
SPI1_SCK: R301.1; also elsewhere on the board

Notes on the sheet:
PERIPHERALS — HAT connector, cap-touch, encoder, power button.
External Waveshare 6" HD IT8951 HAT on a 1x8 2.54mm header (same signals the Disco wiring uses today). 33R series on the MCU-driven SPI lines (edge damping over the cable). The HAT gets +5V only while EPD_5V_EN is high: FIRMWARE MUST drive SCK/MOSI/ CS/RST low (or float them) while the HAT is unpow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
J301: 1 +5V, 2 GND, 3 SCK, 4 MOSI, 5 MISO, 6 CS, 7 RST, 8 HRDY (busy, active low)
R316: HRDY would float while the HAT is unpowered; 100k holds it low (reads "busy"). No ESD on J301: it is an internal cable, never user-accessible.
CAP1188 cap-touch on I2C1. ADDR_COMM 150k -> SMBus address 0x29 (0101_001), same as the Adafruit breakout used for bring-up. SPI_CS# to GND (I2C mode), WAKE 100k pull-down, RESET (active high) 100k pull-down, ALERT# open-drain 10k pull-up, unused LED1-8 and CS5-8 to GND (datasheet Table 1.1). CS1-4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
U302: ESD on the electrode cables (the boards sit behind 2.2 mm of PA12, but the back-cover seam is ~0.2 mm from their edge). 0.5 pF/line: negligible next to the pads. NC pins are the flow-through partners of the IO pins (TPD4E05U06 datasheet) - route through.
Bourns PEC11R-4220F-S0024 (24 detents, push switch, 20 mm shaft). Bourns suggested filter per channel: 10k pull-up, 10k series, 10nF to GND -> TIM3 encoder mode (PA6/PA7). Switch: 10k pull-up + 10nF, active low. Mounting lugs to GND (metal shaft ESD path).
Power / wake button to PA0 = WKUP (wakes STANDBY on a RISING edge), so the button pulls PWR_BTN up to 3V3_AON, with a 100k pull-down. Side-actuated, on the PCB's bottom edge (the enclosure's bottom wall has a flexure tab over it).
Mounting holes: M2 thread-forming screws into standoffs on the back cover. Positions come from hardware/enclosure (out/pcb_placement.json).

Board: 4 copper layers, 152 parts (0 on the bottom side), 132 nets, no tracks yet.

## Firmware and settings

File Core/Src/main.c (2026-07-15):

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
/* Includes ------------------------------------------------------------------*/
#include "main.h"
#include "cmsis_os.h"
#include "fatfs.h"
#include "usb_host.h"

/* USER CODE BEGIN Includes */
#include <stdio.h>
#include <stdarg.h>
#include <string.h>
#include "EPD_IT8951.h"
#include "EPD_Text.h"
#include "EPD_Layout.h"
#include "EPUB_Book.h"
/* USER CODE END Includes */

/* USER CODE BEGIN PD */
/* This panel's VCOM, read off its FPC cable: -2.59V, passed as an mV magnitude. */
#define IT8951_VCOM_MV 2590

/* Chunk size (words) for EPD_IT8951_4bp_Refresh_Chunked - see its declaration
   in EPD_IT8951.h. 2048 is comfortably within the ~2500-word burst size
   already confirmed safe on real hardware, leaving some margin. */
#define IT8951_WRITE_CHUNK_WORDS ((uint32_t)2048)

/* FMC/SDRAM: onboard MT48LC4M32B2B5-6A (128Mbit = 16MB), FMC bank 1.
   Values match ST's own BSP_SDRAM_Init()/Initialization_sequence() for this
   exact chip (stm32469i_discovery_sdram.c) - CubeMX only configures the FMC
   controller's timing (HAL_SDRAM_Init); the SDRAM chip's own JEDEC power-up
   command sequence (clock enable/precharge/auto-refresh/mode register) has
   to be sent separately, which is what MX_FMC_Init's USER CODE section below
   does. */
#define SDRAM_BASE_ADDR  ((uint32_t)0xC0000000)
#define SDRAM_SIZE_BYTES ((uint32_t)0x1000000) /* 16MB */
#define SDRAM_REFRESH_COUNT ((uint32_t)0x0569)
#define SDRAM_CMD_TIMEOUT   ((uint32_t)0xFFFF)

#define SDRAM_MODEREG_BURST_LENGTH_1          ((uint16_t)0x0000)
#define SDRAM_MODEREG_BURST_TYPE_SEQUENTIAL   ((uint16_t)0x0000)
#define SDRAM_MODEREG_CAS_LATENCY_3           ((uint16_t)0x0030)
#define SDRAM_MODEREG_OPERATING_MODE_STANDARD ((uint16_t)0x0000)
#define SDRAM_MODEREG_WRITEBURST_MODE_SINGLE  ((uint16_t)0x0200)

/* SDRAM partitioning: the IT8951 frame buffer lives at SDRAM_BASE_ADDR (max
   ~776KB for this panel at 4bpp - 1448*1072/2). Book text is read into a
   separate region well past that, leaving comfortable headroom for larger
   panels/future formats without the two overlapping. 4MB is far more than
   any plain-text book needs. */
#define TEXT_BUFFER_BASE      (SDRAM_BASE_ADDR + 0x100000) /* 1MB in */
#define TEXT_BUFFER_MAX_BYTES ((uint32_t)0x400000)         /* 4MB */

/* Scratch space for EPUB parsing (EPUB_Book_Open/GetChapterText) - staging
   compressed+decompressed XML/XHTML during ZIP extraction and parsing.
   Transient: not needed once a chapter's plain text has been produced into
   TEXT_BUFFER_BASE above, so it's fine for this to sit right after the text
   buffer rather than needing to coexist with it. */
#define EPUB_SCRATCH_BASE      (TEXT_BUFFER_BASE + TEXT_BUFFER_MAX_BYTES) /* 5MB in */
#define EPUB_SCRATCH_MAX_BYTES ((uint32_t)0x400000)                       /* 4MB */

/* Whole-file buffer for the .epub itself. Loaded once via a single
   sequential f_read() at open time, then treated as plain memory for every
   EPUB_IO read afterwards - see EpubIo_RamRead/RamSize below for why: real
   hardware testing found that repeated f_lseek()+f_read() calls to
   different offsets on the same file - specifically, alternating between
   reads near the end of the file (the ZIP central directory) and reads
   near the beginning (actual entry data) - reliably returned stale data
   for the earlier offset every time, and neither closing/reopening the
   file nor remounting the SD volume fixed it (both were tried and
   confirmed byte-for-byte identical failures on hardware). Since the whole
   file (a few hundred KB to a few MB for a typical book) fits easily in
   the 16MB of SDRAM, loading it once up front sidesteps the issue
   entirely rather than chasing it further into the FatFs/SDIO driver. */
#define EPUB_FILE_BUFFER_BASE      (EPUB_SCRATCH_BASE + EPUB_SCRATCH_MAX_BYTES) /* 9MB in */
#define EPUB_FILE_BUFFER_MAX_BYTES ((uint32_t)0x200000)                        /* 2MB */
/* USER CODE END PD */

CRC_HandleTypeDef hcrc;

DMA2D_HandleTypeDef hdma2d;

DSI_HandleTypeDef hdsi;

I2C_HandleTypeDef hi2c1;
I2C_HandleTypeDef hi2c2;

LTDC_HandleTypeDef hltdc;

QSPI_HandleTypeDef hqspi;

SAI_HandleTypeDef hsai_BlockA1;

SD_HandleTypeDef hsd;
DMA_HandleTypeDef hdma_sdio;

SPI_HandleTypeDef hspi1;

TIM_HandleTypeDef htim1;

UART_HandleTypeDef huart3;
UART_HandleTypeDef huart6;

SDRAM_HandleTypeDef hsdram1;

osThreadId defaultTaskHandle;
void SystemClock_Config(void);
void PeriphCommonClock_Config(void);
static void MX_GPIO_Init(void);
static void MX_DMA_Init(void);
static void MX_CRC_Init(void);
static void MX_DMA2D_Init(void);
static void MX_DSIHOST_DSI_Init(void);
static void MX_FMC_Init(void);
static void MX_I2C1_Init(void);
static void MX_I2C2_Init(void);
static void MX_LTDC_Init(void);
static void MX_QUADSPI_Init(void);
static void MX_SAI1_Init(void);
static void MX_SDIO_SD_Init(void);
static void MX_TIM1_Init(void);
static void MX_USART3_UART_Init(void);
static void MX_USART6_UART_Init(void);
static void MX_SPI1_Init(void);
void StartDefaultTask(void const * argument);

/**
  * @brief  The application entry point.
  * @retval int
  */
int main(void)
{

  /* MCU Configuration--------------------------------------------------------*/

  /* Reset of all peripherals, Initializes the Flash interface and the Systick. */
  HAL_Init();

  /* Configure the system clock */
  SystemClock_Config();

  /* Configure the peripherals common clocks */
  PeriphCommonClock_Config();

  /* Initialize all configured peripherals */
  MX_GPIO_Init();
  MX_DMA_Init();
  MX_CRC_Init();
  MX_DMA2D_Init();
  MX_DSIHOST_DSI_Init();
  MX_FMC_Init();
  MX_I2C1_Init();
  MX_I2C2_Init();
  MX_LTDC_Init();
  MX_QUADSPI_Init();
  MX_SAI1_Init();
  MX_SDIO_SD_Init();
  MX_TIM1_Init();
  MX_USART3_UART_Init();
  MX_USART6_UART_Init();
  MX_FATFS_Init();
  MX_SPI1_Init();
  /* USER CODE BEGIN RTOS_MUTEX */
  /* add mutexes, ... */
  /* USER CODE END RTOS_MUTEX */

  /* USER CODE BEGIN RTOS_SEMAPHORES */
  /* add semaphores, ... */
  /* USER CODE END RTOS_SEMAPHORES */

  /* USER CODE BEGIN RTOS_TIMERS */
  /* start timers, add new ones, ... */
  /* USER CODE END RTOS_TIMERS */

  /* USER CODE BEGIN RTOS_QUEUES */
  /* add queues, ... */
  /* USER CODE END RTOS_QUEUES */

  /* Create the thread(s) */
  /* definition and creation of defaultTask */
  osThreadDef(defaultTask, StartDefaultTask, osPriorityNormal, 0, 4096);
  defaultTaskHandle = osThreadCreate(osThread(defaultTask), NULL);

  /* USER CODE BEGIN RTOS_THREADS */
  /* add threads, ... */
  /* USER CODE END RTOS_THREADS */

  /* Start scheduler */
  osKernelStart();

  /* We should never get here as control is now taken by the scheduler */

  /* Infinite loop */
  /* USER CODE BEGIN WHILE */
  while (1)
  {
    /* USER CODE END WHILE */

    /* USER CODE BEGIN 3 */
  }
  /* USER CODE END 3 */
}

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
/* USER CODE BEGIN 4 */
int __io_putchar(int ch)
{
  HAL_UART_Transmit(&huart3, (uint8_t *)&ch, 1, HAL_MAX_DELAY);
  return ch;
}

/* Prefixes every printf() call below this point (via the #define printf
   below) with the current HAL tick (ms since boot), so serial output can be
   correlated with timing - e.g. exactly how long a given SPI/display
   operation took, or the gap between two prints. Defined using the real
   printf, before the macro that redirects "printf" to this function takes
   effect. */
static int timestamped_printf(const char *fmt, ...)
{
  va_list args;
  int ret;

  printf("[%8lu] ", (unsigned long)HAL_GetTick());

  va_start(args, fmt);
  ret = vprintf(fmt, args);
  va_end(args);

  return ret;
}
#define printf(...) timestamped_printf(__VA_ARGS__)

/* Full-range SDRAM read/write test: writes each 32-bit word its own address-
   derived value, reads it back, and reports any mismatches. Returns the
   number of mismatched words (0 = pass). */
static uint32_t SDRAM_Test(void)
{
  volatile uint32_t *sdram = (volatile uint32_t *)SDRAM_BASE_ADDR;
  uint32_t wordCount = SDRAM_SIZE_BYTES / sizeof(uint32_t);
  uint32_t errors = 0;

  for (uint32_t i = 0; i < wordCount; i++)
  {
    sdram[i] = i;
  }

  for (uint32_t i = 0; i < wordCount; i++)
  {
    uint32_t readBack = sdram[i];
    if (readBack != i)
    {
      errors++;
      if (errors <= 5)
      {
        printf("stm32-epaper: SDRAM mismatch at 0x%08lX: wrote %lu, read %lu\r\n",
               (unsigned long)(SDRAM_BASE_ADDR + i * sizeof(uint32_t)),
               (unsigned long)i, (unsigned long)readBack);
      }
    }
  }

  return errors;
}

/* EPUB_IO adapter over a plain in-RAM copy of the whole .epub file (loaded
   once via a single sequential f_read() - see main() call site and
   EPUB_FILE_BUFFER_BASE's comment for why: repeated f_lseek()+f_read()
   calls to different offsets on the same FatFs file handle - specifically
   alternating between reads near the end of the file (ZIP central
   directory) and reads near the beginning (actual entry data) - reliably
   returned stale data on real hardware, and neither closing/reopening the
   file nor remounting the SD volume fixed it. Once the file is fully in
   RAM, these are just bounds-checked memcpys - no FatFs involved, so
   nothing left to go stale. */
typedef struct
{
  const uint8_t *data;
  uint32_t size;
} EpubRamCtx;

static bool EpubIo_RamRead(void *ctx, uint32_t offset, void *buf, uint32_t len)
{
  EpubRamCtx *ram = (EpubRamCtx *)ctx;
  if ((uint64_t)offset + len > ram->size)
  {
    return false;
  }
  memcpy(buf, ram->data + offset, len);
  return true;
}

static uint32_t EpubIo_RamSize(void *ctx)
{
  return ((EpubRamCtx *)ctx)->size;
}

/* Case-insensitive ".epub" suffix check - used to spot a book file in the
   SD card's directory listing without assuming a fixed filename. Avoids
   depending on strcasecmp's availability. */
static bool EndsWithEpubExtension(const char *filename)
{
  size_t len = strlen(filename);
  if (len < 5)
  {
    return false;
  }
  const char *suffix = filename + len - 5;
  return (suffix[0] == '.') &&
         (suffix[1] == 'e' || suffix[1] == 'E') &&
         (suffix[2] == 'p' || suffix[2] == 'P') &&
         (suffix[3] == 'u' || suffix[3] == 'U') &&
         (suffix[4] == 'b' || suffix[4] == 'B');
}

/* Page-layout test content: public-domain text (opening of "Alice's
   Adventures in Wonderland"), long enough to exercise both word-wrap and
   pagination (EPD_Layout_DrawParagraph's returned continuation pointer)
   rather than just a one-line sample. */
static const char PageLayoutTestText[] =
  "Alice was beginning to get very tired of sitting by her sister on the "
  "bank, and of having nothing to do: once or twice she had peeped into "
  "the book her sister was reading, but it had no pictures or "
  "conversations in it, 'and what is the use of a book,' thought Alice "
  "'without pictures or conversations?'\n\n"
  "So she was considering in her own mind (as well as she could, for the "
  "hot day made her feel very sleepy and stupid), whether the pleasure of "
  "making a daisy-chain would be worth the trouble of getting up and "
  "picking the daisies, when suddenly a White Rabbit with pink eyes ran "
  "close by her.\n\n"
  "There was nothing so very remarkable in that; nor did Alice think it "
  "so very much out of the way to hear the Rabbit say to itself, 'Oh "
  "dear! Oh dear! I shall be late!' (when she thought it over afterwards, "
  "it occurred to her that she ought to have wondered at this, but at the "
  "time it all seemed quite natural); but when the Rabbit actually took a "
  "watch out of its waistcoat-pocket, and looked at it, and then hurried "
  "on, Alice started to her feet, for it flashed across her mind that she "
  "had never before seen a rabbit with either a waistcoat-pocket, or a "
  "watch to take out of it, and burning with curiosity, she ran across "
  "the field after it, and fortunately was just in time to see it pop "
  "down a large rabbit-hole under the hedge.";
/* USER CODE END 4 */

/* USER CODE BEGIN Header_StartDefaultTask */
/**
  * @brief  Function implementing the defaultTask thread.
  * @param  argument: Not used
  * @retval None
  */
/* USER CODE END Header_StartDefaultTask */
void StartDefaultTask(void const * argument)
{
  /* init code for USB_HOST */
  MX_USB_HOST_Init();
  /* USER CODE BEGIN 5 */
  printf("stm32-epaper: starting SDRAM test (%lu bytes)...\r\n", (unsigned long)SDRAM_SIZE_BYTES);
  uint32_t sdramErrors = SDRAM_Test();
  if (sdramErrors == 0)
  {
    printf("stm32-epaper: SDRAM test PASSED (%lu words verified).\r\n",
           (unsigned long)(SDRAM_SIZE_BYTES / sizeof(uint32_t)));
  }
  else
  {
    printf("stm32-epaper: SDRAM test FAILED (%lu word mismatches).\r\n",
           (unsigned long)sdramErrors);
  }

  /* Fallback text if the SD card/file isn't available - keeps the layout
     test working even without a card inserted. Overwritten below on a
     successful file read (ALICE.TXT, then a real EPUB if one is found -
     see the SD card block below). */
  const char *bookText = PageLayoutTestText;
  char bookTitle[EPUB_MAX_TITLE_LEN] = "";
  char epubFilename[128] = "";

  printf("stm32-epaper: mounting SD card...\r\n");
  {
    FRESULT fres = f_mount(&SDFatFS, SDPath, 1);
    if (fres != FR_OK)
    {
      printf("stm32-epaper: SD mount FAILED (FRESULT=%d)\r\n", (int)fres);
    }
    else
    {
      FATFS *fs;
      DWORD freeClusters;
      FILINFO fno;

      printf("stm32-epaper: SD mount OK.\r\n");

      if (f_getfree(SDPath, &freeClusters, &fs) == FR_OK)
      {
        uint32_t totalSectors = (fs->n_fatent - 2) * fs->csize;
        uint32_t freeSectors = freeClusters * fs->csize;
        printf("stm32-epaper: SD card: %lu MB total, %lu MB free\r\n",
               (unsigned long)(totalSectors / 2 / 1024),
               (unsigned long)(freeSectors / 2 / 1024));
      }

      /* Directory listing - useful to confirm what's actually on the card
         (e.g. a book file copied on via a card reader) without pulling the
         card and checking on another machine. Root directory only, not
         recursive - fine for how this card is actually being used. */
      {
        DIR dir;
        FILINFO listFno;
        fres = f_opendir(&dir, "/");
        if (fres != FR_OK)
        {
          printf("stm32-epaper: SD directory listing FAILED (FRESULT=%d)\r\n", (int)fres);
        }
        else
        {
          printf("stm32-epaper: SD card contents:\r\n");
          uint32_t fileCount = 0;
          for (;;)
          {
            fres = f_readdir(&dir, &listFno);
            if (fres != FR_OK || listFno.fname[0] == '\0')
            {
              break;
            }
            if (listFno.fattrib & AM_DIR)
            {
              printf("stm32-epaper:   %s/\r\n", listFno.fname);
            }
            else
            {
              printf("stm32-epaper:   %s (%lu bytes)\r\n", listFno.fname,
                     (unsigned long)listFno.fsize);
              if (epubFilename[0] == '\0' && EndsWithEpubExtension(listFno.fname))
              {
                strncpy(epubFilename, listFno.fname, sizeof(epubFilename) - 1);
                epubFilename[sizeof(epubFilename) - 1] = '\0';
              }
            }
            fileCount++;
          }
          f_closedir(&dir);
          printf("stm32-epaper: %lu entries total.\r\n", (unsigned long)fileCount);
        }
      }

      /* EPTEST.TXT is 8.3-compliant regardless, so this still works now that
         ffconf.h has _USE_LFN=3 (long filenames enabled - see ffconf.h for
         why 3, not 1 or 2) - long filenames like "epaper_test.txt" would
         have failed with FR_INVALID_NAME before that change. */
      static const char testStr[] = "stm32-epaper storage test\r\n";
      fres = f_open(&SDFile, "EPTEST.TXT", FA_CREATE_ALWAYS | FA_WRITE);
      if (fres != FR_OK)
      {
        printf("stm32-epaper: SD file create/open FAILED (FRESULT=%d)\r\n", (int)fres);
      }
      else
      {
        UINT bytesWritten;
        f_write(&SDFile, testStr, sizeof(testStr) - 1, &bytesWritten);
        f_close(&SDFile);
        printf("stm32-epaper: wrote %u bytes to EPTEST.TXT\r\n", bytesWritten);

        static char readBuf[64];
        UINT bytesRead;
        fres = f_open(&SDFile, "EPTEST.TXT", FA_READ);
        if (fres != FR_OK)
        {
          printf("stm32-epaper: SD read-back open FAILED (FRESULT=%d)\r\n", (int)fres);
        }
        else
        {
          f_read(&SDFile, readBuf, sizeof(readBuf) - 1, &bytesRead);
          f_close(&SDFile);
          readBuf[bytesRead] = '\0';
          printf("stm32-epaper: read back %u bytes: \"%s\"\r\n", bytesRead, readBuf);

          if (bytesRead == sizeof(testStr) - 1 && memcmp(readBuf, testStr, bytesRead) == 0)
          {
            printf("stm32-epaper: SD read/write test PASSED.\r\n");
          }
          else
          {
            printf("stm32-epaper: SD read/write test FAILED (content mismatch).\r\n");
          }
        }
      }

      /* Ebook text milestone: read a real file from the SD card instead of
         the embedded PageLayoutTestText string, proving the actual
         file-read -> paginate -> render pipeline. There's no way yet to
         copy an arbitrary file onto this physically-connected card from the
         dev host (see TODO.md) - so for now the firmware self-seeds
         ALICE.TXT with that same public-domain text on first boot if it's
         missing, then always reads whatever is actually on the card. A
         real book just needs to replace/append to this file by any means
         (USB mass storage mode, a card reader, etc.) - the read/paginate
         path underneath doesn't change. */
      fres = f_stat("ALICE.TXT", &fno);
      if (fres == FR_NO_FILE)
      {
        printf("stm32-epaper: ALICE.TXT not found, seeding with embedded test text "
               "(%u bytes)...\r\n", (unsigned)(sizeof(PageLayoutTestText) - 1));
        fres = f_open(&SDFile, "ALICE.TXT", FA_CREATE_ALWAYS | FA_WRITE);
        if (fres != FR_OK)
        {
          printf("stm32-epaper: ALICE.TXT create FAILED (FRESULT=%d)\r\n", (int)fres);
        }
        else
        {
          UINT seedWritten;
          f_write(&SDFile, PageLayoutTestText, sizeof(PageLayoutTestText) - 1, &seedWritten);
          f_close(&SDFile);
          printf("stm32-epaper: wrote %u bytes to ALICE.TXT\r\n", seedWritten);
        }
      }

      fres = f_open(&SDFile, "ALICE.TXT", FA_READ);
      if (fres != FR_OK)
      {
        printf("stm32-epaper: ALICE.TXT open FAILED (FRESULT=%d), using embedded text\r\n",
               (int)fres);
      }
      else
      {
        UINT bookBytesRead;
        char *textBuf = (char *)TEXT_BUFFER_BASE;
        fres = f_read(&SDFile, textBuf, TEXT_BUFFER_MAX_BYTES - 1, &bookBytesRead);
        f_close(&SDFile);
        if (fres == FR_OK)
        {
          textBuf[bookBytesRead] = '\0';
          bookText = textBuf;
          printf("stm32-epaper: read %u bytes from ALICE.TXT\r\n", bookBytesRead);
        }
        else
        {
          printf("stm32-epaper: ALICE.TXT read FAILED (FRESULT=%d), using embedded text\r\n",
                 (int)fres);
        }
      }

      /* Real EPUB milestone: if a .epub file was spotted in the directory
         listing above, open it, parse it (container.xml -> OPF -> spine),
         and extract chapter 1's plain text - overriding ALICE.TXT/the
         embedded fallback above, same override pattern as ALICE.TXT itself
         used against the plain embedded string. EPUB_Book is ~26KB
         (mostly its spine href table) - too big for this task's stack, so
         it's static (BSS), not a local. */
      if (epubFilename[0] != '\0')
      {
        printf("stm32-epaper: found EPUB \"%s\", opening...\r\n", epubFilename);
        fres = f_open(&SDFile, epubFilename, FA_READ);
        if (fres != FR_OK)
        {
          printf("stm32-epaper: EPUB open FAILED (FRESULT=%d), using ALICE.TXT/embedded "
                 "text\r\n", (int)fres);
        }
        else if (f_size(&SDFile) > EPUB_FILE_BUFFER_MAX_BYTES)
        {
          printf("stm32-epaper: EPUB too big for the %lu-byte file buffer (%lu bytes), "
                 "using ALICE.TXT/embedded text\r\n", (unsigned long)EPUB_FILE_BUFFER_MAX_BYTES,
                 (unsigned long)f_size(&SDFile));
          f_close(&SDFile);
        }
        else
        {
          /* Single sequential read of the whole file - see EpubRamCtx's
             comment for why this replaced per-offset FatFs reads. */
          uint8_t *epubFileBuf = (uint8_t *)EPUB_FILE_BUFFER_BASE;
          UINT epubBytesRead;
          fres = f_read(&SDFile, epubFileBuf, f_size(&SDFile), &epubBytesRead);
          uint32_t epubFileSize = (uint32_t)epubBytesRead;
          f_close(&SDFile);

          if (fres != FR_OK)
          {
            printf("stm32-epaper: EPUB read FAILED (FRESULT=%d), using ALICE.TXT/embedded "
                   "text\r\n", (int)fres);
          }
          else
          {
            static EpubRamCtx epubCtx;
            epubCtx.data = epubFileBuf;
            epubCtx.size = epubFileSize;
            EPUB_IO io = { .ctx = &epubCtx, .read = EpubIo_RamRead, .size = EpubIo_RamSize,
                           .reset = NULL };
            uint8_t *epubScratch = (uint8_t *)EPUB_SCRATCH_BASE;
            static EPUB_Book book;

            if (!EPUB_Book_Open(&book, io, epubScratch, EPUB_SCRATCH_MAX_BYTES))
            {
              printf("stm32-epaper: EPUB parsing FAILED (not a supported EPUB?), using "
                     "ALICE.TXT/embedded text\r\n");
            }
            else
            {
              printf("stm32-epaper: EPUB opened. Title=\"%s\" Chapters=%u\r\n", book.title,
                     book.spineCount);
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

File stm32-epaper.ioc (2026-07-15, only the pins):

Mcu.UserName=STM32F469NIHx
PA0/WKUP.GPIO_Label=WAKEUP [B2]
PA0/WKUP.Signal=SYS_WKUP
PA10.GPIO_Label=USB_FS1_ID
PA10.Signal=USB_OTG_FS_ID
PA11.GPIO_Label=USB_FS1_N
PA11.Signal=USB_OTG_FS_DM
PA12.GPIO_Label=USB_FS1_P
PA12.Signal=USB_OTG_FS_DP
PA13.GPIO_Label=SWDIO
PA13.Signal=SYS_JTMS-SWDIO
PA14.GPIO_Label=SWCLK
PA14.Signal=SYS_JTCK-SWCLK
PA2.GPIO_Label=HRDY
PA2.Signal=GPIO_Input
PA3.GPIO_Label=LCD_BL_CTRL [STLD40DPUR_EN]
PA3.Signal=GPIO_Output
PA4.GPIO_Label=SPI1_CS
PA4.Signal=GPIO_Output
PA5.Signal=SPI1_SCK
PA9.GPIO_Label=VBUS_FS1
PA9.Signal=USB_OTG_FS_VBUS
PB0.GPIO_Label=EXT_RESET
PB0.Signal=GPIO_Output
PB1.GPIO_Label=RST
PB1.Signal=GPIO_Output
PB10.GPIO_Label=STLK_RX [STLINK V2-1_U2_RX]
PB10.Signal=USART3_TX
PB11.GPIO_Label=STLK_TX [STLINK V2-1_U2_TX]
PB11.Signal=USART3_RX
PB2/BOOT1.GPIO_Label=OTG_FS1_PowerSwitchOn [STMPS2151STR_En]
PB2/BOOT1.Signal=GPIO_Output
PB3.GPIO_Label=I2S3_CK
PB3.Signal=I2S3_CK
PB4.Signal=SPI1_MISO
PB5.Signal=SPI1_MOSI
PB6.GPIO_Label=QSPI_BK1_NCS [N25Q128A13EF840F_S]
PB6.Signal=QUADSPI_BK1_NCS
PB7.GPIO_Label=OTG_FS1_OverCurrent [STMPS2151STR_FAULT]
PB7.Signal=GPXTI7
PB8.GPIO_Label=I2C1_SCL
PB8.Signal=I2C1_SCL
PB9.GPIO_Label=I2C1_SDA
PB9.Signal=I2C1_SDA
PC0.GPIO_Label=SDNWE [MT48LC4M32B2B5-6A_WE]
PC0.Signal=FMC_SDNWE
PC10.GPIO_Label=uSD_D2
PC10.Signal=SDIO_D2
PC11.GPIO_Label=uSD_D3
PC11.Signal=SDIO_D3
PC12.GPIO_Label=uSD_CLK
PC12.Signal=SDIO_CK
PC14/OSC32_IN.Signal=RCC_OSC32_IN
PC15/OSC32_OUT.Signal=RCC_OSC32_OUT
PC8.GPIO_Label=uSD_D0
PC8.Signal=SDIO_D0
PC9.GPIO_Label=uSD_D1
PC9.Signal=SDIO_D1
PD0.GPIO_Label=D2
PD0.Signal=FMC_D2_DA2
PD1.GPIO_Label=D3
PD1.Signal=FMC_D3_DA3
PD10.GPIO_Label=D15
PD10.Signal=FMC_D15_DA15
PD13.GPIO_Label=MIC_CK [MP34DT01TR_CLK]
PD13.Signal=S_TIM4_CH2
PD14.GPIO_Label=D0
PD14.Signal=FMC_D0_DA0
PD15.GPIO_Label=D1
PD15.Signal=FMC_D1_DA1
PD2.GPIO_Label=uSD_CMD
PD2.Signal=SDIO_CMD
PD4.GPIO_Label=LED2 [Orange]
PD4.Signal=GPIO_Output
PD5.GPIO_Label=LED3 [Red]
PD5.Signal=GPIO_Output
PD6.GPIO_Label=MIC_DATA [MP34DT01TR_DOUT]
PD6.Signal=SAI1_SD_A
PD8.GPIO_Label=D13
PD8.Signal=FMC_D13_DA13
PD9.GPIO_Label=D14
PD9.Signal=FMC_D14_DA14
PE0.GPIO_Label=FMC_NBL0 [ MT48LC4M32B2B5-6A_DQM0]
PE0.Signal=FMC_NBL0
PE1.GPIO_Label=FMC_NBL1 [ MT48LC4M32B2B5-6A_DQM1]
PE1.Signal=FMC_NBL1
PE10.GPIO_Label=D7
PE10.Signal=FMC_D7_DA7
PE11.GPIO_Label=D8
PE11.Signal=FMC_D8_DA8
PE12.GPIO_Label=D9
PE12.Signal=FMC_D9_DA9
PE13.GPIO_Label=D10
PE13.Signal=FMC_D10_DA10
PE14.GPIO_Label=D11
PE14.Signal=FMC_D11_DA11
PE15.GPIO_Label=D12
PE15.Signal=FMC_D12_DA12
PE2.GPIO_Label=AUDIO_RST [CS43L22_RESET]
PE2.Signal=GPIO_Output
PE3.GPIO_Label=SPKR/HP [CS43L22_SPKR/HP]
PE3.Signal=GPIO_Output
PE4.GPIO_Label=SAI1_FSA [CS43L22_LRCK]
PE4.Signal=SAI1_FS_A
PE5.GPIO_Label=SAI1_SCKA [CS43L22_CLK]
PE5.Signal=SAI1_SCK_A
PE7.GPIO_Label=D4
PE7.Signal=FMC_D4_DA4
PE8.GPIO_Label=D5
PE8.Signal=FMC_D5_DA5
PE9.GPIO_Label=D6
PE9.Signal=FMC_D6_DA6
PF0.GPIO_Label=A0
PF0.Signal=FMC_A0
PF1.GPIO_Label=A1
PF1.Signal=FMC_A1
PF10.GPIO_Label=QSPI_CLK [N25Q128A13EF840F_C]
PF10.Signal=QUADSPI_CLK
PF11.GPIO_Label=SDNMT48LC4M32B2B5-6A_RAS]RAS [
PF11.Signal=FMC_SDNRAS
PF12.GPIO_Label=A6
PF12.Signal=FMC_A6
PF13.GPIO_Label=A7
PF13.Signal=FMC_A7
PF14.GPIO_Label=A8
PF14.Signal=FMC_A8
PF15.GPIO_Label=A9
PF15.Signal=FMC_A9
PF2.GPIO_Label=A2
PF2.Signal=FMC_A2
PF3.GPIO_Label=A3
PF3.Signal=FMC_A3
PF4.GPIO_Label=A4
PF4.Signal=FMC_A4
PF5.GPIO_Label=A5
PF5.Signal=FMC_A5
PF6.GPIO_Label=QSPI_BK1_IO3 [N25Q128A13EF840F_DQ3]
PF6.Signal=QUADSPI_BK1_IO3
PF7.GPIO_Label=QSPI_BK1_IO2 [N25Q128A13EF840F_DQ2]
PF7.Signal=QUADSPI_BK1_IO2
PF8.GPIO_Label=QSPI_BK1_IO0 [N25Q128A13EF840F_DQ0]
PF8.Signal=QUADSPI_BK1_IO0
PF9.GPIO_Label=QSPI_BK1_IO1 [N25Q128A13EF840F_DQ1]
PF9.Signal=QUADSPI_BK1_IO1
PG0.GPIO_Label=A10
PG0.Signal=FMC_A10
PG1.GPIO_Label=A11
PG1.Signal=FMC_A11
PG14.GPIO_Label=ARDUINO USART6_TX
PG14.Signal=USART6_TX
PG15.GPIO_Label=SDNCAS [MT48LC4M32B2B5-6A_CAS]
PG15.Signal=FMC_SDNCAS
PG2.GPIO_Label=uSD_Detect
PG2.Signal=GPIO_Input
PG4.Signal=FMC_A14_BA0
PG5.Signal=FMC_A15_BA1
PG6.GPIO_Label=LED1 [Green]
PG6.Signal=GPIO_Output
PG7.GPIO_Label=SAI1_MCLKA [CS43L22_MCLK]
PG7.Signal=SAI1_MCLK_A
PG8.GPIO_Label=SDCLK [MT48LC4M32B2B5-6A_CLK]
PG8.Signal=FMC_SDCLK
PG9.GPIO_Label=USART6_RX
PG9.Signal=USART6_RX
PH0/OSC_IN.Signal=RCC_OSC_IN
PH1/OSC_OUT.Signal=RCC_OSC_OUT
PH10.GPIO_Label=D18
PH10.Signal=FMC_D18
PH11.GPIO_Label=D19
PH11.Signal=FMC_D19
PH12.GPIO_Label=D20
PH12.Signal=FMC_D20
PH13.GPIO_Label=D21
PH13.Signal=FMC_D21
PH14.GPIO_Label=D22
PH14.Signal=FMC_D22
PH15.GPIO_Label=D23
PH15.Signal=FMC_D23
PH2.GPIO_Label=SDCKE0 [MT48LC4M32B2B5-6A_CKE]
PH2.Signal=FMC_SDCKE0
PH3.GPIO_Label=SDNE0 [MT48LC4M32B2B5-6A_CS]
PH3.Signal=FMC_SDNE0
PH4.GPIO_Label=I2C2_SCL [CS43L22_SCL]
PH4.Signal=I2C2_SCL
PH5.GPIO_Label=I2C2_SDA [CS43L22_SDA]
PH5.Signal=I2C2_SDA
PH7.Signal=GPIO_Output
PH8.GPIO_Label=D16
PH8.Signal=FMC_D16
PH9.GPIO_Label=D17
PH9.Signal=FMC_D17
PI0.GPIO_Label=D24
PI0.Signal=FMC_D24
PI1.GPIO_Label=D25
PI1.Signal=FMC_D25
PI10.GPIO_Label=D31
PI10.Signal=FMC_D31
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

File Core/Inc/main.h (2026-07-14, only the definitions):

#define SAI1_FSA_Pin GPIO_PIN_4
#define SAI1_FSA_GPIO_Port GPIOE
#define SPKR_HP_Pin GPIO_PIN_3
#define SPKR_HP_GPIO_Port GPIOE
#define AUDIO_RST_Pin GPIO_PIN_2
#define AUDIO_RST_GPIO_Port GPIOE
#define ARDUINO_USART6_TX_Pin GPIO_PIN_14
#define ARDUINO_USART6_TX_GPIO_Port GPIOG
#define FMC_NBL1_Pin GPIO_PIN_1
#define FMC_NBL1_GPIO_Port GPIOE
#define FMC_NBL0_Pin GPIO_PIN_0
#define FMC_NBL0_GPIO_Port GPIOE
#define I2C1_SCL_Pin GPIO_PIN_8
#define I2C1_SCL_GPIO_Port GPIOB
#define I2S3_CK_Pin GPIO_PIN_3
#define I2S3_CK_GPIO_Port GPIOB
#define uSD_CLK_Pin GPIO_PIN_12
#define uSD_CLK_GPIO_Port GPIOC
#define SWCLK_Pin GPIO_PIN_14
#define SWCLK_GPIO_Port GPIOA
#define SWDIO_Pin GPIO_PIN_13
#define SWDIO_GPIO_Port GPIOA
#define SAI1_SCKA_Pin GPIO_PIN_5
#define SAI1_SCKA_GPIO_Port GPIOE
#define I2C1_SDA_Pin GPIO_PIN_9
#define I2C1_SDA_GPIO_Port GPIOB
#define OTG_FS1_OverCurrent_Pin GPIO_PIN_7
#define OTG_FS1_OverCurrent_GPIO_Port GPIOB
#define QSPI_BK1_NCS_Pin GPIO_PIN_6
#define QSPI_BK1_NCS_GPIO_Port GPIOB
#define SDNCAS_Pin GPIO_PIN_15
#define SDNCAS_GPIO_Port GPIOG
#define MIC_DATA_Pin GPIO_PIN_6
#define MIC_DATA_GPIO_Port GPIOD
#define D2_Pin GPIO_PIN_0
#define D2_GPIO_Port GPIOD
#define uSD_D3_Pin GPIO_PIN_11
#define uSD_D3_GPIO_Port GPIOC
#define uSD_D2_Pin GPIO_PIN_10
#define uSD_D2_GPIO_Port GPIOC
#define USB_FS1_P_Pin GPIO_PIN_12
#define USB_FS1_P_GPIO_Port GPIOA
#define FMC_NBL2_Pin GPIO_PIN_4
#define FMC_NBL2_GPIO_Port GPIOI
#define LED3_Pin GPIO_PIN_5
#define LED3_GPIO_Port GPIOD
#define D3_Pin GPIO_PIN_1
#define D3_GPIO_Port GPIOD
#define D27_Pin GPIO_PIN_3
#define D27_GPIO_Port GPIOI
#define D26_Pin GPIO_PIN_2
#define D26_GPIO_Port GPIOI
#define USB_FS1_N_Pin GPIO_PIN_11
#define USB_FS1_N_GPIO_Port GPIOA
#define A0_Pin GPIO_PIN_0
#define A0_GPIO_Port GPIOF
#define FMC_NBL3_Pin GPIO_PIN_5
#define FMC_NBL3_GPIO_Port GPIOI
#define D29_Pin GPIO_PIN_7
#define D29_GPIO_Port GPIOI
#define D31_Pin GPIO_PIN_10
#define D31_GPIO_Port GPIOI
#define D28_Pin GPIO_PIN_6
#define D28_GPIO_Port GPIOI
#define LED4_Pin GPIO_PIN_3
#define LED4_GPIO_Port GPIOK
#define USART6_RX_Pin GPIO_PIN_9
#define USART6_RX_GPIO_Port GPIOG
#define LED2_Pin GPIO_PIN_4
#define LED2_GPIO_Port GPIOD
#define uSD_CMD_Pin GPIO_PIN_2
#define uSD_CMD_GPIO_Port GPIOD
#define D23_Pin GPIO_PIN_15
#define D23_GPIO_Port GPIOH
#define D25_Pin GPIO_PIN_1
#define D25_GPIO_Port GPIOI
#define USB_FS1_ID_Pin GPIO_PIN_10
#define USB_FS1_ID_GPIO_Port GPIOA
#define A1_Pin GPIO_PIN_1
#define A1_GPIO_Port GPIOF
#define D30_Pin GPIO_PIN_9
#define D30_GPIO_Port GPIOI
#define D21_Pin GPIO_PIN_13
#define D21_GPIO_Port GPIOH
#define D22_Pin GPIO_PIN_14
#define D22_GPIO_Port GPIOH
#define D24_Pin GPIO_PIN_0
#define D24_GPIO_Port GPIOI
#define VBUS_FS1_Pin GPIO_PIN_9
#define VBUS_FS1_GPIO_Port GPIOA
#define uSD_D1_Pin GPIO_PIN_9
#define uSD_D1_GPIO_Port GPIOC
#define A2_Pin GPIO_PIN_2
#define A2_GPIO_Port GPIOF
#define uSD_D0_Pin GPIO_PIN_8
#define uSD_D0_GPIO_Port GPIOC
#define A3_Pin GPIO_PIN_3
#define A3_GPIO_Port GPIOF
#define I2C2_SCL_Pin GPIO_PIN_4
#define I2C2_SCL_GPIO_Port GPIOH
#define SDCLK_Pin GPIO_PIN_8
#define SDCLK_GPIO_Port GPIOG
#define A4_Pin GPIO_PIN_4
#define A4_GPIO_Port GPIOF
#define I2C2_SDA_Pin GPIO_PIN_5
#define I2C2_SDA_GPIO_Port GPIOH
#define SDNE0_Pin GPIO_PIN_3
#define SDNE0_GPIO_Port GPIOH
#define SAI1_MCLKA_Pin GPIO_PIN_7
#define SAI1_MCLKA_GPIO_Port GPIOG
#define LED1_Pin GPIO_PIN_6
#define LED1_GPIO_Port GPIOG
#define QSPI_BK1_IO2_Pin GPIO_PIN_7
#define QSPI_BK1_IO2_GPIO_Port GPIOF
#define QSPI_BK1_IO3_Pin GPIO_PIN_6
#define QSPI_BK1_IO3_GPIO_Port GPIOF
#define A5_Pin GPIO_PIN_5
#define A5_GPIO_Port GPIOF
#define SDCKE0_Pin GPIO_PIN_2
#define SDCKE0_GPIO_Port GPIOH
#define D1_Pin GPIO_PIN_15
#define D1_GPIO_Port GPIOD
#define D15_Pin GPIO_PIN_10
#define D15_GPIO_Port GPIOD
#define QSPI_CLK_Pin GPIO_PIN_10
#define QSPI_CLK_GPIO_Port GPIOF
#define QSPI_BK1_IO1_Pin GPIO_PIN_9
#define QSPI_BK1_IO1_GPIO_Port GPIOF
#define QSPI_BK1_IO0_Pin GPIO_PIN_8
#define QSPI_BK1_IO0_GPIO_Port GPIOF
#define D0_Pin GPIO_PIN_14
#define D0_GPIO_Port GPIOD
#define D14_Pin GPIO_PIN_9
#define D14_GPIO_Port GPIOD
#define D13_Pin GPIO_PIN_8
#define D13_GPIO_Port GPIOD
#define SDNWE_Pin GPIO_PIN_0
#define SDNWE_GPIO_Port GPIOC
#define OTG_FS1_PowerSwitchOn_Pin GPIO_PIN_2
#define OTG_FS1_PowerSwitchOn_GPIO_Port GPIOB
#define A6_Pin GPIO_PIN_12
#define A6_GPIO_Port GPIOF
#define A11_Pin GPIO_PIN_1
#define A11_GPIO_Port GPIOG
#define A9_Pin GPIO_PIN_15
#define A9_GPIO_Port GPIOF
#define MIC_CK_Pin GPIO_PIN_13
#define MIC_CK_GPIO_Port GPIOD
#define uSD_Detect_Pin GPIO_PIN_2
#define uSD_Detect_GPIO_Port GPIOG
#define LCD_INT_Pin GPIO_PIN_5
#define LCD_INT_GPIO_Port GPIOJ
#define D20_Pin GPIO_PIN_12
#define D20_GPIO_Port GPIOH
#define WAKEUP_Pin GPIO_PIN_0
#define WAKEUP_GPIO_Port GPIOA
#define SPI1_CS_Pin GPIO_PIN_4
#define SPI1_CS_GPIO_Port GPIOA
#define A7_Pin GPIO_PIN_13
#define A7_GPIO_Port GPIOF
#define A10_Pin GPIO_PIN_0
#define A10_GPIO_Port GPIOG
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

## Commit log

2026-07-14 Add STM32CubeMX/CMake project with working IT8951 SPI display bring-up
    Generates the F469-Disco firmware project (CubeMX + CMake toolchain,
    FreeRTOS, HAL/CMSIS), vendors and adapts Waveshare's IT8951 driver for
    SPI over hspi1, and wires up VSCode build/flash/debug/serial-monitor
    tasks. Confirmed on hardware: SPI communication with the IT8951, VCOM
    set, and a test image rendered on the physical panel.
2026-07-15 Fix full-panel IT8951 writes (SDRAM buffer, overflow, nibble order); add A2 mode
    Routes the IT8951 frame buffer through the board's FMC/SDRAM (proven with a
    full 16MB read/write test, plus the JEDEC power-up sequence CubeMX doesn't
    generate on its own) and gets a full-panel 16-level grayscale gradient
    rendering correctly - confirmed by direct visual inspection, no artifacts.
    Getting there required finding and fixing three real bugs in the vendored
    IT8951 driver, in order of eventual impact:
    - The actual root cause: Source_Buffer_Length was a 16-bit UWORD in every
    HostAreaPackedPixelWrite_* function, silently overflowing for a full-panel
    transfer (388064 words) and truncating writes to ~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
    [main.c, stm32-epaper.ioc]
2026-07-15 Add SD card storage (SDIO+FatFS) and CubeMX regen self-healing
    Storage milestone:
    - Enable SDIO DMA (DMA2_Stream3) and NVIC interrupt via CubeMX GUI so
    BSP_SD_ReadBlocks_DMA/WriteBlocks_DMA (used by sd_diskio.c) actually work;
    CubeMX had generated FatFS/SDIO glue but never wired up the DMA channel or
    interrupt it depends on.
    - Add SD mount/write/read round-trip test in main.c: f_mount, f_getfree,
    f_open/f_write/f_close, then f_open/f_read to verify. Uses EPTEST.TXT
    (8.3-compatible) since ffconf.h has _USE_LFN=0 and longer names fail with
    FR_INVALID_NAME.
    - Prefix all printf output with HAL tick timestamps for easier log
    correlation (timestamped_printf wrapper in main.c).
    CubeM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
    [main.c, stm32-epaper.ioc]
2026-07-15 Add font rendering and page layout (word wrap + pagination)
    Font rendering, first pass:
    - Vendor ST BSP's plain sFONT bitmap fonts (font8/12/16/20/24.c, 1bpp,
    fixed-width, no AA) from the companion LVGL demo repo into Drivers/Fonts/,
    plus a minimal glyph-blit routine (EPD_Text_DrawChar/DrawString in the new
    EPD_Text.c/h) that packs into the 4bpp SDRAM framebuffer. Confirmed on
    hardware, but these fonts were designed for small low-res TFTs and render
    physically tiny at this panel's ~300 PPI - not a comfortable reading size.
    Proper anti-aliased fonts:
    - Add tools/gen_font.py: rasterizes a real TTF/OTF via Pillow at a given
    pixel size, quantizes Pillow's 8-bit AA coverage down to 4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
    [main.c]
2026-07-15 Add SD directory listing + long filenames, remove boot-time demo blocks
    Directory listing:
    - List the SD card's root directory (f_opendir/f_readdir/f_closedir) right
    after mount, so what's actually on the card is visible in the serial log
    without pulling it - confirmed a real EPUB copied on via a card reader.
    Long filename support:
    - Set _USE_LFN=3 in ffconf.h (heap-based working buffer - the only one of
    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
2026-07-15 Add CLAUDE.md and refresh README for context handoff to other agents
    CLAUDE.md: lean, auto-loaded pointer to README.md/TODO.md plus the working
    conventions that have actually mattered in this repo (hardware validation
    required before calling something done, commit only when asked, CubeMX
    regeneration self-healing via scripts/patch-cubemx.sh, native-test-before-
    hardware for parser/algorithm code). Deliberately doesn't duplicate
    README/TODO content, to stay cheap to load every session.
    README.md: fixed real staleness - it still described the project as
    "bare-metal, no RTOS" (wrong, FreeRTOS is in use) and "Display bring-up
    milestone" as the current status, with no mention of fonts, page layo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
2026-07-16 Add concrete hardware iteration commands to CLAUDE.md
    Fills a real gap: the previous CLAUDE.md mentioned "minicom -C" and
    "ffmpeg -f v4l2" existed but deferred the actual invocations to "recent
    commits/TODO.md", which just sends a fresh agent hunting. Adds a
    copy-pasteable "Iterating on hardware changes" section: confirm the
    ST-LINK is enumerated, build+flash+verify, find/read the already-running
    minicom log (including that the per-boot ms-since-reset prefix is the
    reliable way to find where the latest boot starts in an append-only log),
    and the exact webcam capture invocation (multi-frame + frame-select to
    let auto-exposure settle).
    C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
2026-07-16 Add hardware lock for multiple concurrent agents
    scripts/hw-lock.sh: an flock-based mutex wrapping any command that touches
    the single physical board (flashing, starting minicom, a webcam capture),
    shared across every git worktree on the machine via a lock file in /tmp
    (deliberately outside the repo, since worktrees are separate directories
    but all share the same hardware). A second agent trying to flash while
    another holds the lock waits instead of racing OpenOCD against another
    instance.
    Tested before relying on it: two concurrent invocations correctly
    serialize; a kill -9 on the lock holder releases the lock immediately.
    That second case took a real fix - the first version ran the wrappe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
2026-09-22 Fix heap-unsafe malloc/free in EPD_IT8951_Clear_Refresh
    Bring it in line with every other *_Refresh function's convention of
    taking a caller-supplied Frame_Buf, since this project's newlib/FreeRTOS
    integration has no heap locking wired up and concurrent malloc/free from
    more than one task would risk corrupting the heap.
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2026-09-23 Add KiCad project with drafted Power sheet; record BoM review
    - hardware/kicad: KiCad 10 project, root sheet + power.kicad_sch (USB-C sink
    + ESD, MCP73123 LFP charger, AN1149 load sharing, TPS63802 3V3 buck-boost
    with EN-divider undervoltage cutoff, TPS61023 5V for the external HAT,
    RTC backup diode, reserved DNP TPS63900 always-on rail and TPS22965
    load switch). Project-local symbols with datasheet-sourced pinouts.
    - hardware/scripts: bootstrap generator + check_power_netlist.py (ERC +
    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
    [power.kicad_sch, stm32-epaper.kicad_sch]
2026-09-23 Add TPS63802 DLA0010A footprint (project library)
    hardware/kicad/epaper.pretty: VSON-HR 10 (2x3 mm HotRod) land pattern
    transcribed from the TPS63802 datasheet (SLVSEU9D pp. 35-37), including the
    split paste apertures on the pin-8 GND bar (83% coverage). Generated by
    hardware/scripts/gen_footprints.py; assigned to U2 via a project
    fp-lib-table. ERC 0 violations, power netlist check 34/34.
    [power.kicad_sch, stm32-epaper.kicad_sch]
2026-09-23 Add MCU, Memory and Peripherals sheets; whole-schematic checker
    - MCU (A2): STM32F469IIT6 LQFP176. Pin assignment lives in
    sheet_mcu.PINMAP and follows the F469-Disco (FMC SDRAM now 16-bit, QSPI,
    SDIO, SPI1 + HAT control pins, USART3 log UART, I2C1) so the firmware
    config carries over. SD card-detect moved PG2 -> PG10 to keep EXTI2 for
    HRDY. DS11189 power scheme: 13x100nF + 4.7uF, VDDUSB, ferrite-fed
    VDDA/VREF+, 2x2.2uF VCAP; DSI unused per DS11189 2.18 (VDDDSI->VDD,
    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
    [mcu.kicad_sch, memory.kicad_sch, peripherals.kicad_sch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]
2026-09-23 Finish v1 schematic: rail test points, docs, deterministic generation
    - Power sheet: test points on VBUS/VSYS/+BATT/+3V3/+5V/GND for bring-up;
    R13/R18 0R links (carry all peripheral / MCU current on v1) 0402 -> 0603.
    - kicad_gen: UUIDs derived deterministically per sheet (uuid5 of sheet +
    item order), so regenerating produces diffs only where the design changed.
    - README: status, pin-assignment table, MCU/memory/peripheral decisions,
    "Checking the Schematic", repo layout. TODO: schematic marked drafted,
    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
    [mcu.kicad_sch, memory.kicad_sch, peripherals.kicad_sch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]
2026-09-23 TODO: add enclosure, fab/ordering, bring-up, persistence and USB MSC items
    Roadmap items that were missing: mechanical/enclosure (gates layout),
    fabrication outputs and ordering, a staged custom-board bring-up phase,
    reading-position persistence, and USB mass-storage for loading books.
2026-09-23 Switch battery chemistry from LiFePO4 to 1-cell LiPo pouch
    Small flat LFP pouches aren't practically buyable in the US; protected LiPo
    pouches with JST-PH leads are stocked everywhere.
    Power sheet:
    - MCP73123 (3.6 V LFP) + discrete AN1149 load sharing (D1/Q1/R5) ->
    TI BQ24073: 4.2 V CV, power path with OUT (VSYS) regulated to 4.4 V so
    the 5.5 V-max TPS63802/TPS61023 stay safe, USB500 input limit, ~500 mA
    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
    [mcu.kicad_sch, power.kicad_sch]
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2026-09-23 Finalize charger for the chosen EEMB cells; battery bay dimensions
    From EEMB's LP963450-PCM-LD pack spec and LP603449 cell spec:
    - Charge current 500 mA -> ~296 mA (ISET 3.01k, 265-324 mA worst case):
    <= 0.3C of the 1100 mAh cell, EEMB's limit for charging at 0-20 C.
    - TMR 72k: fast-charge timer 7.2-12 h (default 4-6 h would expire on the
    1800 mAh cell at ~300 mA).
    - Cells allow charging only at 0-45 C; the BQ24073 window is ~0-50 C and TI's
    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
    [mcu.kicad_sch, power.kicad_sch]
2026-09-23 Fit the TPS22965 peripheral load switch on v1
    Without it SDRAM/QSPI/microSD stay powered in STANDBY (~2-20 mA idle floor,
    ~70 mAh/day); with it idle drops to ~0.5-2 mAh/day.
    - U4 TPS22965 populated; R13 0R bypass -> DNP (fallback).
    - R14 100k pull-down on PERIPH_EN (PD7) fitted: rail off at reset and
    automatically in STANDBY (GPIO hi-Z).
    - C14 CT 1 nF, 25 V X7R (CT pin reaches 12 V): ~1.3 ms rise at 3.3 V
    (datasheet Table 1) -> ~50 mA inrush into ~21 uF of downstream decoupling.
    - README/TODO: decision, firmware sequencing rules (enable before
    FMC/QSPI/SDIO init; pins to analog/low before disabling; re-init SDRAM and
    re-mount SD on wake), TPS63900 remains the only v2 reservation.
    E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
    [power.kicad_sch]
2026-09-23 Add v0 parametric enclosure model (build123d)
    hardware/enclosure/: a build123d model of the reader's enclosure, built
    and checked headless. params.py holds every dimension tagged by source
    (datasheet/README, placeholder to measure, or design choice); model.py
    builds the bought-in part envelopes and four MJF PA12 parts (front shell,
    panel backer, back cover, knob); checks.py runs pairwise interference,
    wall rules, knob engagement and plug/card opening checks; build.py exports
    STEP/STL/3MF, the PCB outline DXF and a placement JSON for layout, plus
    headless PNG renders. show.py sends the model to an OCP viewer.
    v0 is 106.8 x 171.4 x 17.8 mm, portrait, FPC at the top. The PEC11R is
    vertical-mou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
2026-09-23 Apply enclosure decisions: bottom-edge power button, electrode boards, leaded NTC
    Decisions (2026-09-23): keep the HAT's 2x20 header for v1; move the power
    button to the bottom edge; put the side-wall electrodes on two small
    boards; keep the front-face knob; put RT1 on leads to the cell.
    Schematic (via the generator scripts, check_schematic.py passes):
    - SW302: Alps SKRTLAE010 side-actuated switch on the PCB's bottom edge.
    - E301-E304 test pads -> J302/J303 JST-SH 3-pin (touch / GND / touch),
    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
    [peripherals.kicad_sch, power.kicad_sch, stm32-epaper.kicad_sch]
2026-09-24 Electrode board project, open hardware TODOs, main PCB bootstrap
    - hardware/electrode/: side-wall electrode board (one design, two fitted),
    generated by gen_electrode.py (schematic, pad footprint) and
    gen_electrode_pcb.py (board, via KiCad's pcbnew Python) from the
    enclosure's params.py. ERC/DRC/parity clean.
    - Datasheet values replace most enclosure placeholders. The encoder is now
    PEC11R-4220F-S0024 (20 mm shaft): the M7 bushing left the 15 mm shaft
    too short for the knob. Knob redesigned around the bushing.
    - Schematic: TPD4E05U06 ESD on the electrode lines, HRDY 100k pull-down,
    crystals chosen (NX3225GD 8 MHz / NX3215SA 32.768 kHz) with recomputed
    load caps, all inductors D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
    [electrode.kicad_pcb, electrode.kicad_sch, mcu.kicad_sch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]

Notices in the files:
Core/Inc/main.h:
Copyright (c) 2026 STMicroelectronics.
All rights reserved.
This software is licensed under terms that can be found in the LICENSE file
